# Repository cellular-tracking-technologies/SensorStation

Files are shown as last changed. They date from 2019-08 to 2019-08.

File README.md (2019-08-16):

# SensorStation

This repo contains the SensorStation schematics and CAD files. You can use this to assist with development, troubleshoot problems, or even create your own SensorStation.

If you are looking to purchased a fully assembled and tested SensorStation, complete with Raspberry Pi Compute module installed, visit: http://store.celltracktech.com/

# SensorStation Overview

The SensorStation is a powerful platform for transmitting and receiving information wirelessly, with multiple radio channels.

While its primary function is to collect data from wildlife telemetry devices, it can be used for any multi-channel wireless
application, including IoT, amateur radio, and building wireless networks.

The SensorStation offers the following features:

* Support for the Raspberry Pi Compute Module CM3+ (pre-programmed with SensorGnome if purchased from CTT)
* USB OTG switch allows for programming of Compute Module while directly connected to board
* GPS receiver with built in chip antenna, with RF switch for external antennas
* 5 radio channels with SMA connectors featuring the HopeRF footprint, making it compatible with VHF and UHF systems, such as LoRa or FSK, from 142-1000MHz and 2.4GHz
* Each radio is controlled by a dedicated Atmel AVR 32U4, featuring the Arduino bootloader, hardwired to the USB network
* Raspberry Pi compatible header for connecting accessories, such as the InkyPhat eInk screen and more
* 4 directional buttons
* 2 status indication LEDs controlled by GPIO
* 3 I2C accessory ports, with dedicated GPIO per port
* Multi-channel ADC, for measuring system voltages, temperature, light levels, battery voltage, solar voltage, and additional channels broken out
* DS3231 real time clock with extreme accuracy along with coin cell slot
* Composite video output
* Wide range DC power input from 8-24VDC
* 6 USB 2.0 ports, each with dedicated transaction translator, typically used for Software Defined Radio (SDR)
* SIM800C quad band GSM modem
* eSIM (SIM on chip), soldered on if purchased from CTT (requires data plan)

# SensorStation Acessories

Also available for a variety of SensorStation accessories. You can even build your own. Check our our SensorStation Acessory Template to learn more.

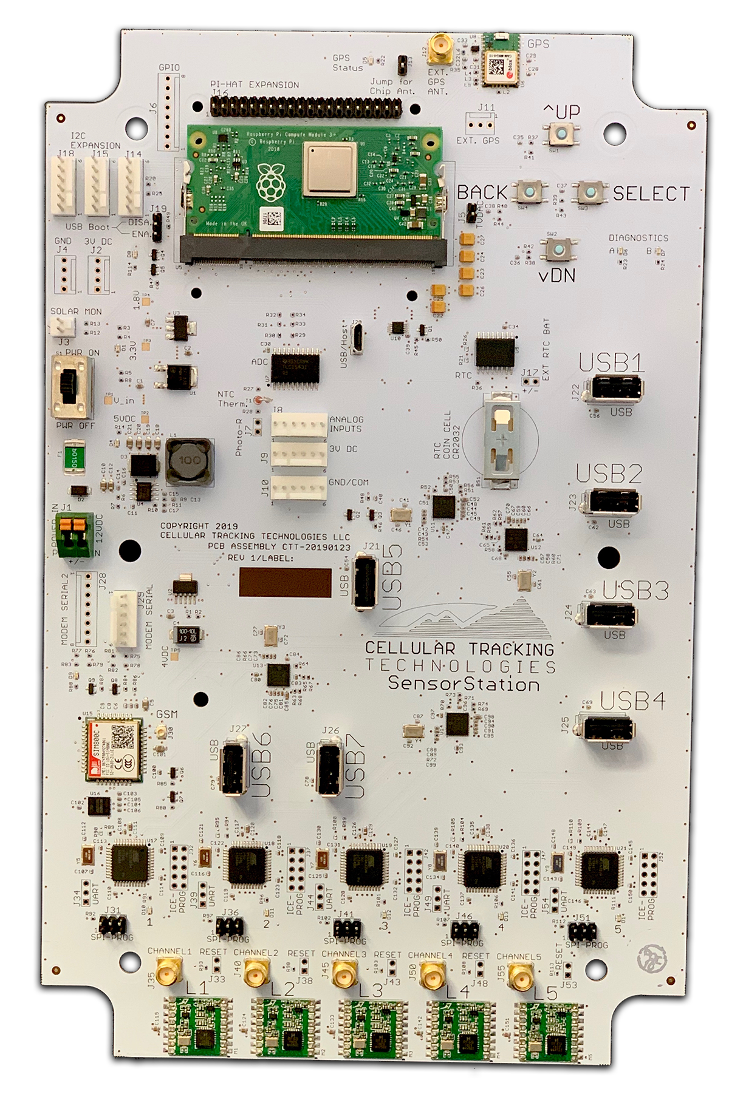
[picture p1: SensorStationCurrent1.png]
SensorStation


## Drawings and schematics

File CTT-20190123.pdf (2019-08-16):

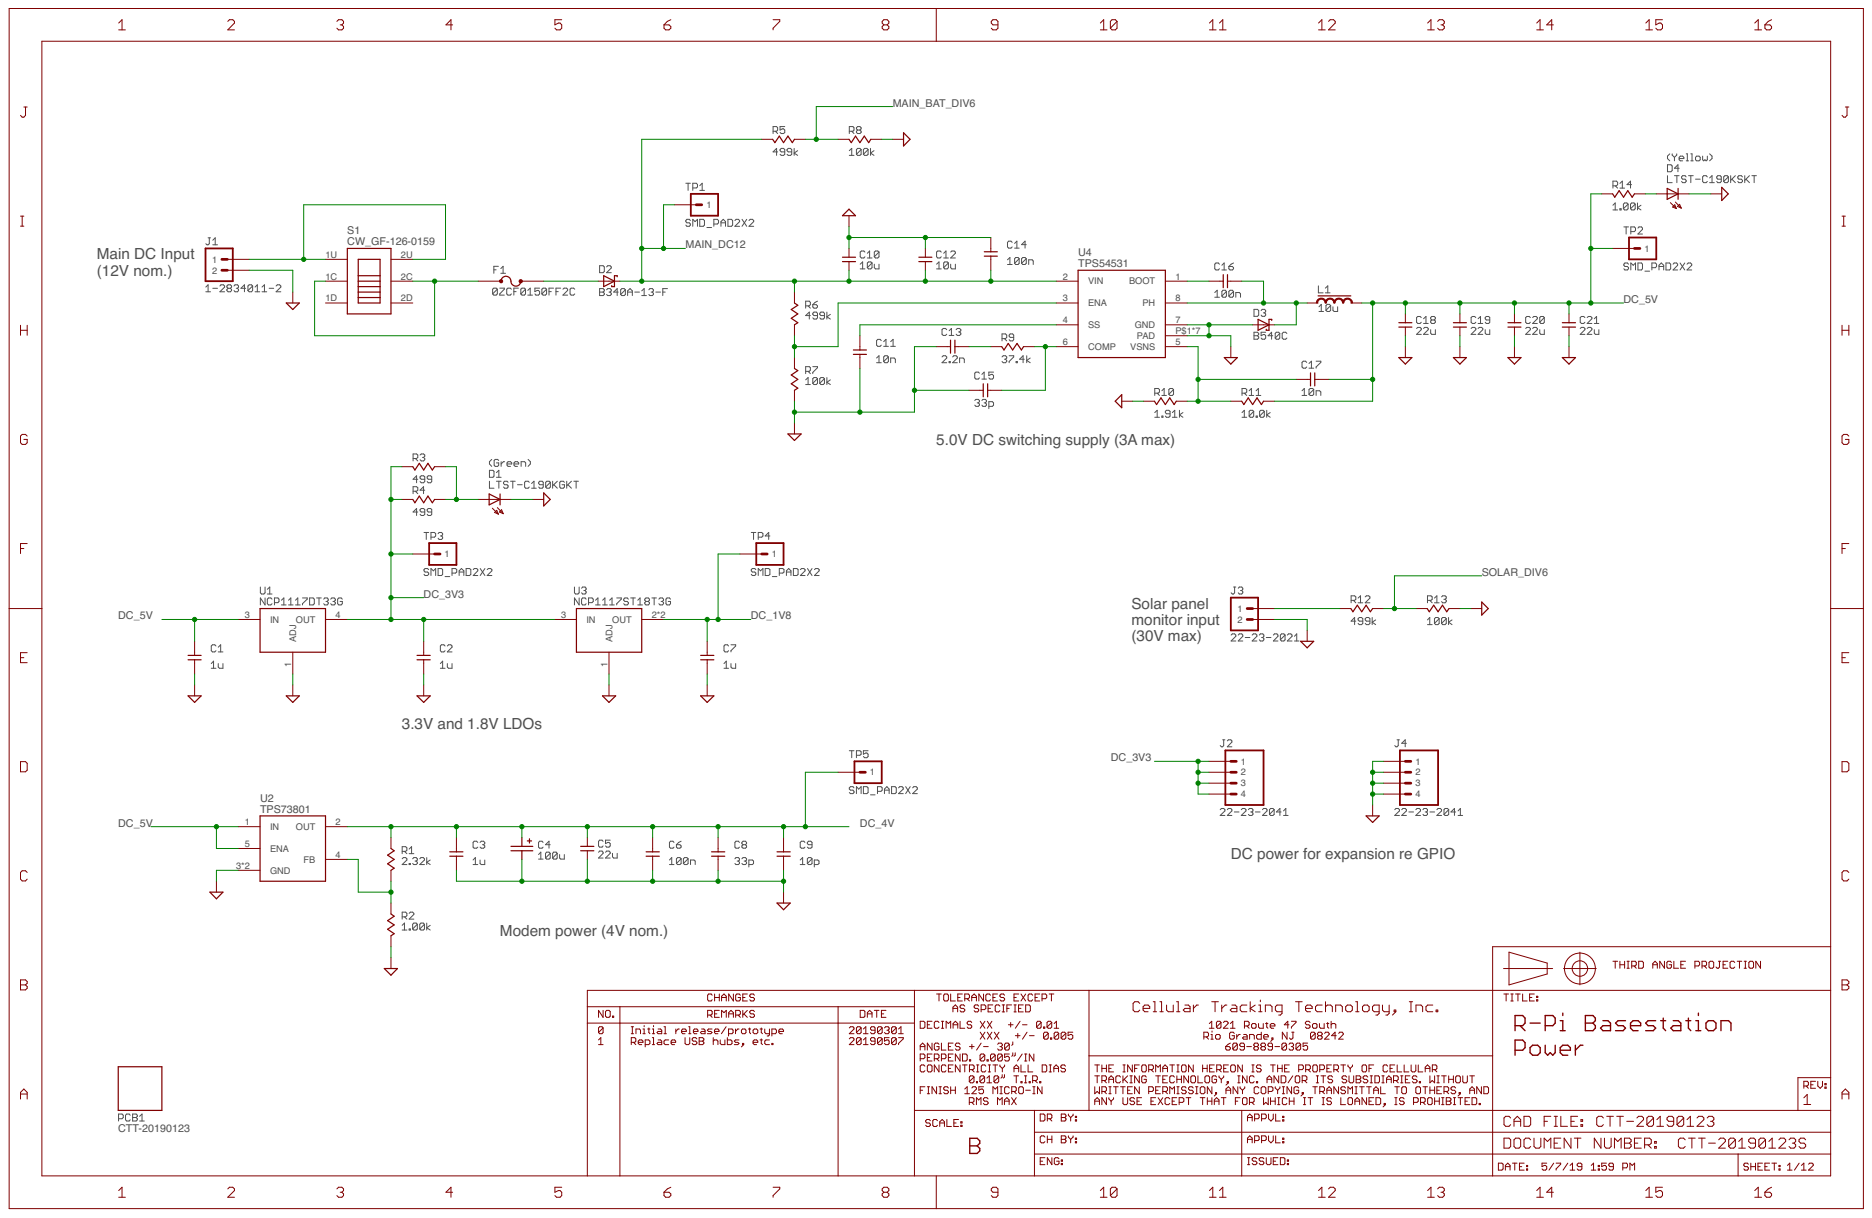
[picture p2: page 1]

Main DC Input (12V nom.)

5.0V DC switching supply (3A max)

Solar panel monitor input (30V max)

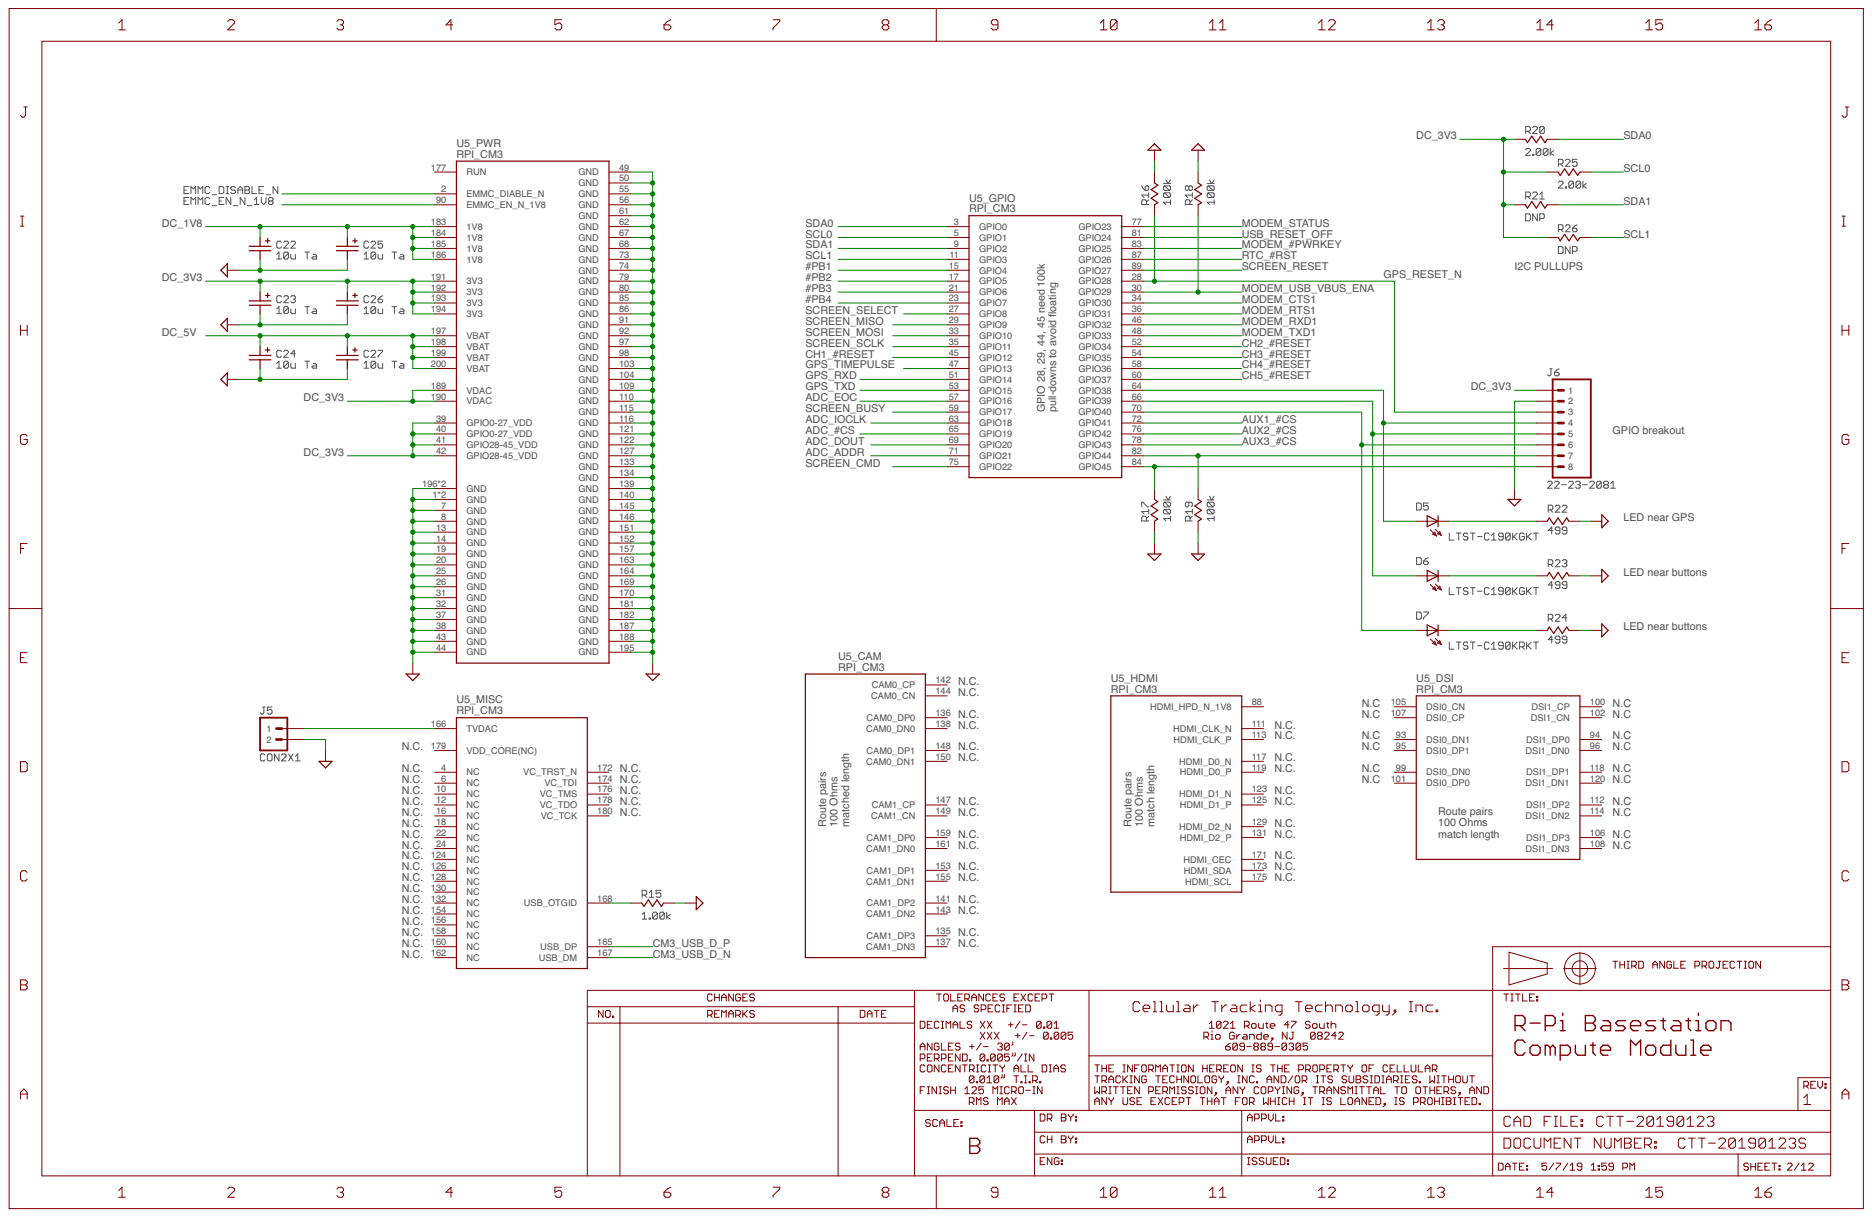
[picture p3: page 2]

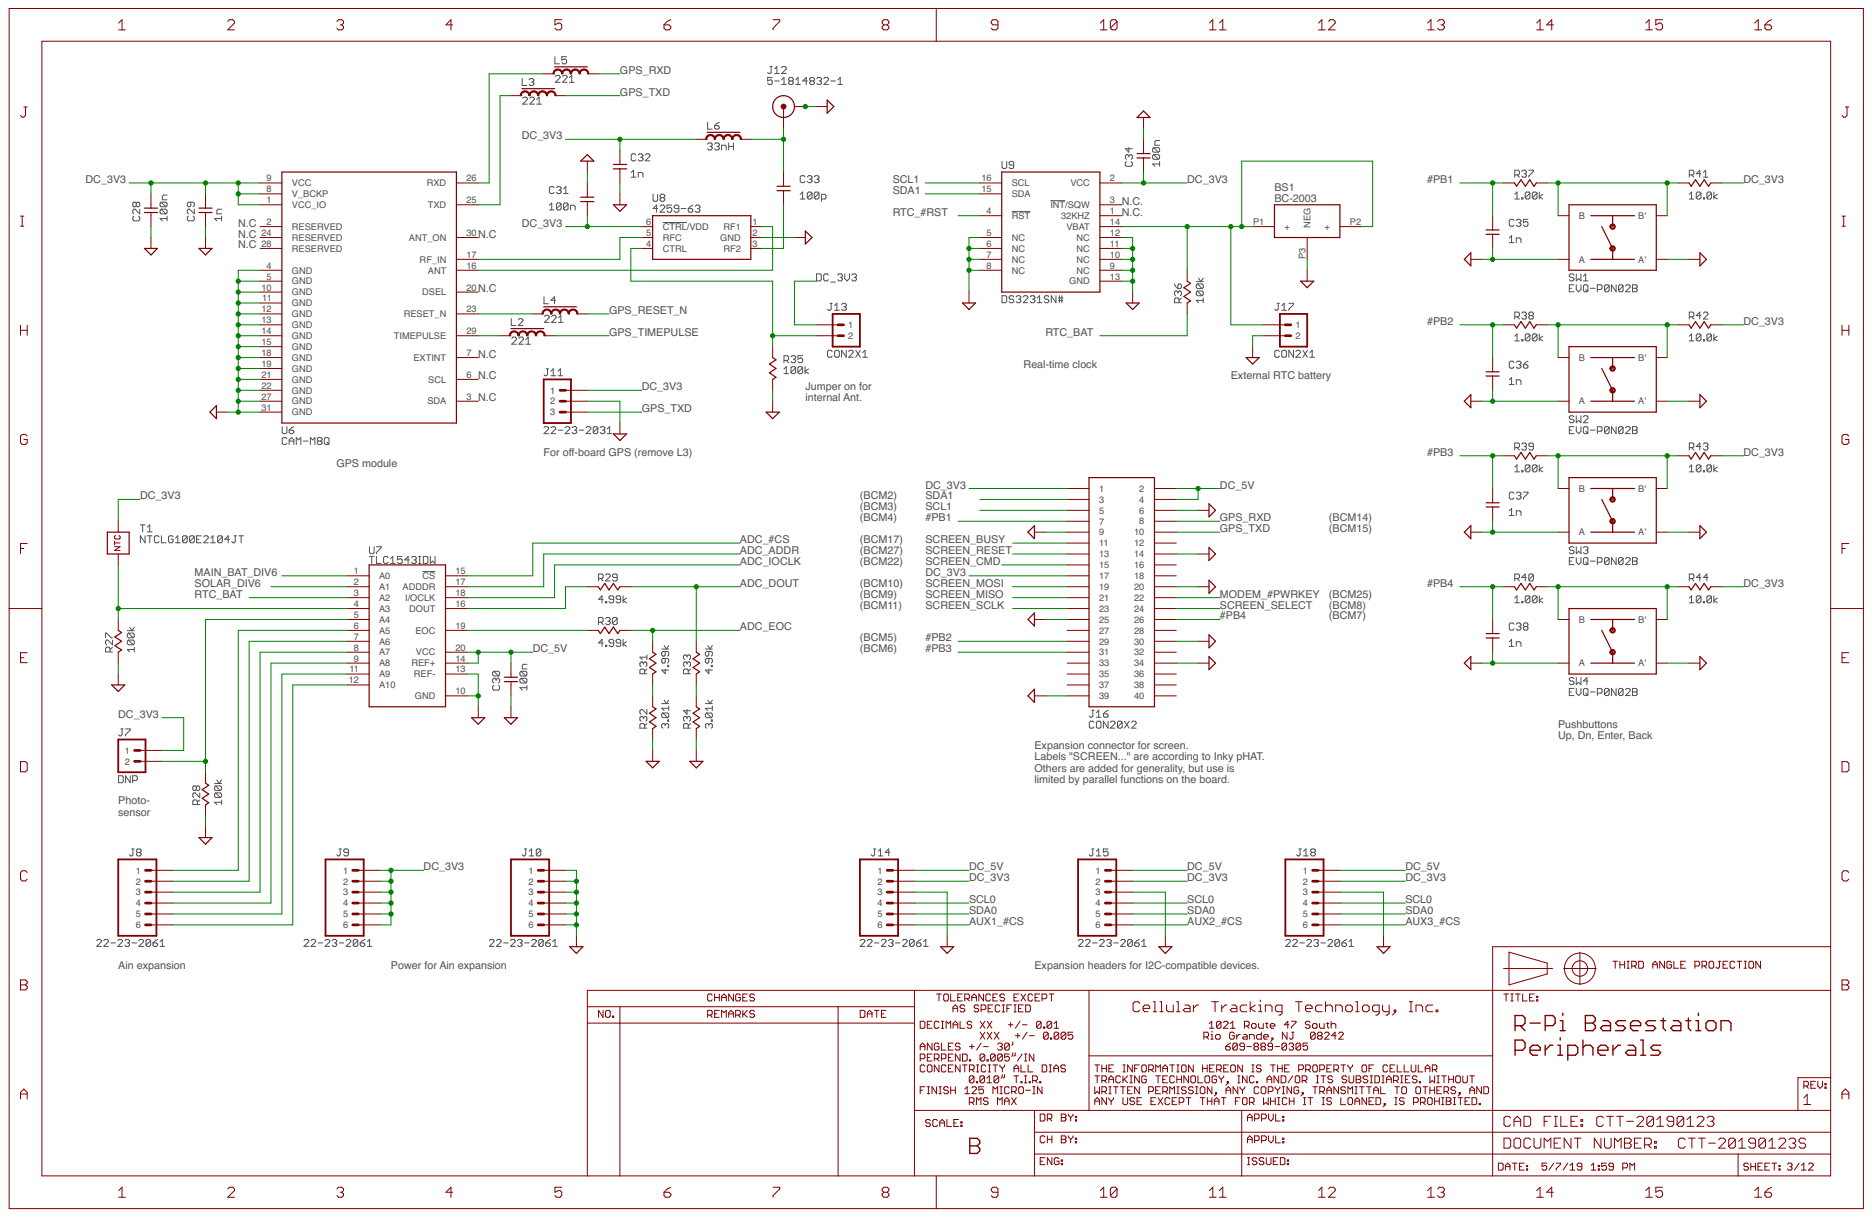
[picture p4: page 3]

For off-board GPS (remove L3) GPS module

Pushbuttons Up, Dn, Enter, Back

Expansion connector for screen. Labels "SCREEN..." are according to Inky pHAT. Others are added for generality, but use is

limited by parallel functions on the board.

Expansion headers for I2C-compatible devices.

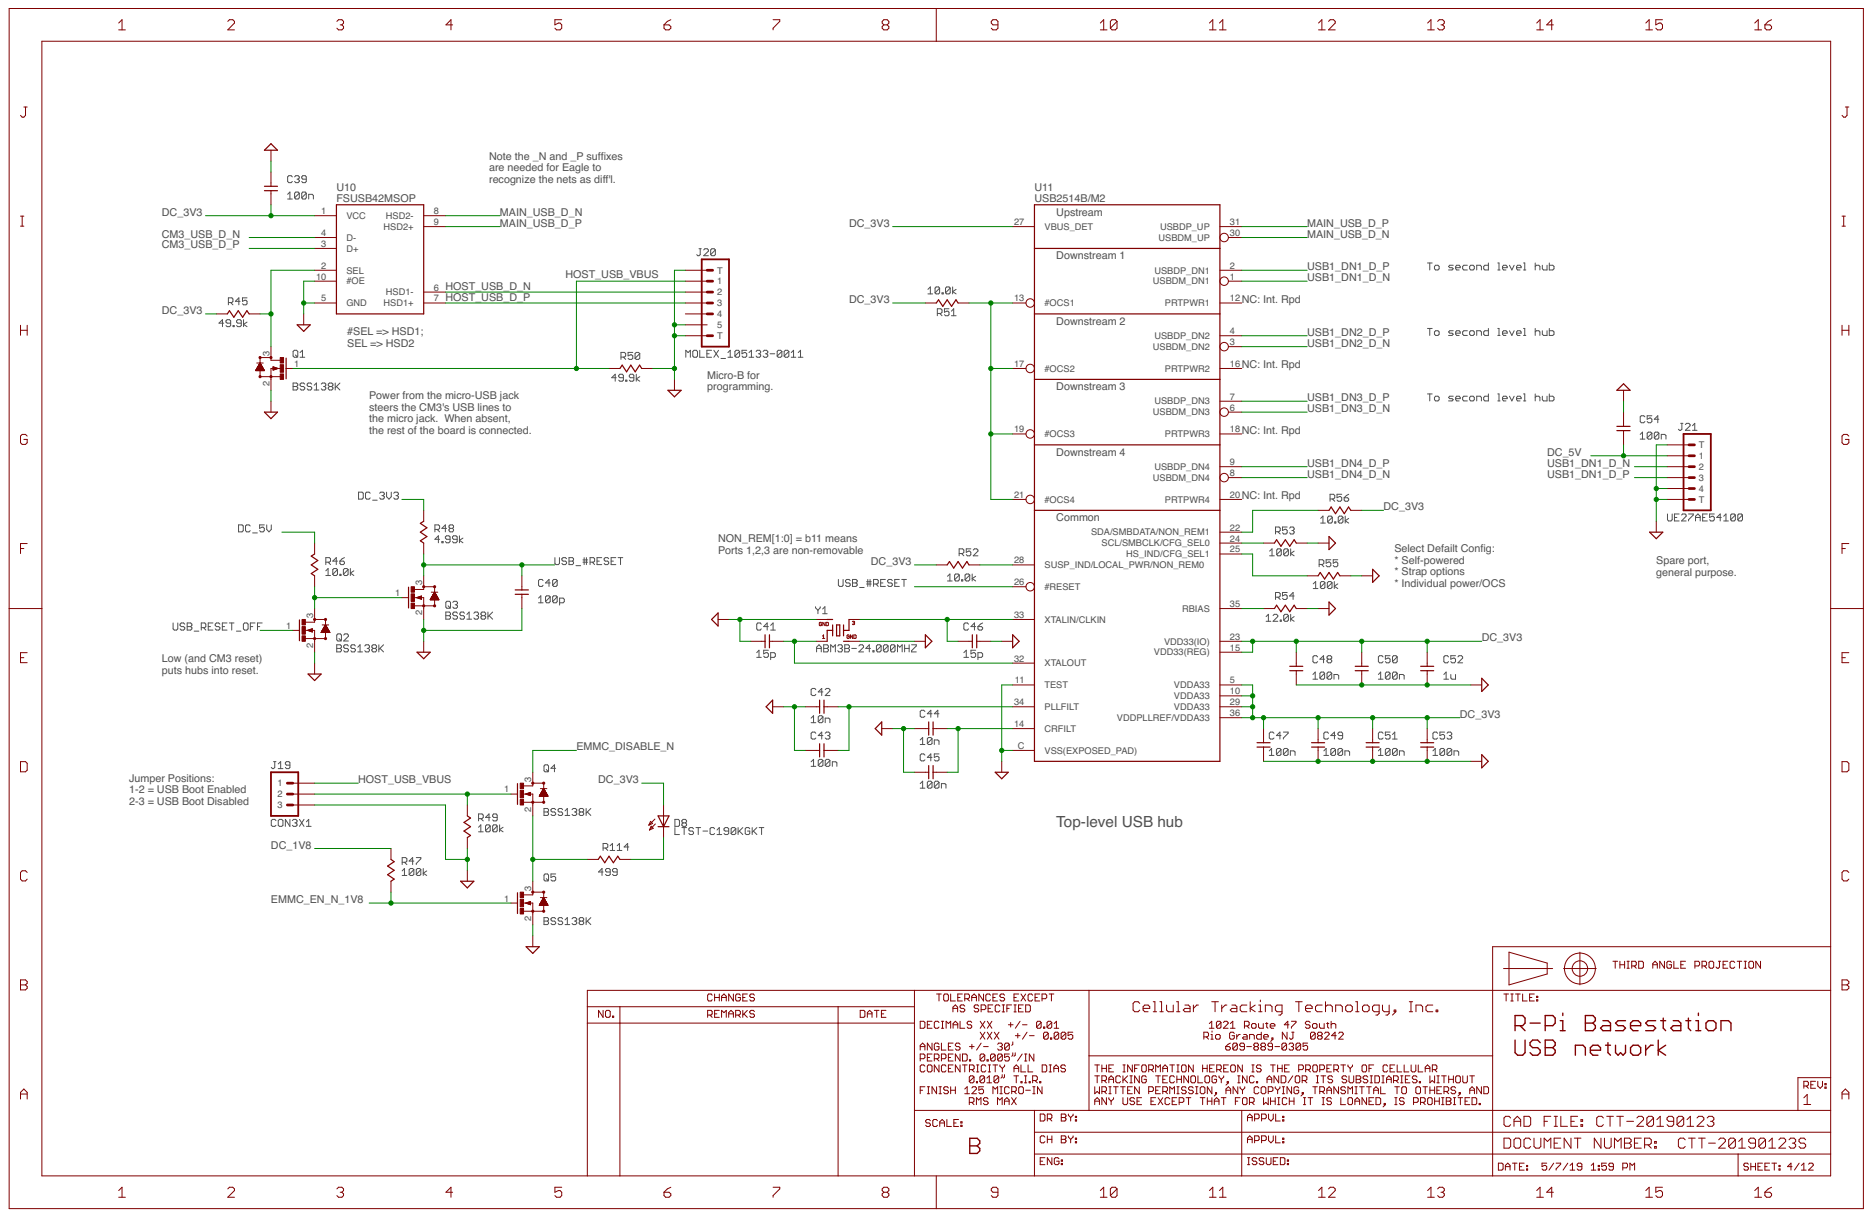
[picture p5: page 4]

Note the _N and _P suffixes are needed for Eagle to

Power from the micro-USB jack
steers the CM3's USB lines to
the micro jack. When absent,
the rest of the board is connected.

* Individual power/OCS NON_REM[1:0] = b11 means Ports 1,2,3 are non-removable

Spare port, general purpose.

Low (and CM3 reset) puts hubs into reset.

Jumper Positions: 1-2 = USB Boot Enabled

Top-level USB hub

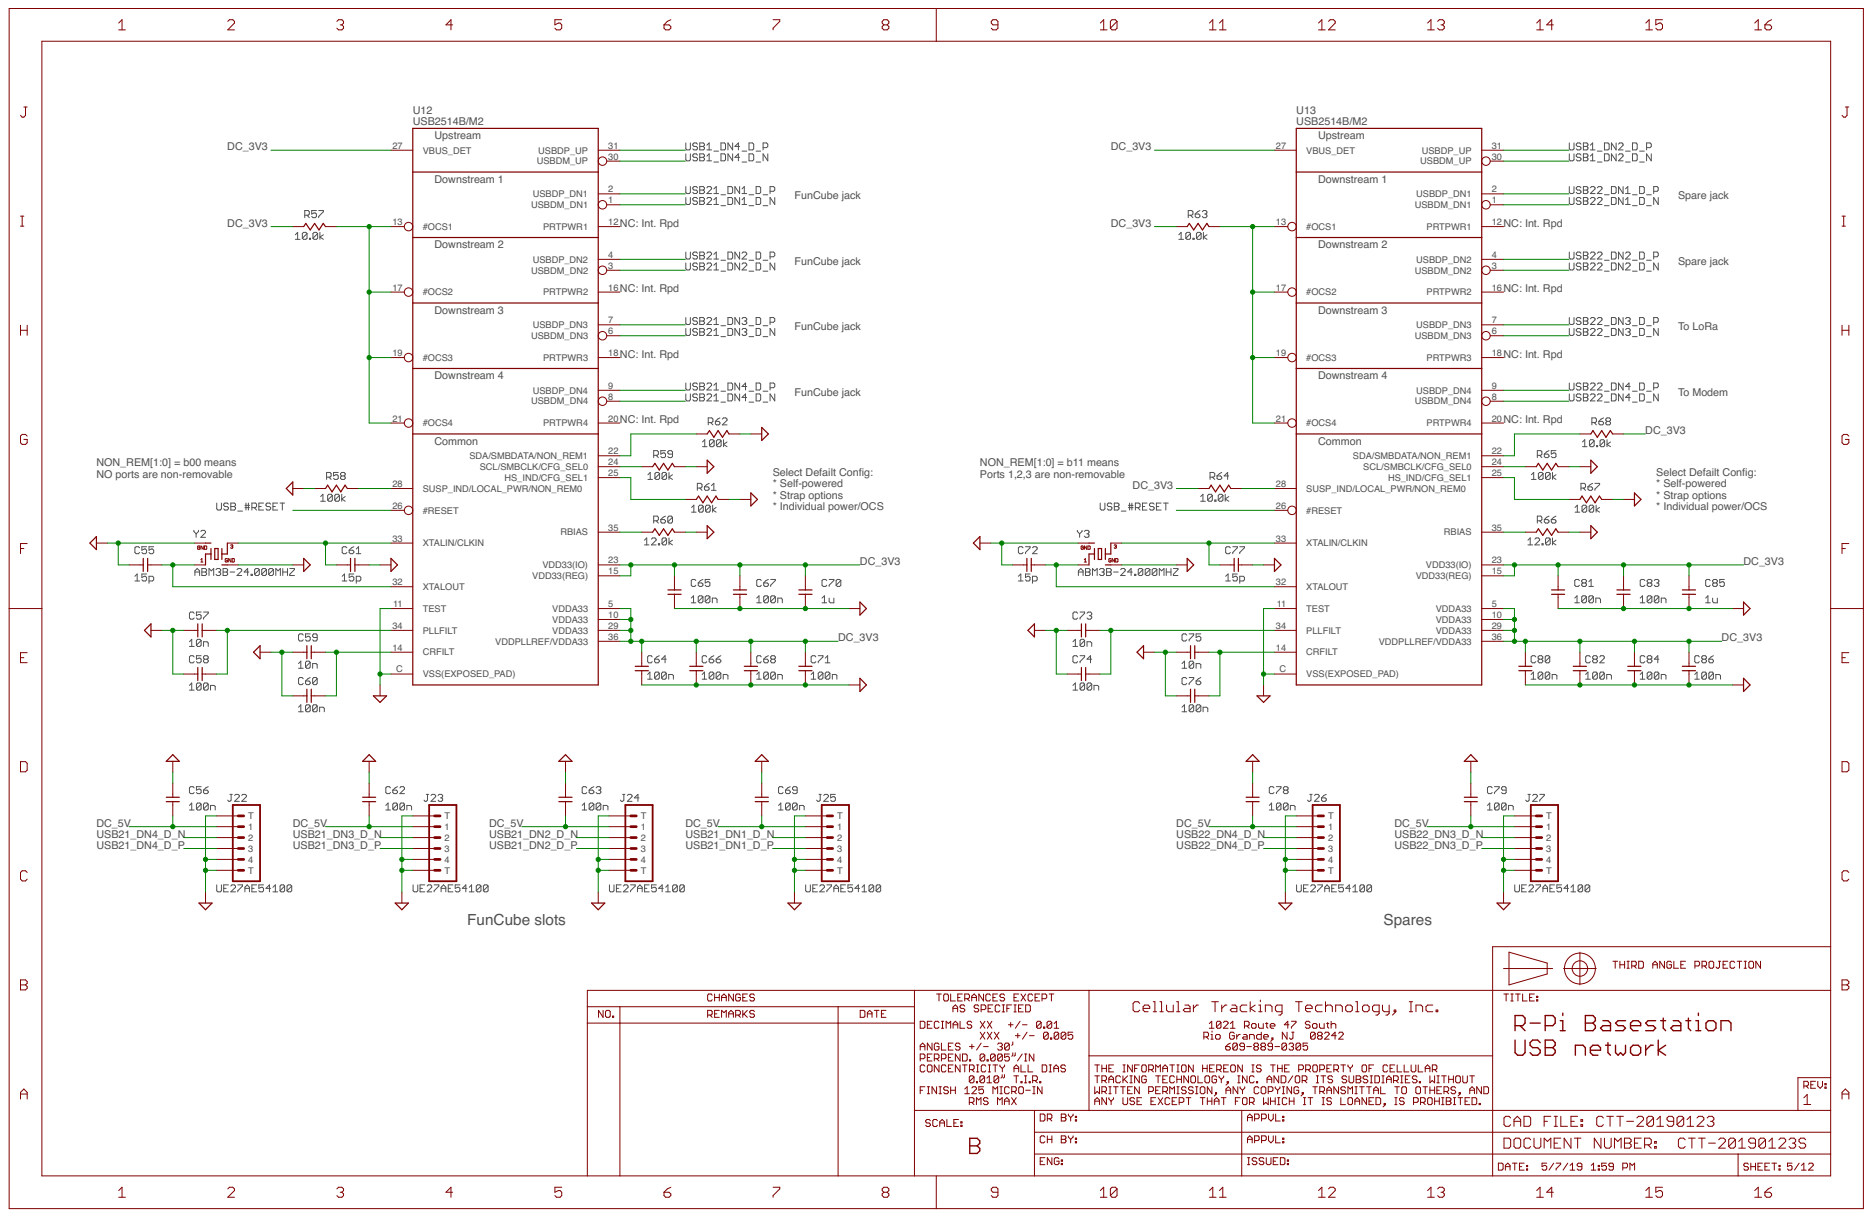
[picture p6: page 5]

Downstream 1 Downstream 2 Downstream 3 Downstream 4

* Individual power/OCS NON_REM[1:0] = b00 means NO ports are non-removable

* Individual power/OCS NON_REM[1:0] = b11 means Ports 1,2,3 are non-removable

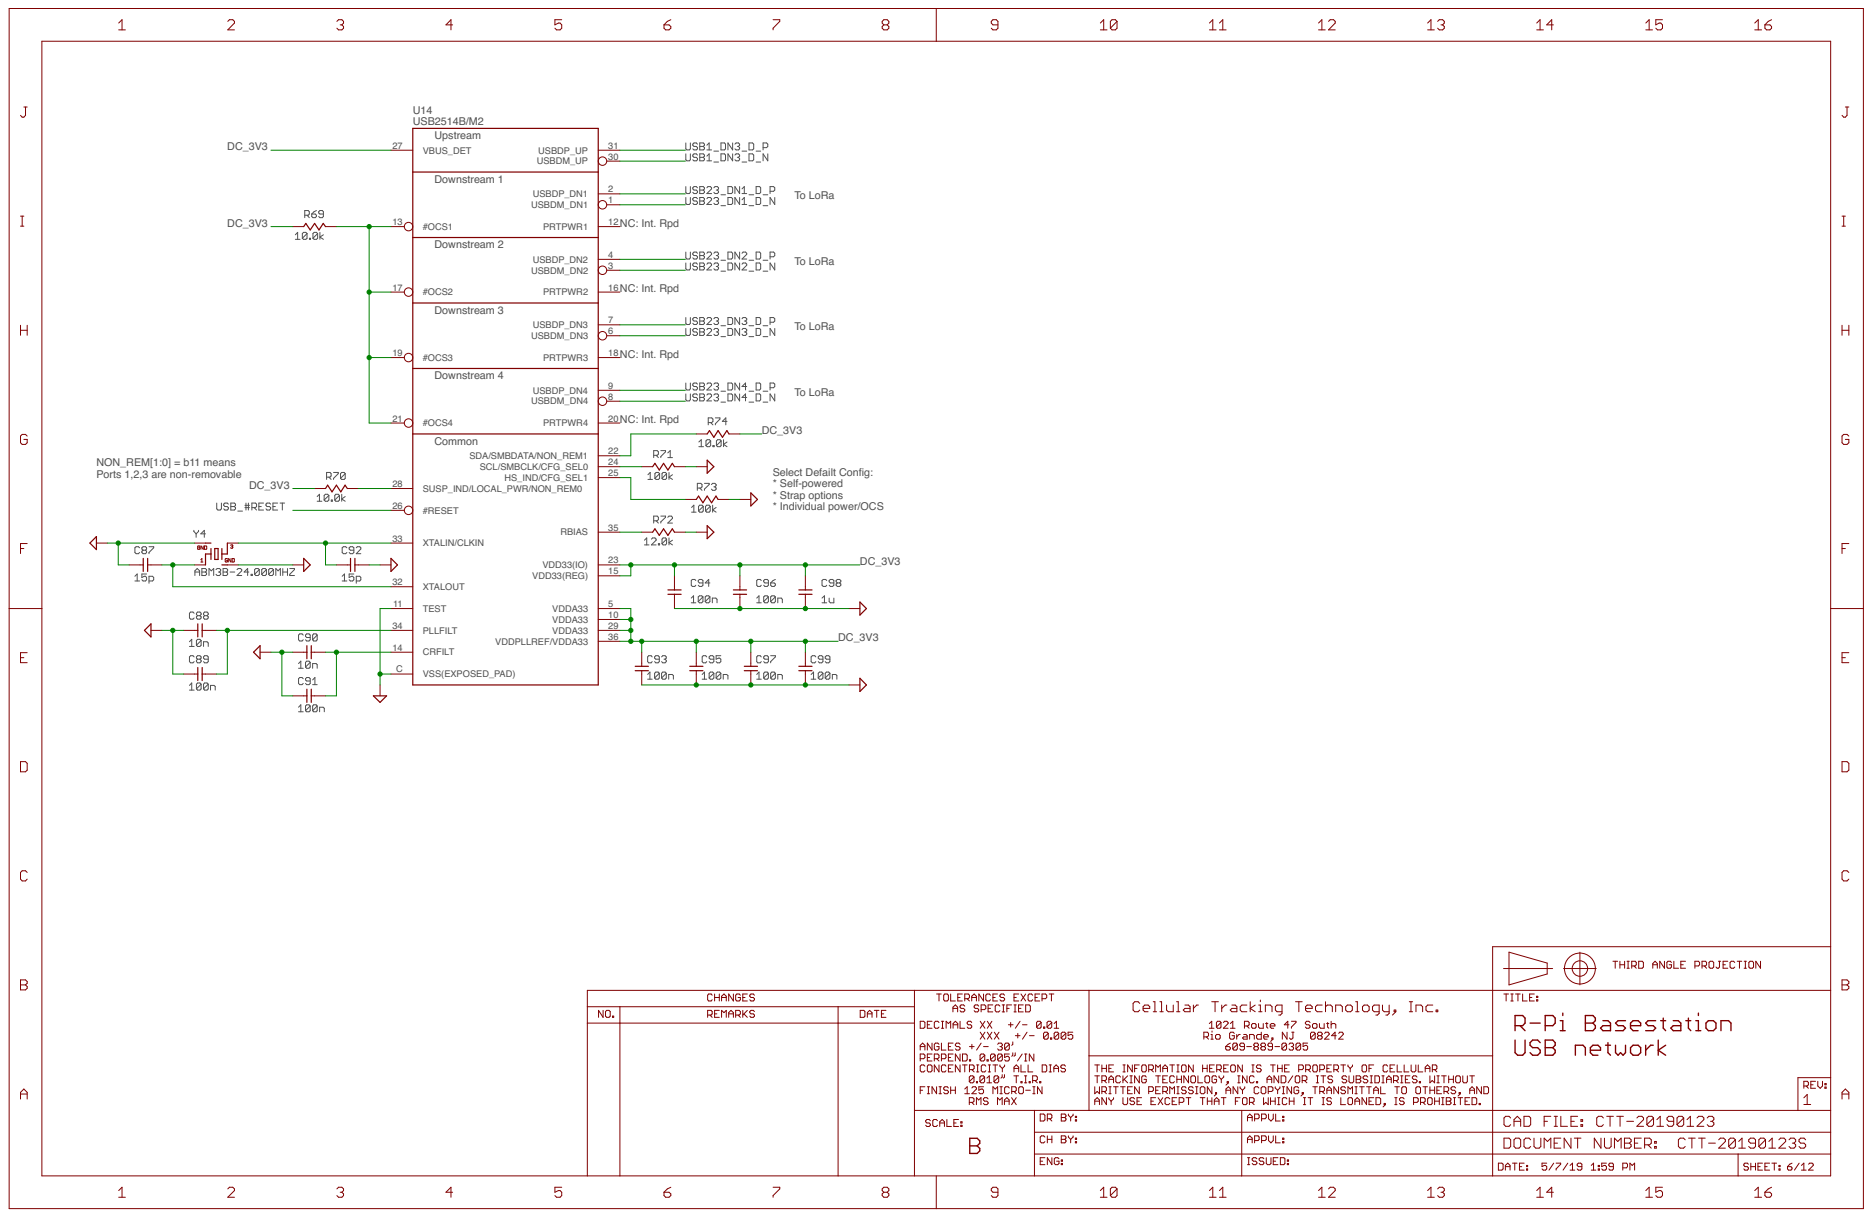
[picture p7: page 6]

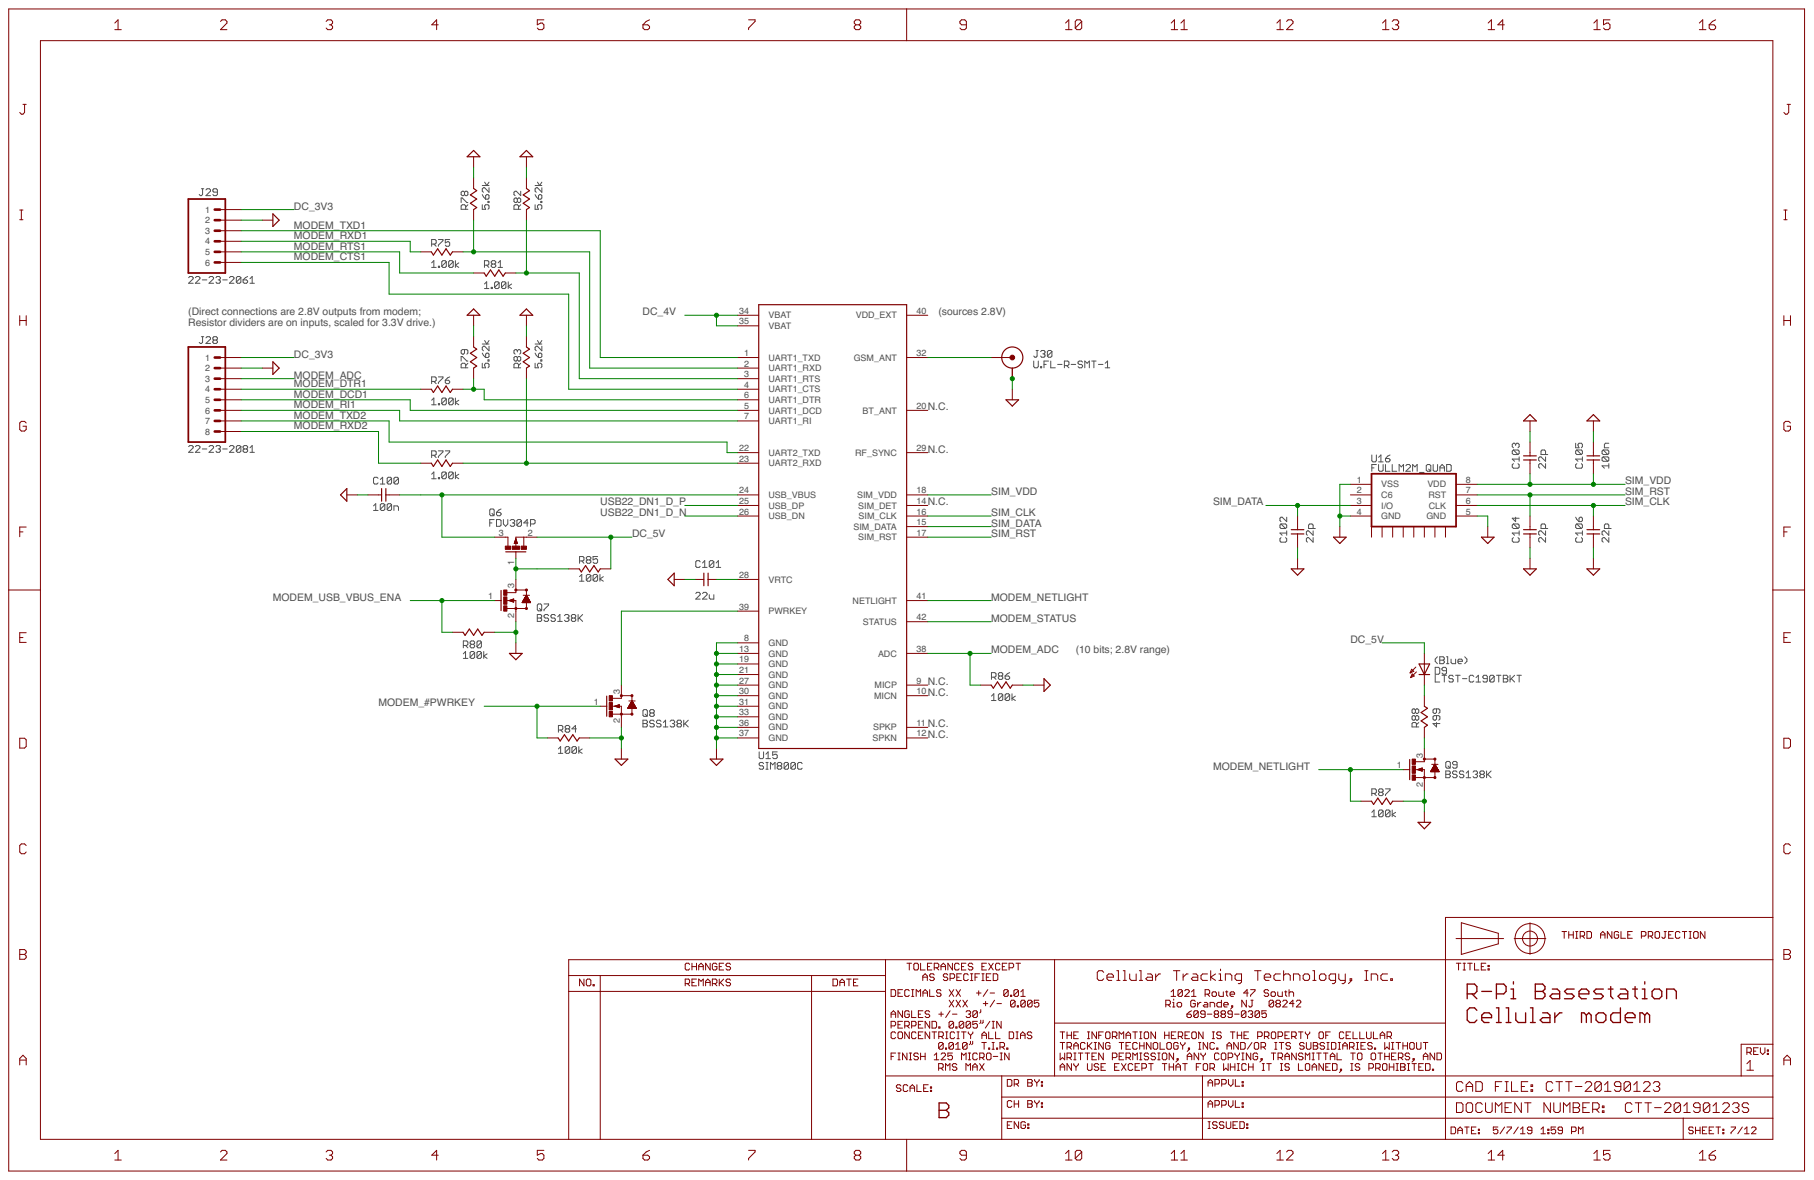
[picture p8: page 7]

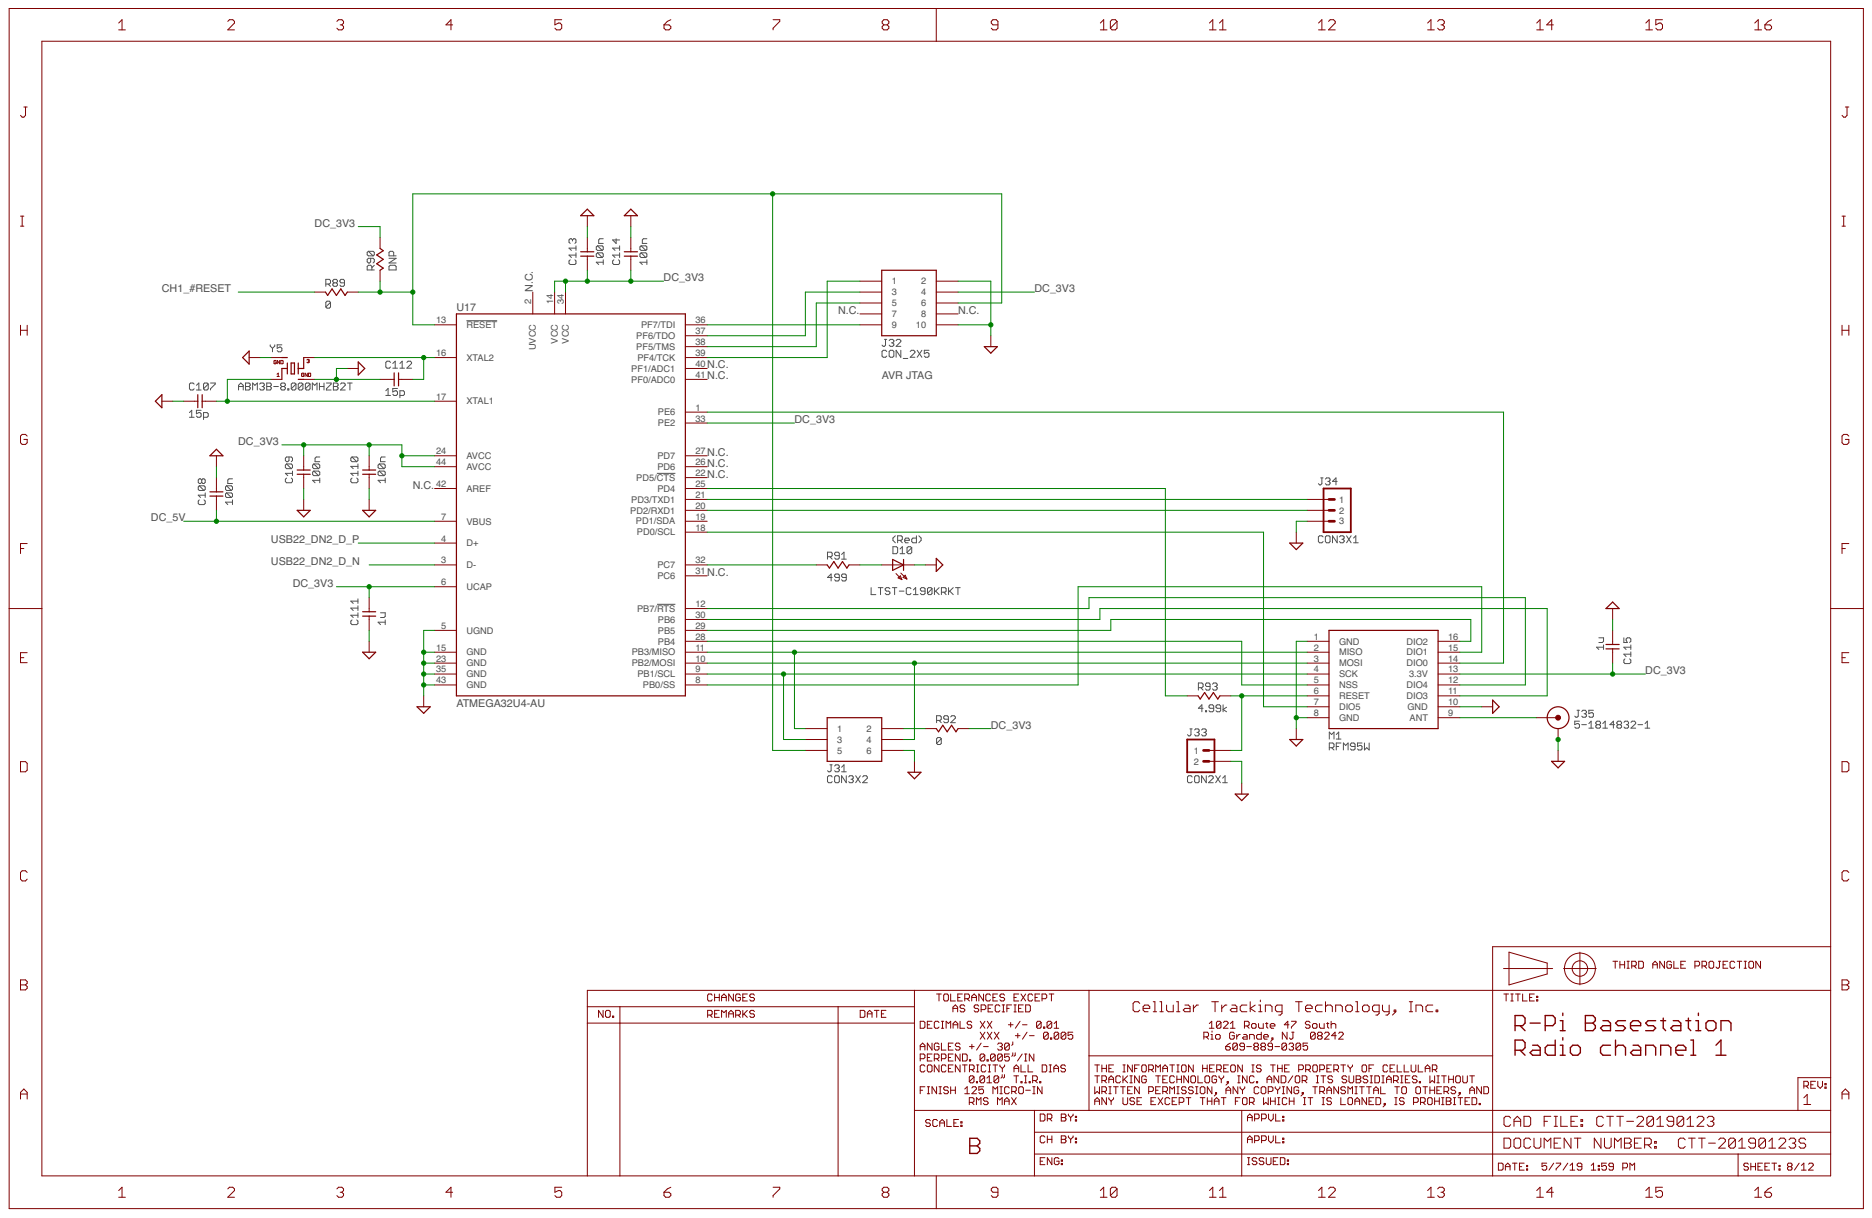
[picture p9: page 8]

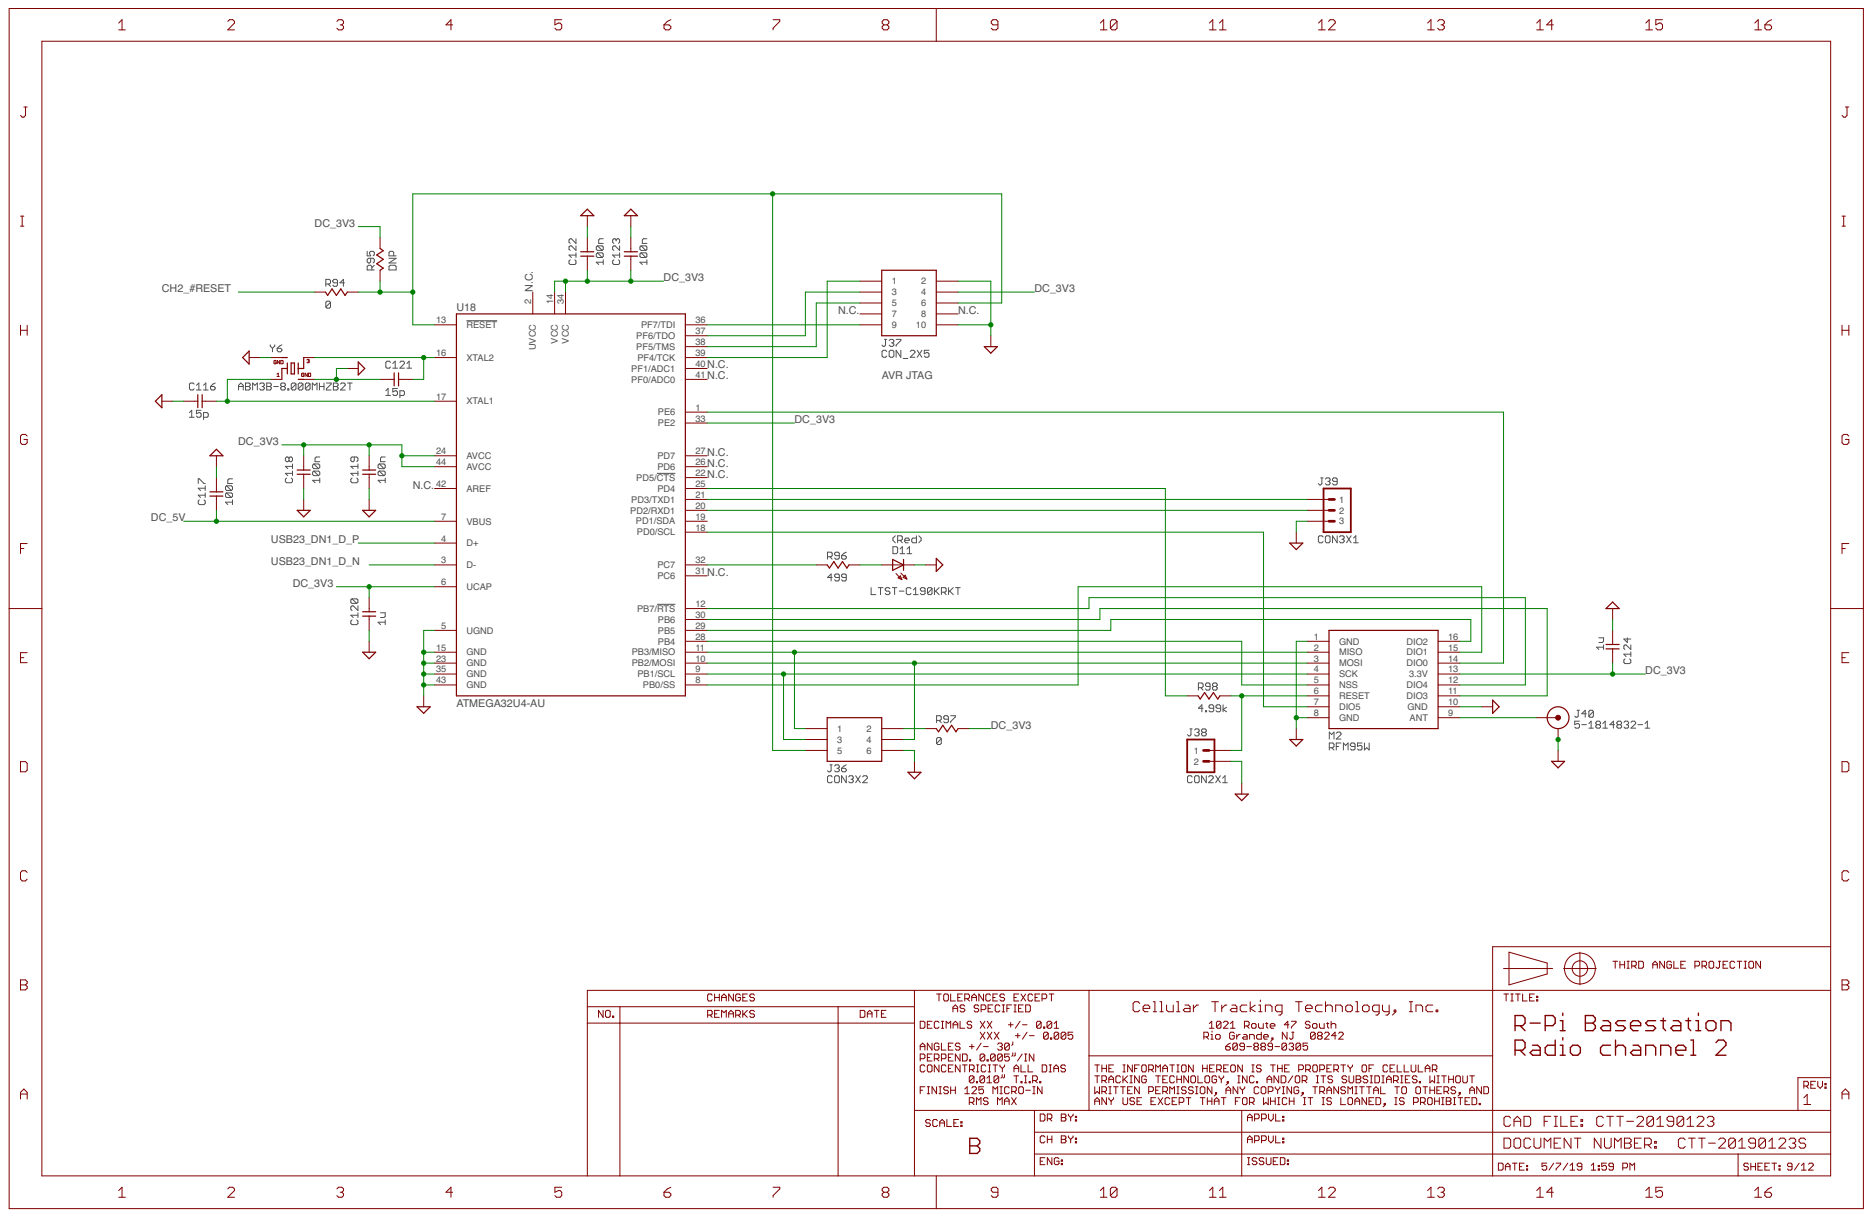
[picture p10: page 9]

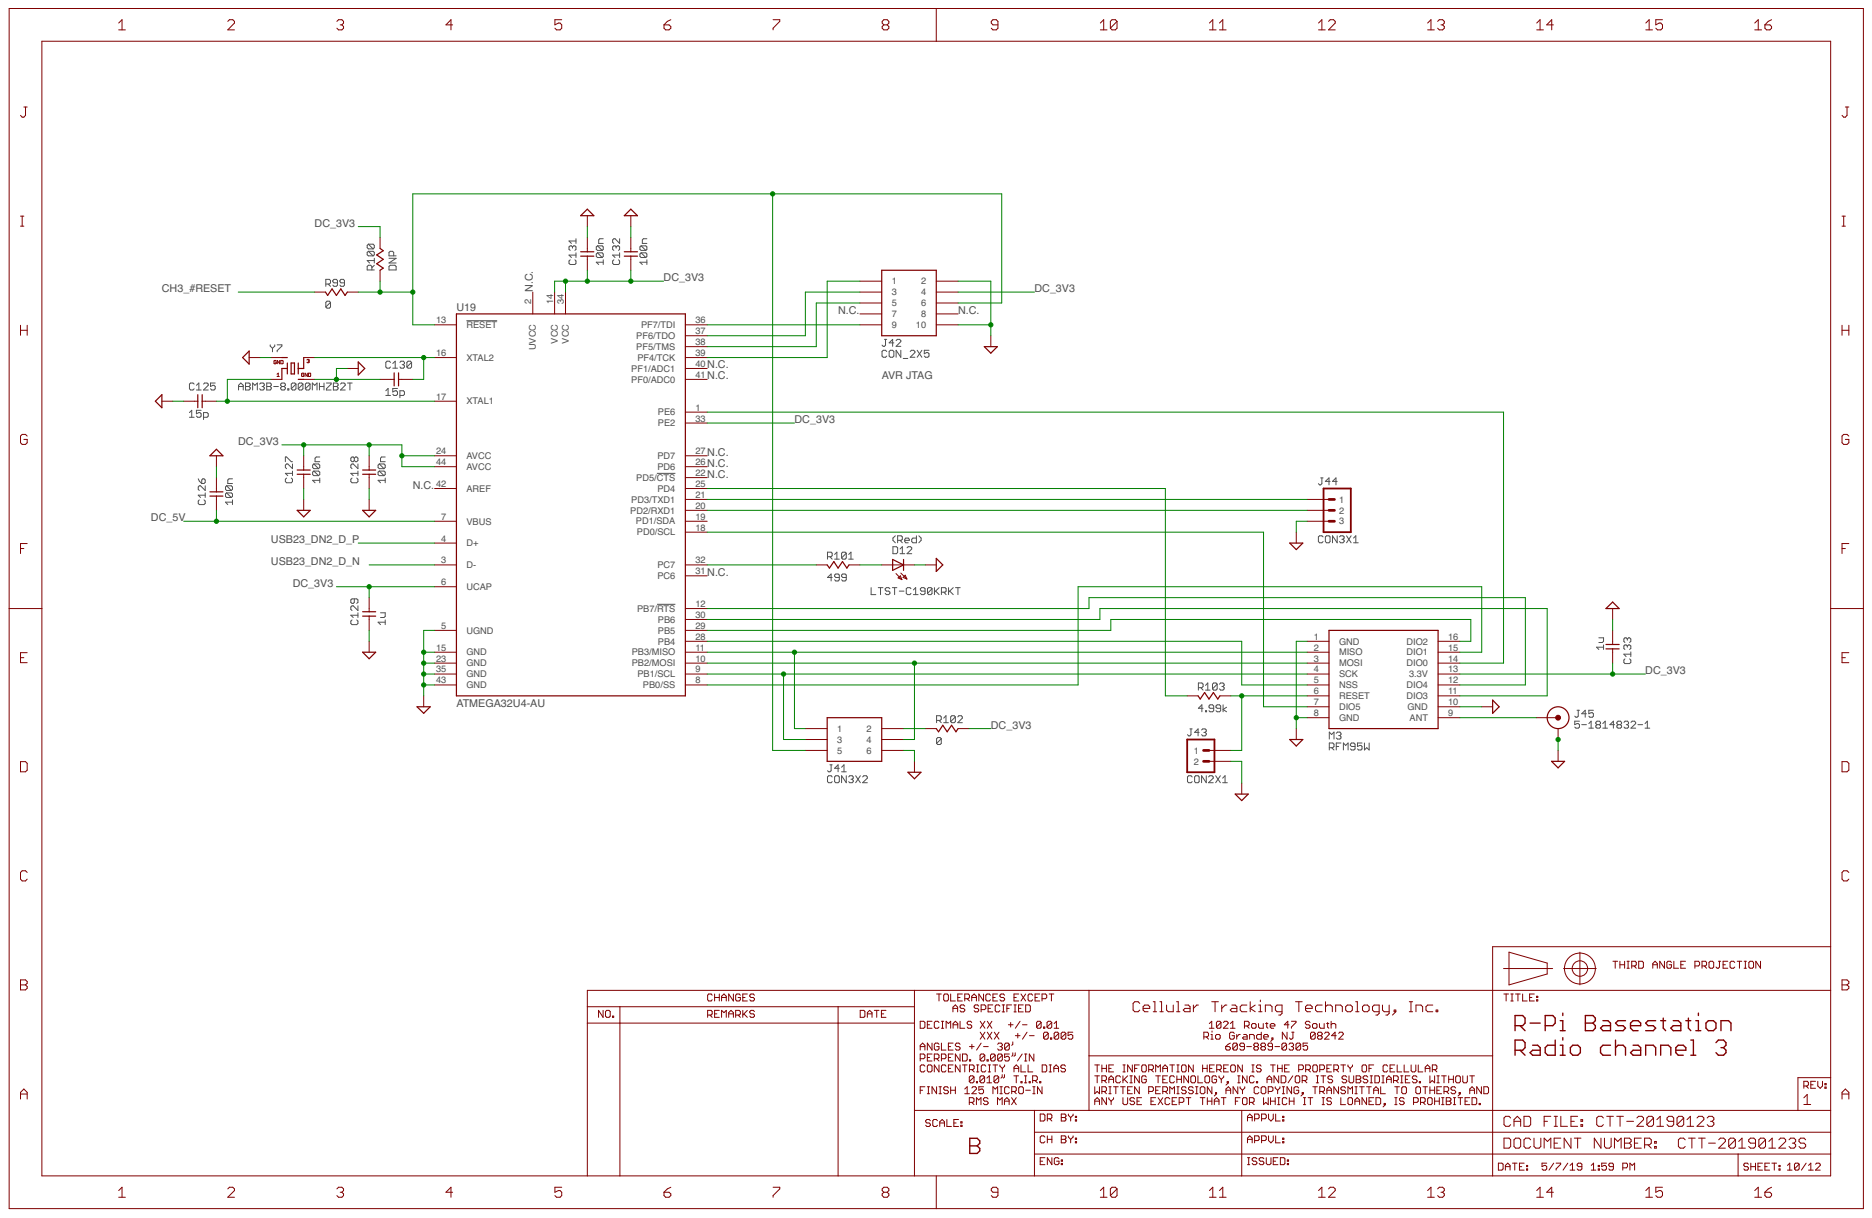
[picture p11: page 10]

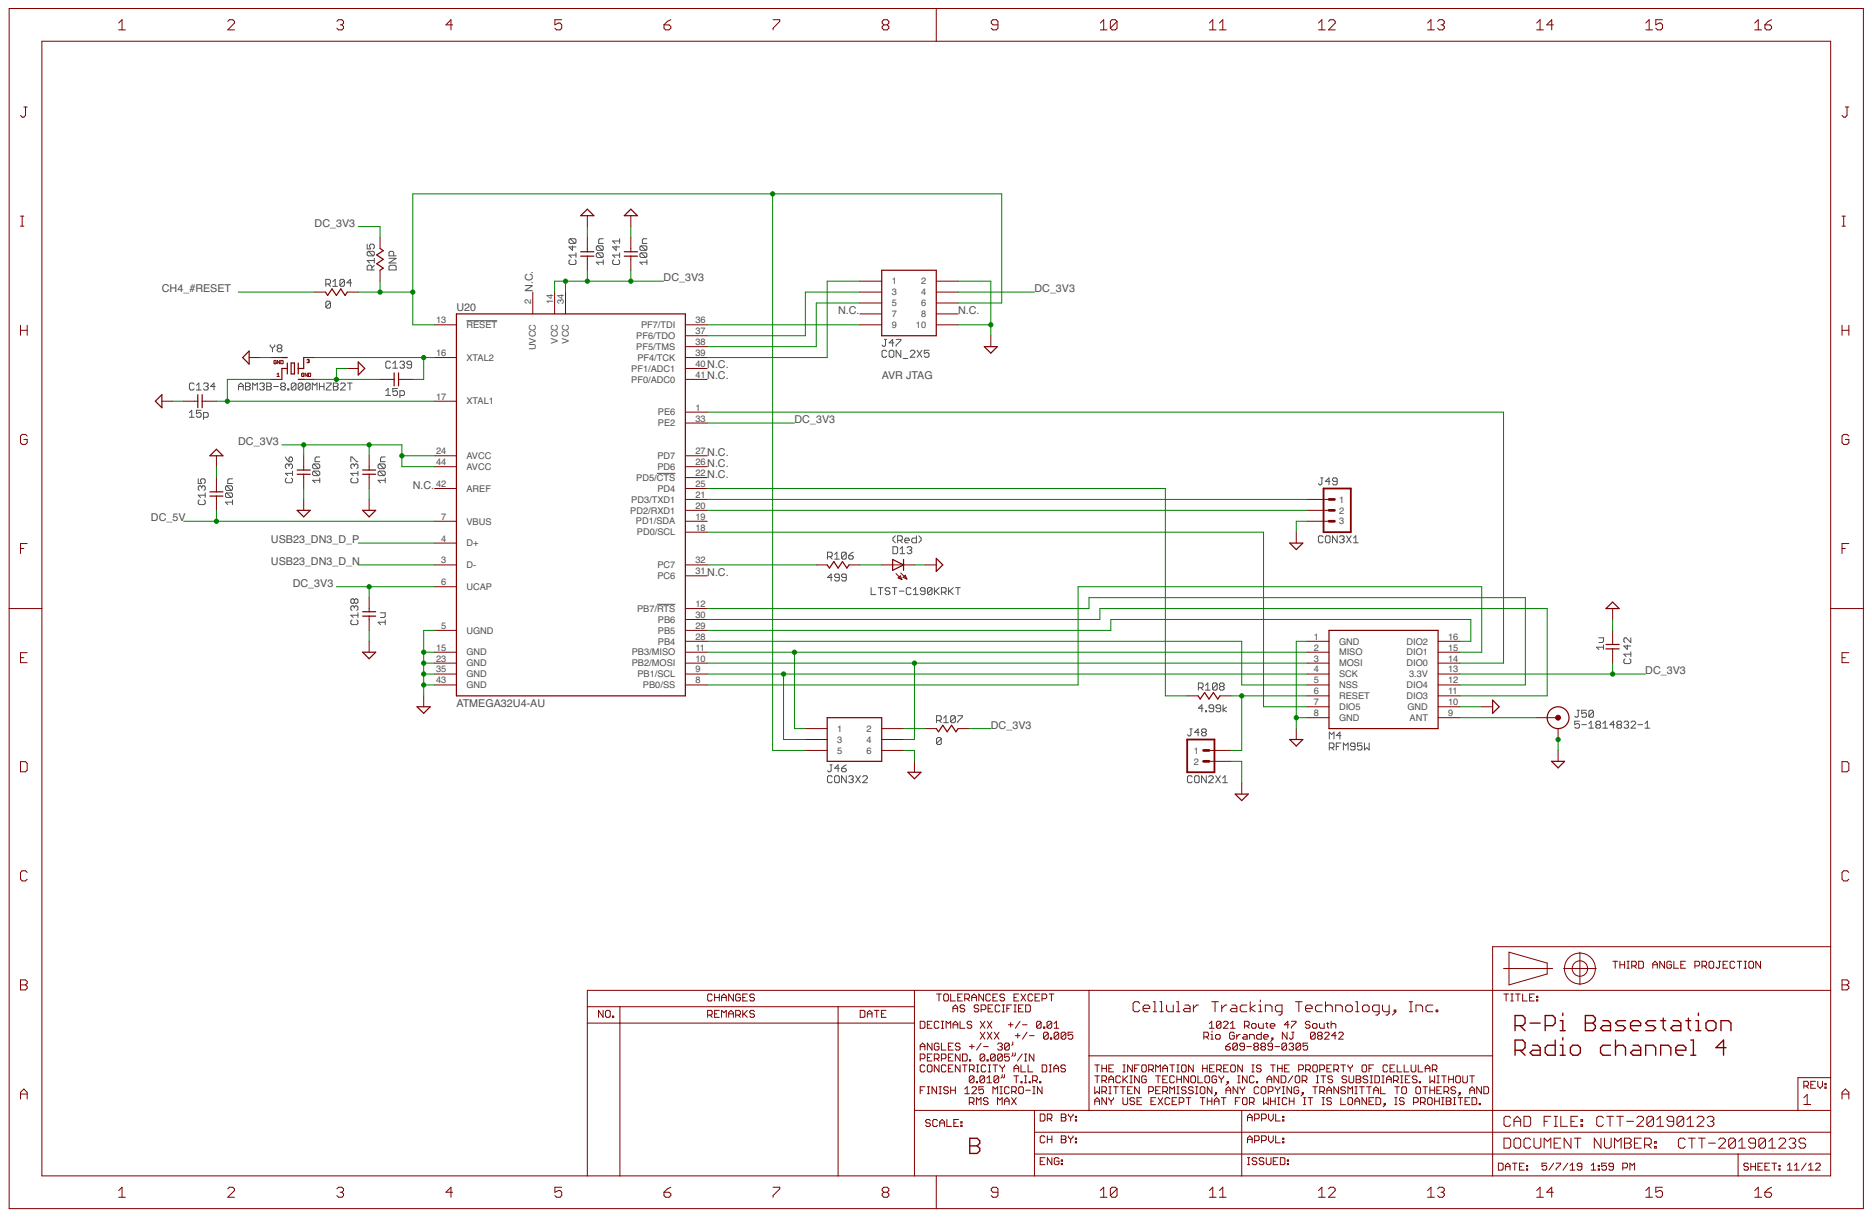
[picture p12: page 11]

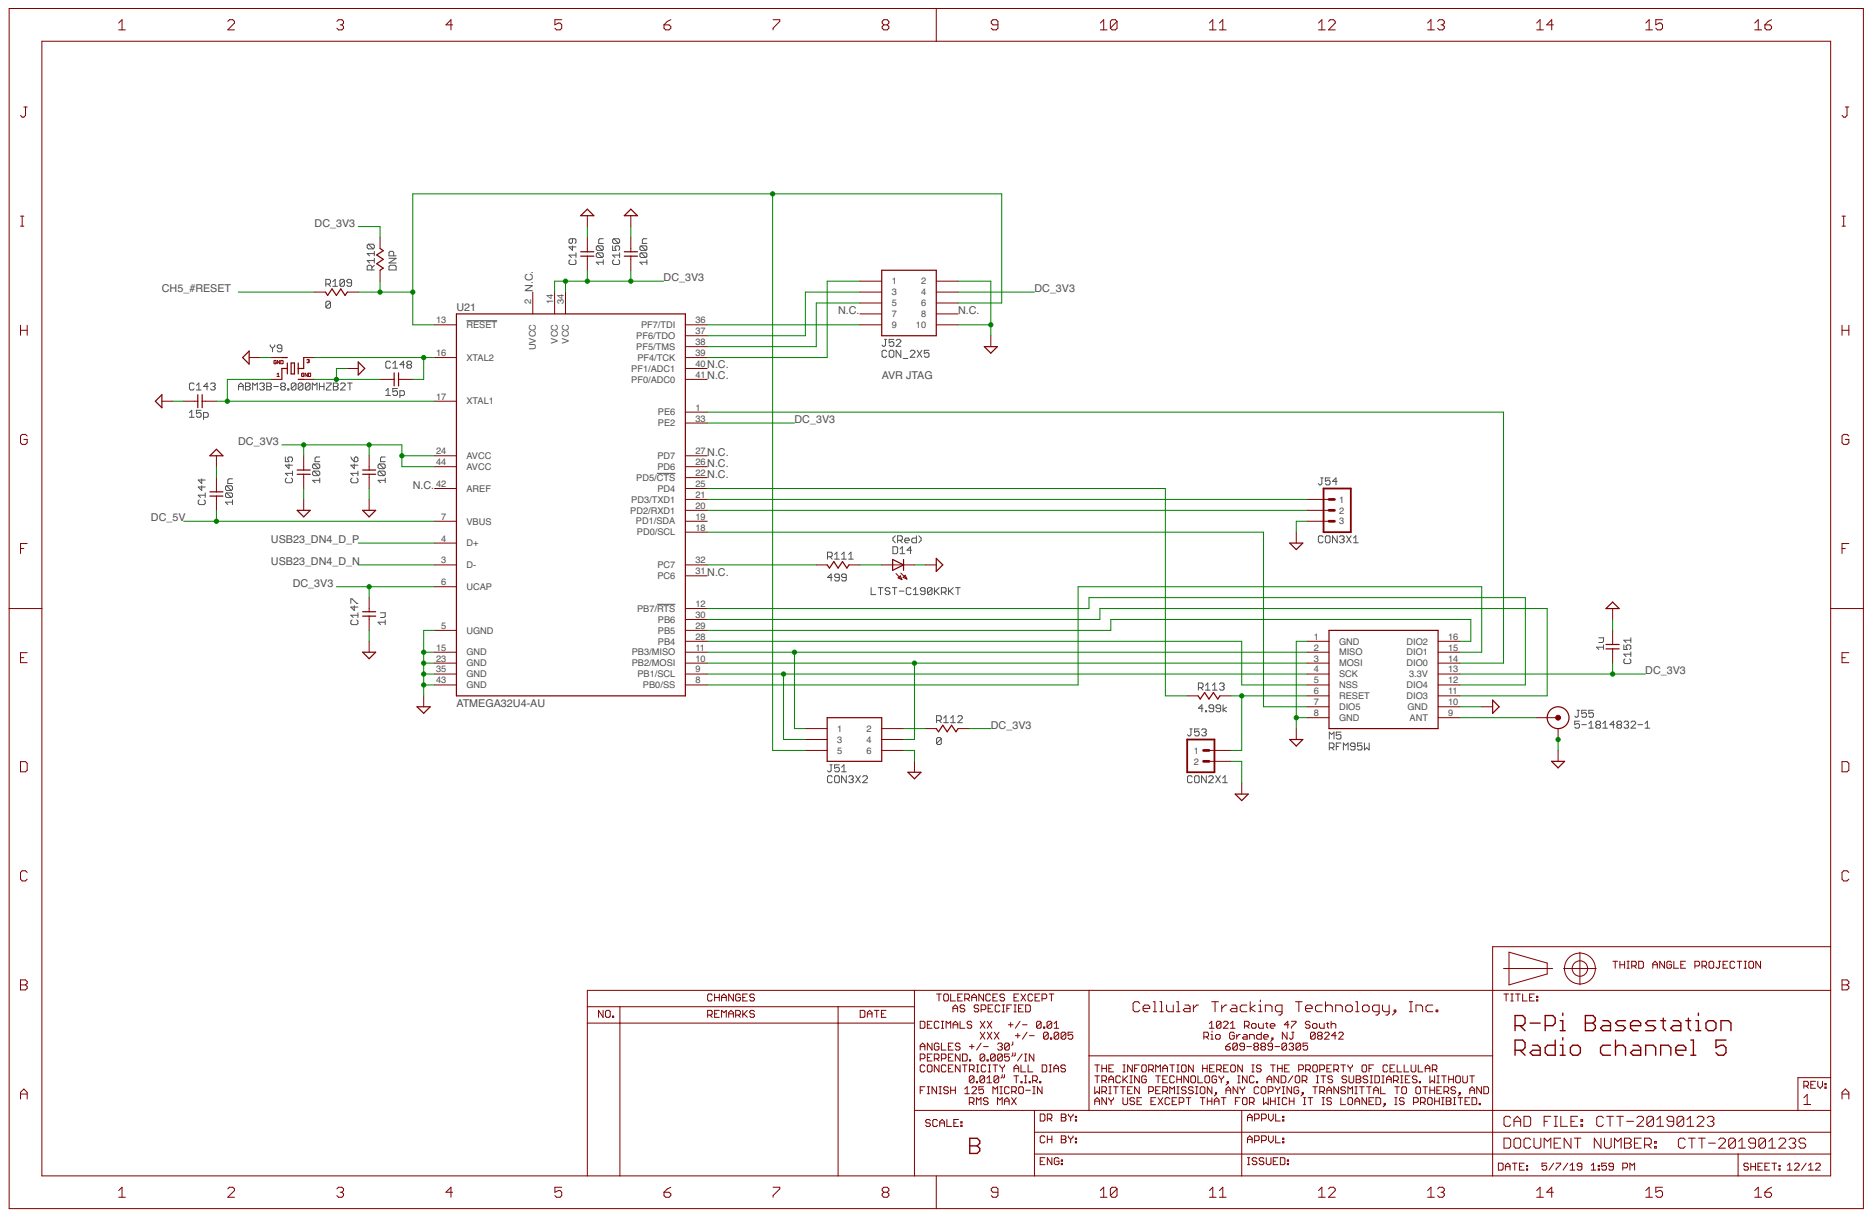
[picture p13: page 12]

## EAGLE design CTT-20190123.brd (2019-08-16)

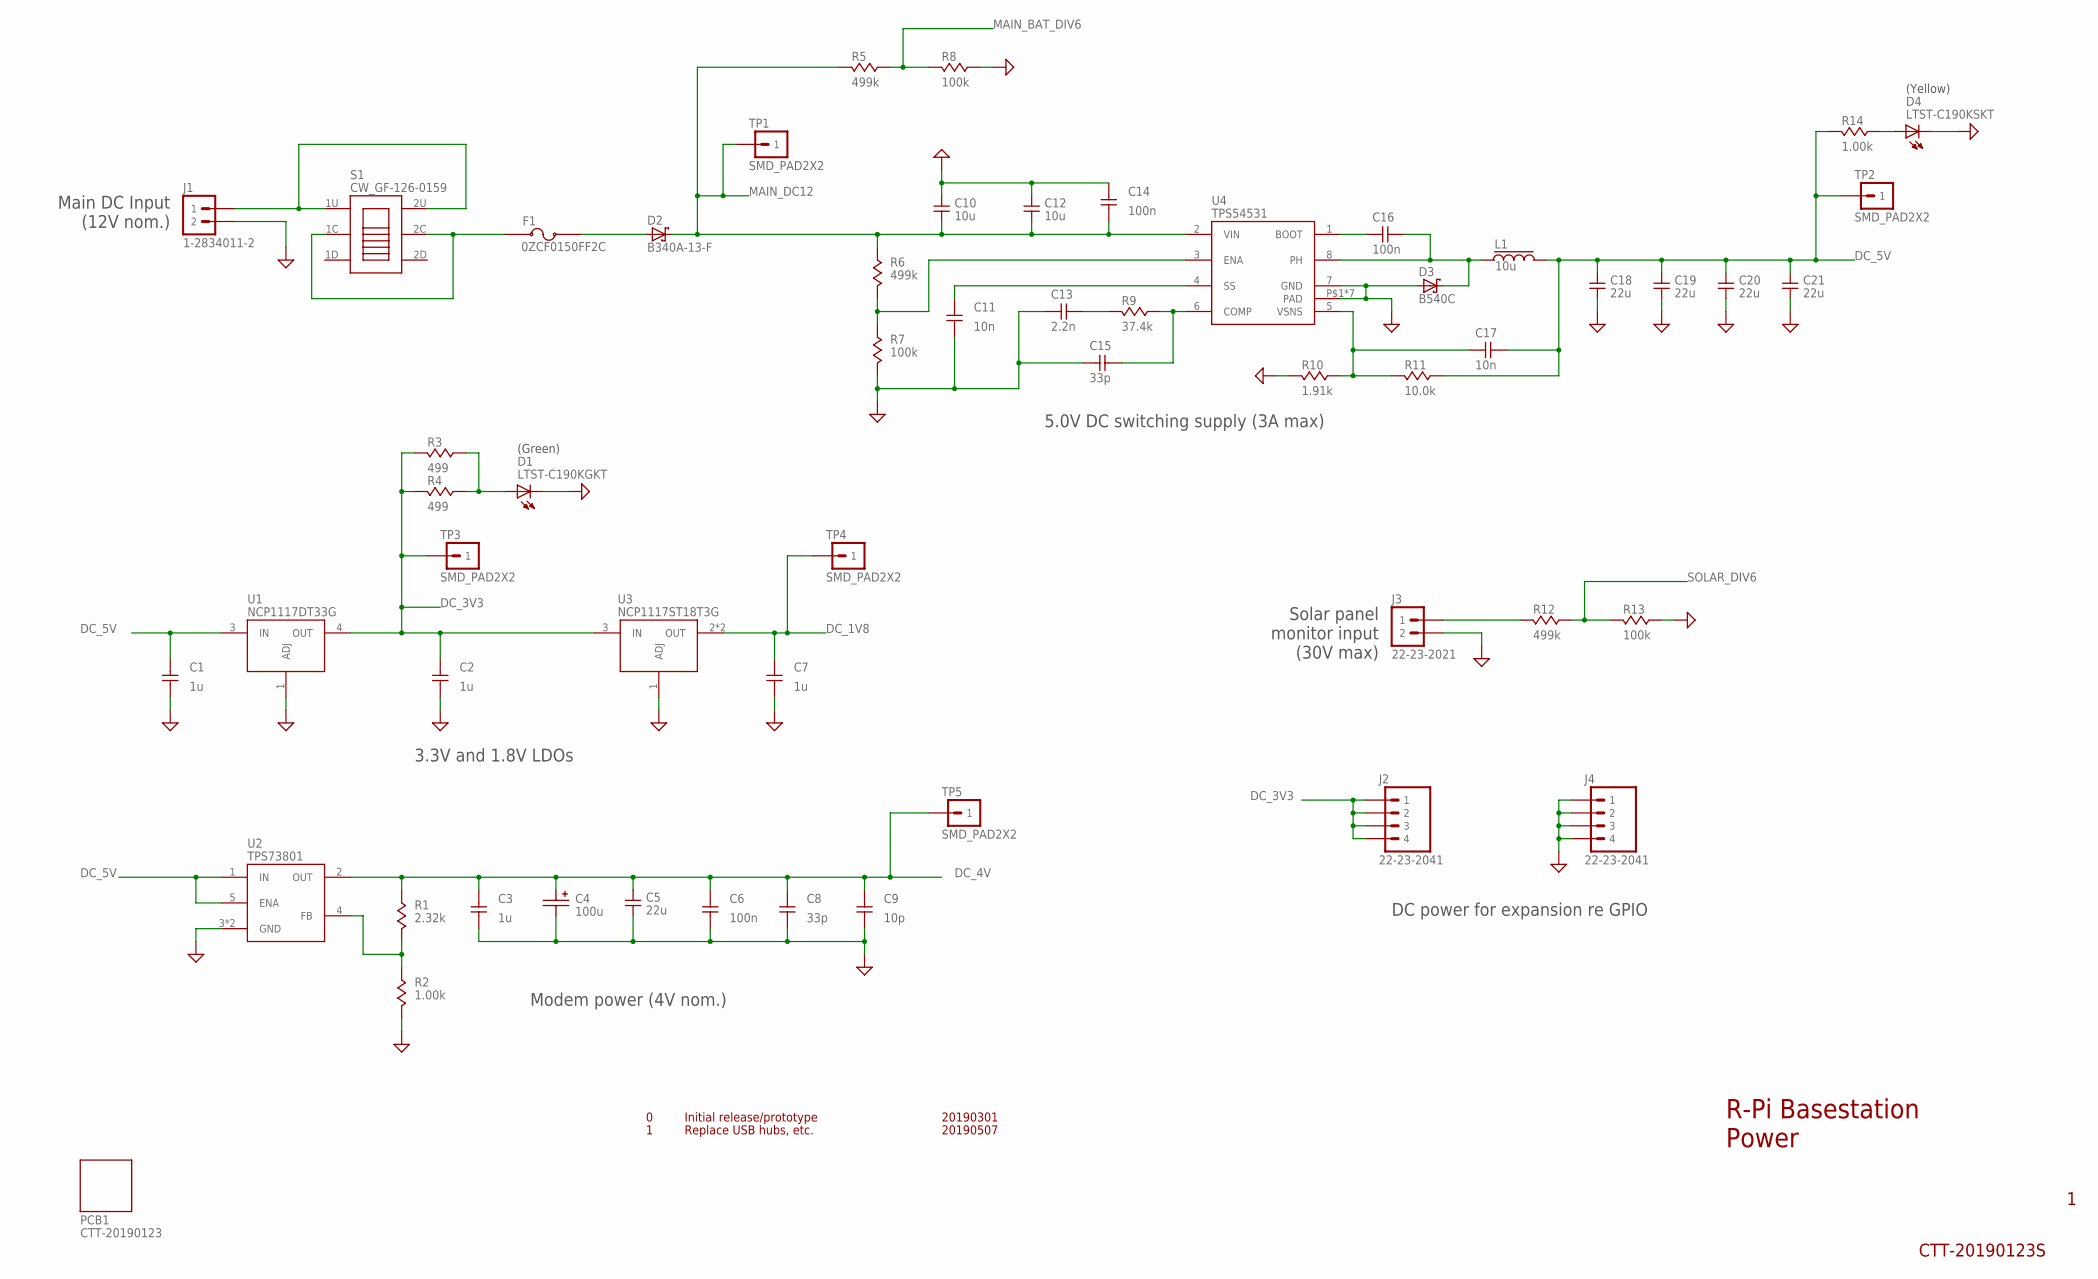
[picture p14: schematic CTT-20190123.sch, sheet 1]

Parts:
C1, C2, C3, C7: 1u; C0603_IPC7351_MED
C4: 100u; C7343
C5, C18, C19, C20, C21: 22u; C0805
C6, C14, C16: 100n; C0402_IPC7351_MED
C8, C15: 33p; C0402_IPC7351_MED
C9: 10p; C0402_IPC7351_MED
C10, C12: 10u; C0805
C11, C17: 10n; C0402_IPC7351_MED
C13: 2.2n; C0402_IPC7351_MED
D1: LTST-C190KGKT; LED0603
D2: B340A-13-F; SMA
D3: B540C; SMC
D4: LTST-C190KSKT; LED0603
F1: 0ZCF0150FF2C; SMD2920_0ZCF-SERIES
J1: 1-2834011-2
J2, J4: 22-23-2041; MTA100-4
J3: 22-23-2021; MTA100-2
L1: 10u; SRR1260
PCB1: CTT-20190123; BLANK_BRD
R1: 2.32k; R0402_IPC7351_MED
R2, R14: 1.00k; R0402_IPC7351_MED
R3, R4: 499; R0402_IPC7351_MED
R5, R6, R12: 499k; R0402_IPC7351_MED
R7, R8, R13: 100k; R0402_IPC7351_MED
R9: 37.4k; R0402_IPC7351_MED
R10: 1.91k; R0402_IPC7351_MED
R11: 10.0k; R0402_IPC7351_MED
S1: CW_GF-126-0159
TP1, TP2, TP3, TP4, TP5: SMD_PAD2X2; SMD_PAD
U1: NCP1117DT33G; DPAK
U2: TPS73801; TI_R-PDSO-G6
U3: NCP1117ST18T3G; SOT-223
U4: TPS54531; TI_R-PDSO-G8

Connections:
DC_1V8: C7.P$2 (2), TP4.1, U3.2 (OUT), U3.4 (OUT); also elsewhere on the board
DC_3V3: C2.P$2 (2), J2.1, J2.2, J2.3, J2.4, R3.P$2 (2), R4.P$2 (2), TP3.1, U1.4 (OUT), U3.3 (IN); also elsewhere on the board
DC_4V: C3.P$2 (2), C4.+ (POS), C5.2, C6.P$2 (2), C8.P$2 (2), C9.P$2 (2), R1.P$1 (1), TP5.1, U2.2 (OUT); also elsewhere on the board
DC_5V: C1.P$2 (2), C17.P$2 (2), C18.2, C19.2, C20.2, C21.2, L1.2, R11.P$1 (1), R14.P$2 (2), TP2.1, U1.3 (IN), U2.1 (IN), U2.5 (ENA); also elsewhere on the board
GND: C1.P$1 (1), C2.P$1 (1), C3.P$1 (1), C4.- (NEG), C5.1, C6.P$1 (1), C7.P$1 (1), C8.P$1 (1), C9.P$1 (1), C10.1, C11.P$1 (1), C12.1, C13.P$1 (1), C14.P$1 (1), C15.P$1 (1), C18.1, C19.1, C20.1, C21.1, D1.K, D3.A, D4.K, J1.2, J3.2, J4.1, J4.2, J4.3, J4.4, R2.P$2 (2), R7.P$2 (2), R8.P$1 (1), R10.P$2 (2), R13.P$1 (1), U1.1 (ADJ), U2.3 (GND), U2.TAB (GND), U3.1 (ADJ), U4.7 (GND), U4.P$1 (PAD), U4.P$2 (PAD), U4.P$3 (PAD), U4.P$4 (PAD), U4.P$5 (PAD), U4.P$6 (PAD), U4.PAD; also elsewhere on the board
MAIN_BAT_DIV6: R5.P$1 (1), R8.P$2 (2); also elsewhere on the board
MAIN_DC12: C10.2, C12.2, C14.P$2 (2), D2.C, R5.P$2 (2), R6.P$1 (1), TP1.1, U4.2 (VIN)
unnamed: C16.P$2 (2), D3.K (C), L1.P$1 (1), U4.8 (PH)
unnamed: R6.P$2 (2), R7.P$1 (1), U4.3 (ENA)
unnamed: C11.P$2 (2), U4.4 (SS)
unnamed: C16.P$1 (1), U4.1 (BOOT)
unnamed: C15.P$2 (2), R9.P$1 (1), U4.6 (COMP)
unnamed: C17.P$1 (1), R10.P$1 (1), R11.P$2 (2), U4.5 (VSNS)
unnamed: C13.P$2 (2), R9.P$2 (2)
unnamed: J1.1, S1.1U, S1.2U
unnamed: D2.A, F1.P$2
unnamed: D4.A, R14.P$1 (1)
unnamed: D1.A, R3.P$1 (1), R4.P$1 (1)
unnamed: R1.P$2 (2), R2.P$1 (1), U2.4 (FB)
unnamed: J3.1, R12.P$2 (2)
unnamed: F1.P$1, S1.1C, S1.2C
SOLAR_DIV6: R12.P$1 (1), R13.P$2 (2); also elsewhere on the board

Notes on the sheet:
Main DC Input (12V nom.)
Modem power (4V nom.)
Solar panel monitor input (30V max)
5.0V DC switching supply (3A max)
3.3V and 1.8V LDOs
DC power for expansion re GPIO
R-Pi Basestation Power
CTT-20190123S
(Yellow)
(Green)
20190507
Initial release/prototype
Replace USB hubs, etc.
20190301

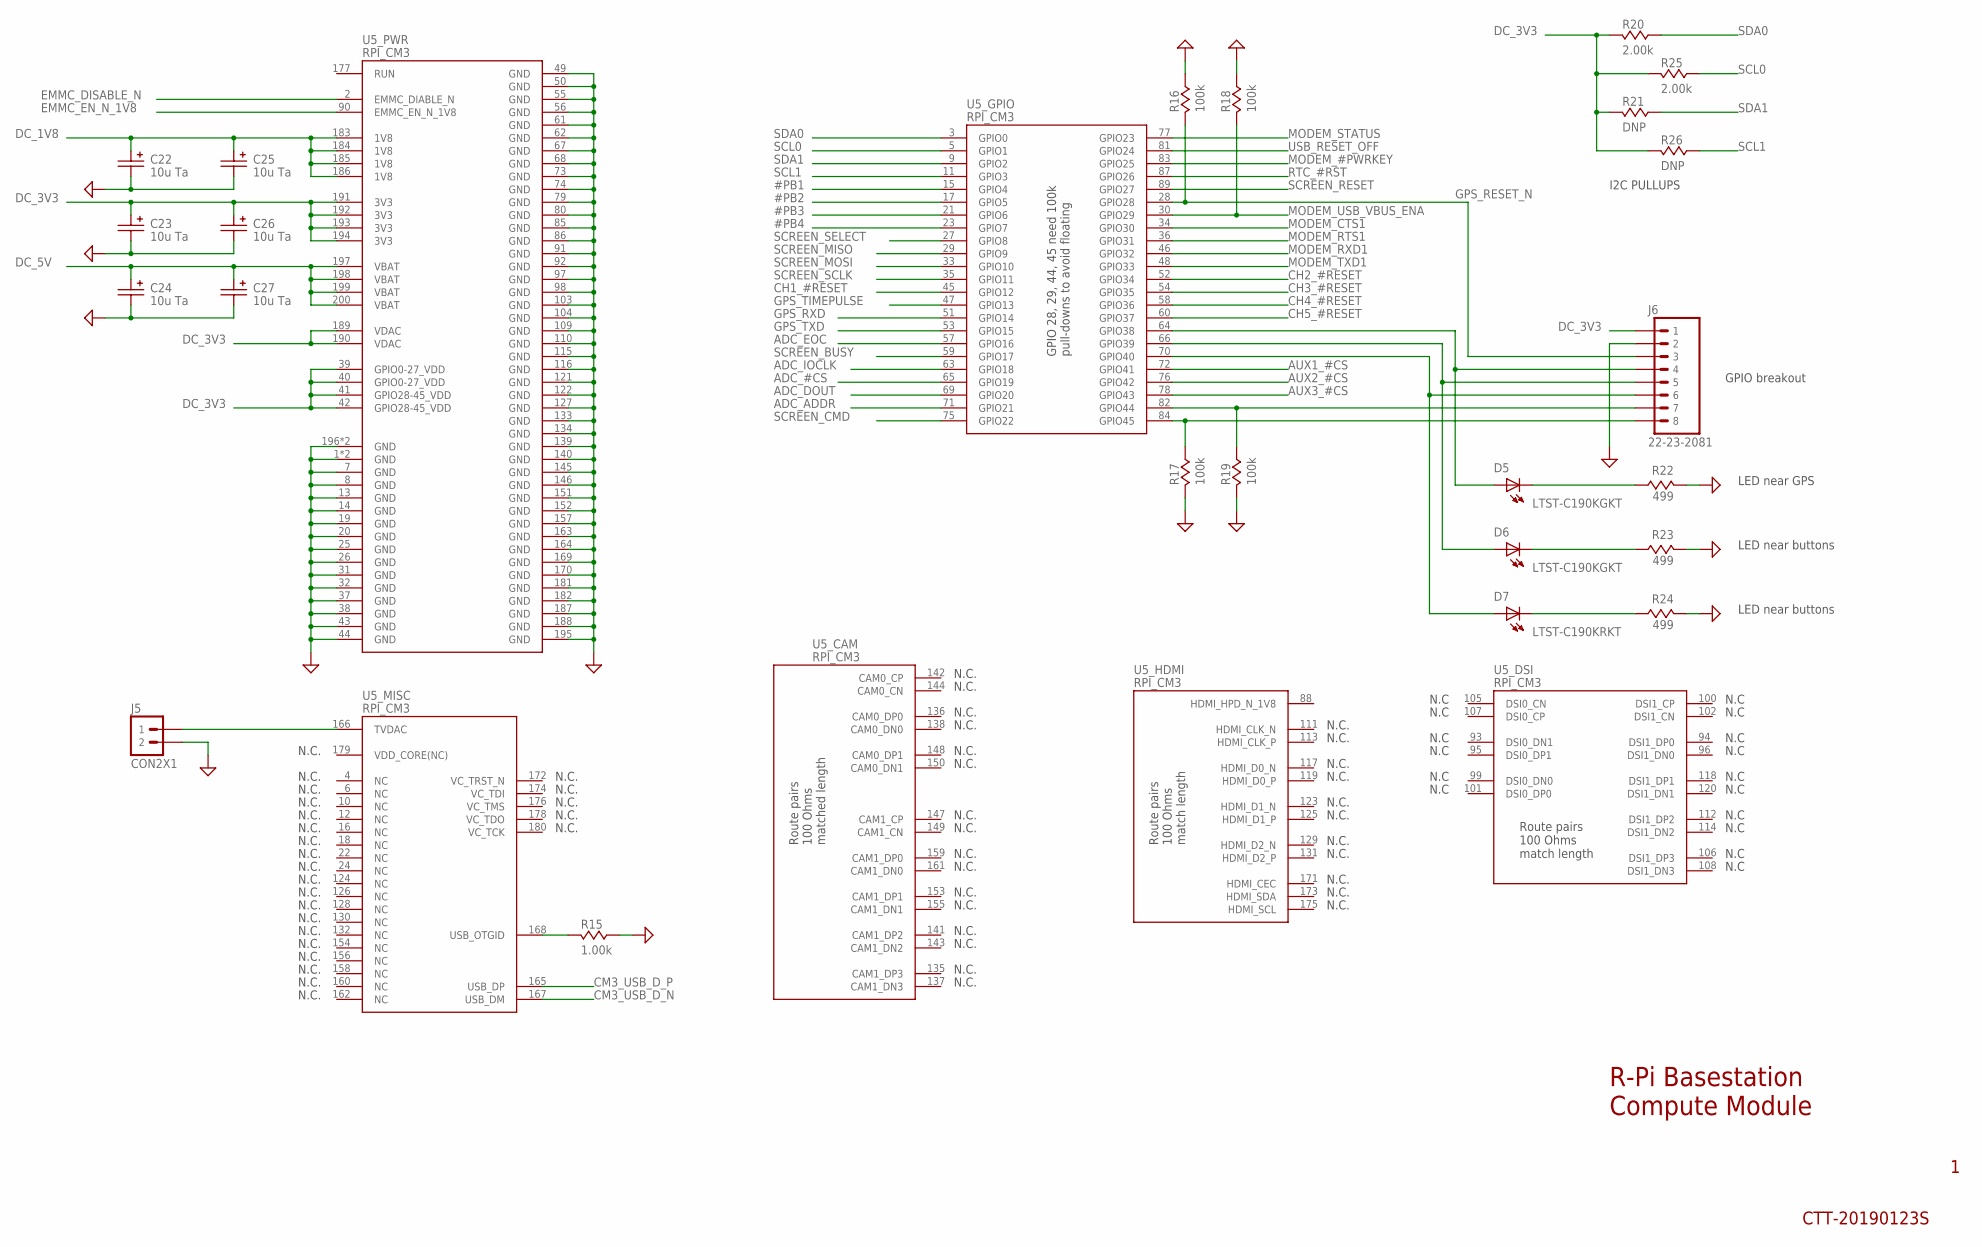
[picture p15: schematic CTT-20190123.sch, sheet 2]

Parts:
C22, C23, C24, C25, C26, C27: 10u Ta; CAP1411-AVX_F97SERIES
D5, D6: LTST-C190KGKT; LED0603
D7: LTST-C190KRKT; LED0603
J5: CON2X1
J6: 22-23-2081; MTA100-8
R15: 1.00k; R0402_IPC7351_MED
R16, R17, R18, R19: 100k; R0402_IPC7351_MED
R20, R25: 2.00k; R0402_IPC7351_MED
R21, R26: DNP; R0402_IPC7351_MED
R22, R23, R24: 499; R0402_IPC7351_MED
U5: RPI_CM3; 1473149-4

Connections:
#PB1: U5.15 (GPIO4); also elsewhere on the board
#PB2: U5.17 (GPIO5); also elsewhere on the board
#PB3: U5.21 (GPIO6); also elsewhere on the board
#PB4: U5.23 (GPIO7); also elsewhere on the board
ADC_#CS: U5.65 (GPIO19); also elsewhere on the board
ADC_ADDR: U5.71 (GPIO21); also elsewhere on the board
ADC_DOUT: U5.69 (GPIO20); also elsewhere on the board
ADC_EOC: U5.57 (GPIO16); also elsewhere on the board
ADC_IOCLK: U5.63 (GPIO18); also elsewhere on the board
AUX1_#CS: U5.72 (GPIO41); also elsewhere on the board
AUX2_#CS: U5.76 (GPIO42); also elsewhere on the board
AUX3_#CS: U5.78 (GPIO43); also elsewhere on the board
CH1_#RESET: U5.45 (GPIO12); also elsewhere on the board
CH2_#RESET: U5.52 (GPIO34); also elsewhere on the board
CH3_#RESET: U5.54 (GPIO35); also elsewhere on the board
CH4_#RESET: U5.58 (GPIO36); also elsewhere on the board
CH5_#RESET: U5.60 (GPIO37); also elsewhere on the board
CM3_USB_D_N: U5.167 (USB_DM); also elsewhere on the board
CM3_USB_D_P: U5.165 (USB_DP); also elsewhere on the board
DC_1V8: C22.+ (POS), C25.+ (POS), U5.183 (1V8), U5.184 (1V8), U5.185 (1V8), U5.186 (1V8); also elsewhere on the board
DC_3V3: C23.+ (POS), C26.+ (POS), J6.1, R20.P$2 (2), R21.P$2 (2), R25.P$2 (2), R26.P$2 (2), U5.39 (GPIO0-27_VDD), U5.40 (GPIO0-27_VDD), U5.41 (GPIO28-45_VDD), U5.42 (GPIO28-45_VDD), U5.189 (VDAC), U5.190 (VDAC), U5.191 (3V3), U5.192 (3V3), U5.193 (3V3), U5.194 (3V3); also elsewhere on the board
DC_5V: C24.+ (POS), C27.+ (POS), U5.197 (VBAT), U5.198 (VBAT), U5.199 (VBAT), U5.200 (VBAT); also elsewhere on the board
EMMC_DISABLE_N: U5.2 (EMMC_DIABLE_N); also elsewhere on the board
EMMC_EN_N_1V8: U5.90 (EMMC_EN_N_1V8); also elsewhere on the board
GND: C22.- (NEG), C23.- (NEG), C24.- (NEG), C25.- (NEG), C26.- (NEG), C27.- (NEG), J5.2, J6.2, R15.P$1 (1), R16.P$1 (1), R17.P$2 (2), R18.P$1 (1), R19.P$2 (2), R22.P$2 (2), R23.P$2 (2), R24.P$2 (2), U5.1 (GND), U5.7 (GND), U5.8 (GND), U5.13 (GND), U5.14 (GND), U5.19 (GND), U5.20 (GND), U5.25 (GND), U5.26 (GND), U5.31 (GND), U5.32 (GND), U5.37 (GND), U5.38 (GND), U5.43 (GND), U5.44 (GND), U5.49 (GND), U5.50 (GND), U5.55 (GND), U5.56 (GND), U5.61 (GND), U5.62 (GND), U5.67 (GND), U5.68 (GND), U5.73 (GND), U5.74 (GND), U5.79 (GND), U5.80 (GND), U5.85 (GND), U5.86 (GND), U5.91 (GND), U5.92 (GND), U5.97 (GND), U5.98 (GND), U5.103 (GND), U5.104 (GND), U5.109 (GND), U5.110 (GND), U5.115 (GND), U5.116 (GND), U5.121 (GND), U5.122 (GND), U5.127 (GND), U5.133 (GND), U5.134 (GND), U5.139 (GND), U5.140 (GND), U5.145 (GND), U5.146 (GND), U5.151 (GND), U5.152 (GND), U5.157 (GND), U5.163 (GND), U5.164 (GND), U5.169 (GND), U5.170 (GND), U5.181 (GND), U5.182 (GND), U5.187 (GND), U5.188 (GND), U5.195 (GND), U5.196 (GND), U5.P$1 (GND), U5.P$2 (GND); also elsewhere on the board
GPS_RESET_N: J6.3, R16.P$2 (2), U5.28 (GPIO28); also elsewhere on the board
GPS_RXD: U5.51 (GPIO14); also elsewhere on the board
GPS_TIMEPULSE: U5.47 (GPIO13); also elsewhere on the board
GPS_TXD: U5.53 (GPIO15); also elsewhere on the board
MODEM_#PWRKEY: U5.83 (GPIO25); also elsewhere on the board
MODEM_CTS1: U5.34 (GPIO30); also elsewhere on the board
MODEM_RTS1: U5.36 (GPIO31); also elsewhere on the board
MODEM_RXD1: U5.46 (GPIO32); also elsewhere on the board
MODEM_STATUS: U5.77 (GPIO23); also elsewhere on the board
MODEM_TXD1: U5.48 (GPIO33); also elsewhere on the board
MODEM_USB_VBUS_ENA: R18.P$2 (2), U5.30 (GPIO29); also elsewhere on the board
unnamed: J5.1, U5.166 (TVDAC)
unnamed: R15.P$2 (2), U5.168 (USB_OTGID)
unnamed: J6.8, R17.P$1 (1), U5.84 (GPIO45)
unnamed: J6.7, R19.P$1 (1), U5.82 (GPIO44)
unnamed: D5.A, J6.4, U5.64 (GPIO38)
unnamed: D6.A, J6.5, U5.66 (GPIO39)
unnamed: D7.A, J6.6, U5.70 (GPIO40)
unnamed: D6.K, R23.P$1 (1)
unnamed: D7.K, R24.P$1 (1)
unnamed: D5.K, R22.P$1 (1)
RTC_#RST: U5.87 (GPIO26); also elsewhere on the board
SCL0: R25.P$1 (1), U5.5 (GPIO1); also elsewhere on the board
SCL1: R26.P$1 (1), U5.11 (GPIO3); also elsewhere on the board
SCREEN_BUSY: U5.59 (GPIO17); also elsewhere on the board
SCREEN_CMD: U5.75 (GPIO22); also elsewhere on the board
SCREEN_MISO: U5.29 (GPIO9); also elsewhere on the board
SCREEN_MOSI: U5.33 (GPIO10); also elsewhere on the board
SCREEN_RESET: U5.89 (GPIO27); also elsewhere on the board
SCREEN_SCLK: U5.35 (GPIO11); also elsewhere on the board
SCREEN_SELECT: U5.27 (GPIO8); also elsewhere on the board
SDA0: R20.P$1 (1), U5.3 (GPIO0); also elsewhere on the board
SDA1: R21.P$1 (1), U5.9 (GPIO2); also elsewhere on the board
USB_RESET_OFF: U5.81 (GPIO24); also elsewhere on the board

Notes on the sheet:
N.C.
N.C
I2C PULLUPS
R-Pi Basestation Compute Module
CTT-20190123S
GPIO breakout
LED near GPS
LED near buttons

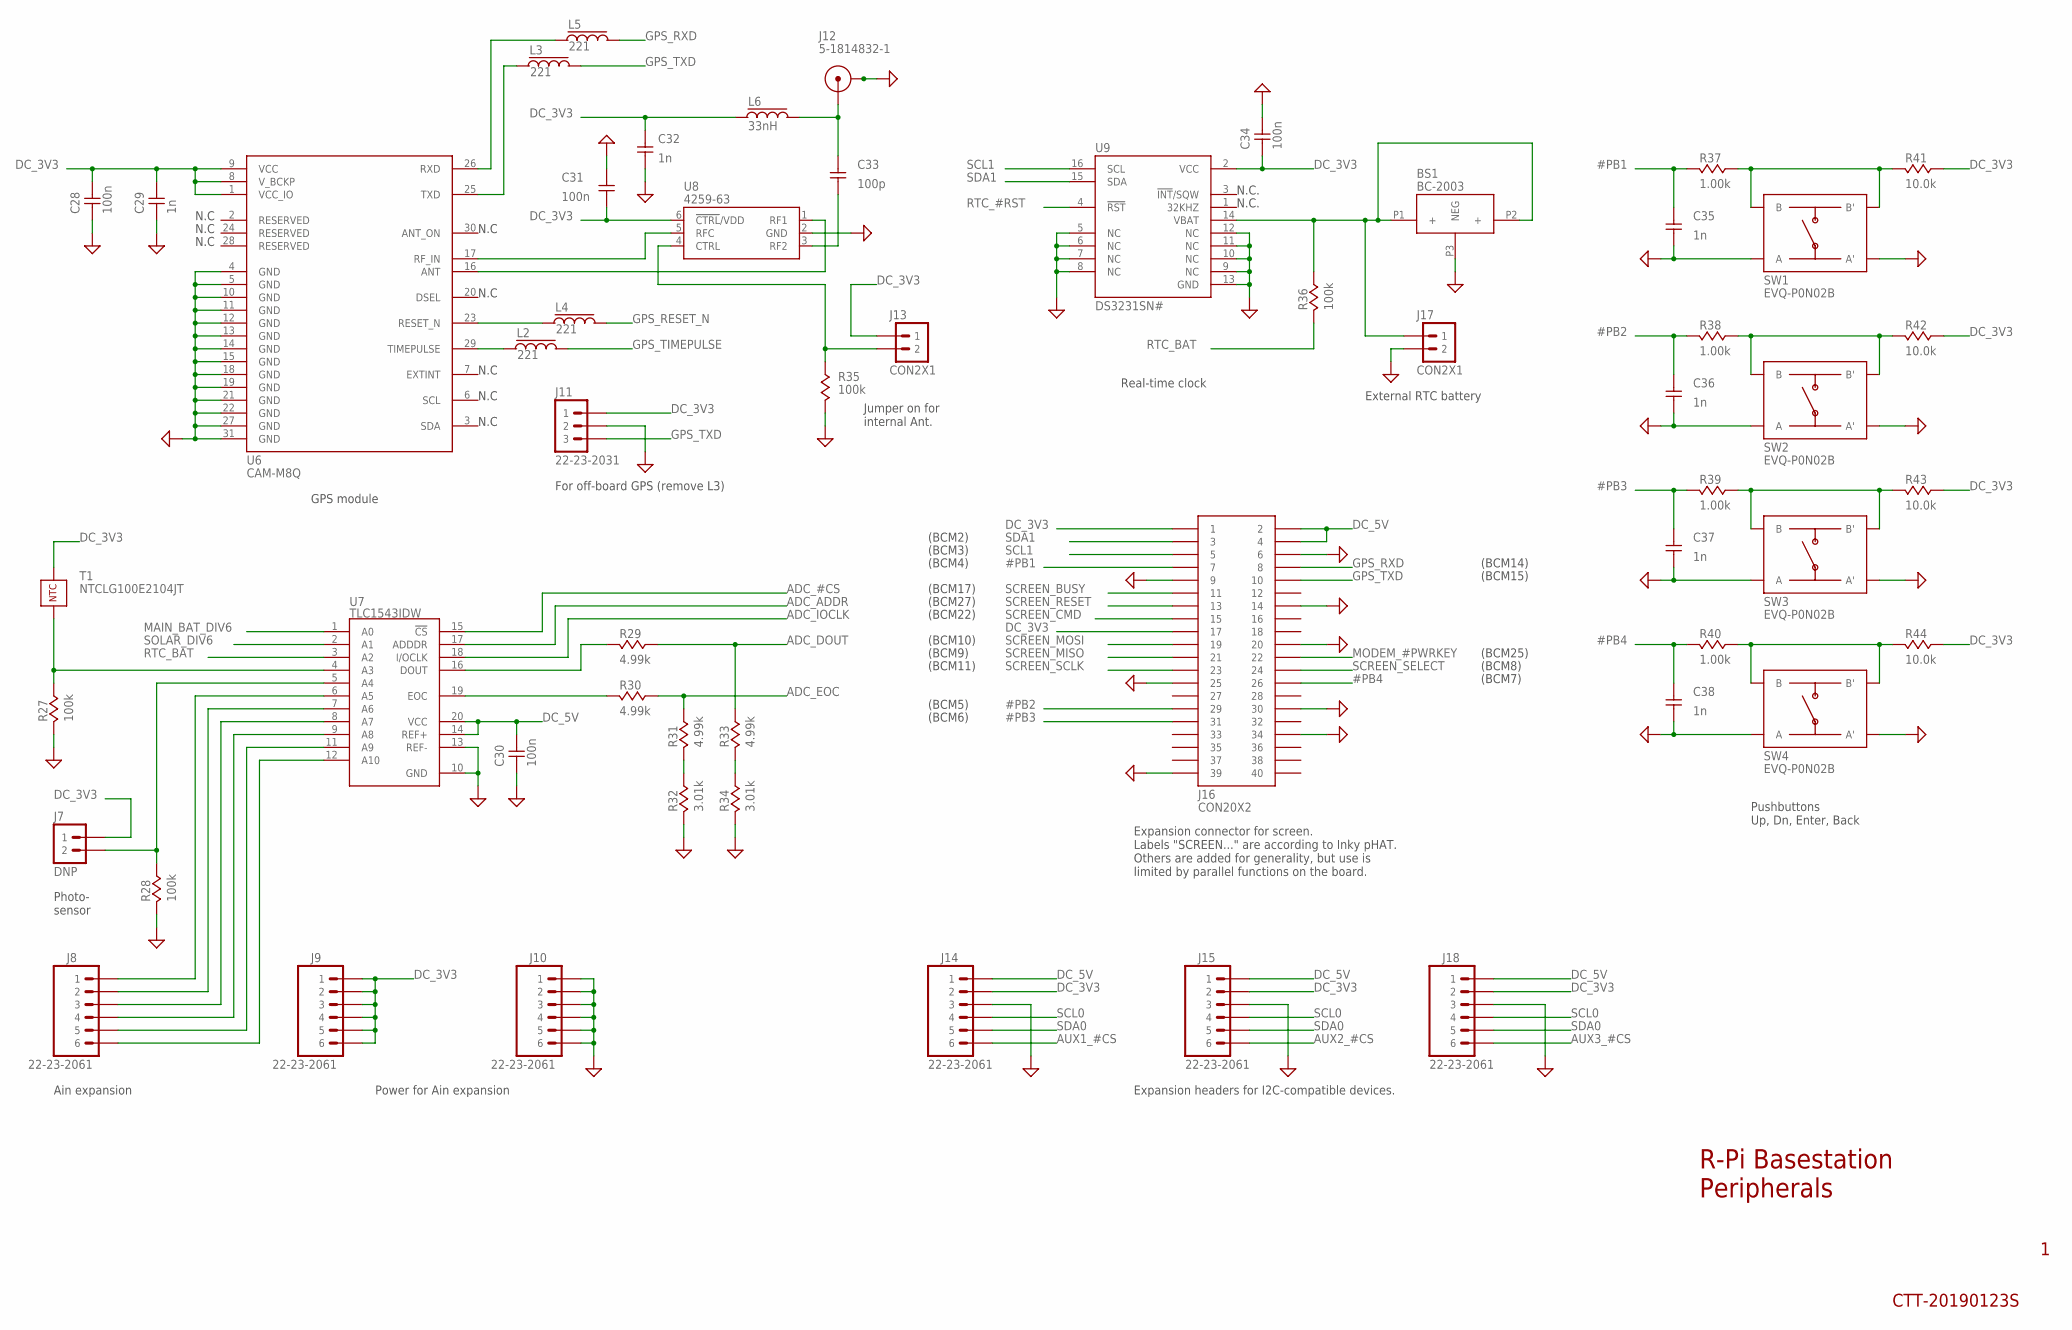
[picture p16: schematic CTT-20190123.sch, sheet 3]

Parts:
BS1: BC-2003; BC-2003-TR
C28, C30, C31, C34: 100n; C0402_IPC7351_MED
C29, C32, C35, C36, C37, C38: 1n; C0402_IPC7351_MED
C33: 100p; C0402_IPC7351_MED
J7: DNP; CON2X1
J8, J9, J10, J14, J15, J18: 22-23-2061; MTA100-6
J11: 22-23-2031; MTA100-3
J12: 5-1814832-1; CON_SMA_TH_VERT
J13, J17: CON2X1
J16: CON20X2
L2, L3, L4, L5: 221; L0402_IPC7351_MED
L6: 33nH; L0402_IPC7351_MED
R27, R28, R35, R36: 100k; R0402_IPC7351_MED
R29, R30, R31, R33: 4.99k; R0402_IPC7351_MED
R32, R34: 3.01k; R0402_IPC7351_MED
R37, R38, R39, R40: 1.00k; R0402_IPC7351_MED
R41, R42, R43, R44: 10.0k; R0402_IPC7351_MED
SW1, SW2, SW3, SW4: EVQ-P0N02B; EVQP0
T1: NTCLG100E2104JT; DO35-VERT
U6: CAM-M8Q; LCC31
U7: TLC1543IDW; SOIC20_DW0020A
U8: 4259-63; SC-70_PEREGRINE
U9: DS3231SN#; SO16-WIDE_MAXIM

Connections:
#PB1: C35.P$2 (2), J16.7, R37.P$2 (2); also elsewhere on the board
#PB2: C36.P$2 (2), J16.29, R38.P$2 (2); also elsewhere on the board
#PB3: C37.P$2 (2), J16.31, R39.P$2 (2); also elsewhere on the board
#PB4: C38.P$2 (2), J16.26, R40.P$2 (2); also elsewhere on the board
ADC_#CS: U7.15 (!CS); also elsewhere on the board
ADC_ADDR: U7.17 (ADDDR); also elsewhere on the board
ADC_DOUT: R29.P$1 (1), R33.P$1 (1); also elsewhere on the board
ADC_EOC: R30.P$1 (1), R31.P$1 (1); also elsewhere on the board
ADC_IOCLK: U7.18 (I/OCLK); also elsewhere on the board
AUX1_#CS: J14.6; also elsewhere on the board
AUX2_#CS: J15.6; also elsewhere on the board
AUX3_#CS: J18.6; also elsewhere on the board
DC_3V3: C28.P$2 (2), C29.P$2 (2), C31.P$1 (1), C32.P$2 (2), C34.P$1 (1), J7.1, J9.1, J9.2, J9.3, J9.4, J9.5, J9.6, J11.1, J13.1, J14.2, J15.2, J16.1, J16.17, J18.2, L6.P$1 (1), R41.P$1 (1), R42.P$1 (1), R43.P$1 (1), R44.P$1 (1), T1.P$1 (1), U6.1 (VCC_IO), U6.8 (V_BCKP), U6.9 (VCC), U8.6 (!CTRL!/VDD), U9.2 (VCC); also elsewhere on the board
DC_5V: C30.P$2 (2), J14.1, J15.1, J16.2, J16.4, J18.1, U7.14 (REF+), U7.20 (VCC); also elsewhere on the board
GND: BS1.P3 (NEG), C28.P$1 (1), C29.P$1 (1), C30.P$1 (1), C31.P$2 (2), C32.P$1 (1), C34.P$2 (2), C35.P$1 (1), C36.P$1 (1), C37.P$1 (1), C38.P$1 (1), J10.1, J10.2, J10.3, J10.4, J10.5, J10.6, J11.2, J12.P$1 (GND), J12.P$2 (GND), J12.P$3 (GND), J12.P$4 (GND), J14.3, J15.3, J16.6, J16.9, J16.14, J16.20, J16.25, J16.30, J16.34, J16.39, J17.2, J18.3, R27.P$2 (2), R28.P$2 (2), R32.P$2 (2), R34.P$2 (2), R35.P$2 (2), SW1.A, SW1.A@1 (A'), SW2.A, SW2.A@1 (A'), SW3.A, SW3.A@1 (A'), SW4.A, SW4.A@1 (A'), U6.4 (GND), U6.5 (GND), U6.10 (GND), U6.11 (GND), U6.12 (GND), U6.13 (GND), U6.14 (GND), U6.15 (GND), U6.18 (GND), U6.19 (GND), U6.21 (GND), U6.22 (GND), U6.27 (GND), U6.31 (GND), U7.10 (GND), U7.13 (REF-), U8.2 (GND), U9.5 (NC), U9.6 (NC), U9.7 (NC), U9.8 (NC), U9.9 (NC), U9.10 (NC), U9.11 (NC), U9.12 (NC), U9.13 (GND); also elsewhere on the board
GPS_RESET_N: L4.P$2 (2); also elsewhere on the board
GPS_RXD: J16.8, L5.P$2 (2); also elsewhere on the board
GPS_TIMEPULSE: L2.P$2 (2); also elsewhere on the board
GPS_TXD: J11.3, J16.10, L3.P$2 (2); also elsewhere on the board
MAIN_BAT_DIV6: U7.1 (A0); also elsewhere on the board
MODEM_#PWRKEY: J16.22; also elsewhere on the board
unnamed: C33.P$2 (2), J12.C (SIG), L6.P$2 (2)
unnamed: U6.17 (RF_IN), U8.5 (RFC)
unnamed: C33.P$1 (1), U8.3 (RF2)
unnamed: U6.16 (ANT), U8.1 (RF1)
unnamed: L4.P$1 (1), U6.23 (RESET_N)
unnamed: L5.P$1 (1), U6.26 (RXD)
unnamed: L3.P$1 (1), U6.25 (TXD)
unnamed: L2.P$1 (1), U6.29 (TIMEPULSE)
unnamed: BS1.P1 (+), BS1.P2 (+), J17.1, R36.P$1 (1), U9.14 (VBAT)
unnamed: R30.P$2 (2), U7.19 (EOC)
unnamed: R29.P$2 (2), U7.16 (DOUT)
unnamed: J7.2, R28.P$1 (1), U7.5 (A4)
unnamed: R31.P$2 (2), R32.P$1 (1)
unnamed: R33.P$2 (2), R34.P$1 (1)
unnamed: R27.P$1 (1), T1.P$2 (2), U7.4 (A3)
unnamed: J8.1, U7.6 (A5)
unnamed: J8.2, U7.7 (A6)
unnamed: J8.3, U7.8 (A7)
unnamed: J8.4, U7.9 (A8)
unnamed: J8.5, U7.11 (A9)
unnamed: J8.6, U7.12 (A10)
unnamed: R40.P$1 (1), R44.P$2 (2), SW4.B, SW4.B@1 (B')
unnamed: R39.P$1 (1), R43.P$2 (2), SW3.B, SW3.B@1 (B')
unnamed: R38.P$1 (1), R42.P$2 (2), SW2.B, SW2.B@1 (B')
unnamed: R37.P$1 (1), R41.P$2 (2), SW1.B, SW1.B@1 (B')
unnamed: J13.2, R35.P$1 (1), U8.4 (CTRL)
RTC_#RST: U9.4 (!RST); also elsewhere on the board
RTC_BAT: R36.P$2 (2), U7.3 (A2)
SCL0: J14.4, J15.4, J18.4; also elsewhere on the board
SCL1: J16.5, U9.16 (SCL); also elsewhere on the board
SCREEN_BUSY: J16.11; also elsewhere on the board
SCREEN_CMD: J16.15; also elsewhere on the board
SCREEN_MISO: J16.21; also elsewhere on the board
SCREEN_MOSI: J16.19; also elsewhere on the board
SCREEN_RESET: J16.13; also elsewhere on the board
SCREEN_SCLK: J16.23; also elsewhere on the board
SCREEN_SELECT: J16.24; also elsewhere on the board
SDA0: J14.5, J15.5, J18.5; also elsewhere on the board
SDA1: J16.3, U9.15 (SDA); also elsewhere on the board
SOLAR_DIV6: U7.2 (A1); also elsewhere on the board

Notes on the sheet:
N.C
N.C.
(BCM17)
(BCM27)
(BCM22)
(BCM10)
(BCM11)
(BCM8)
Expansion connector for screen. Labels "SCREEN..." are according to Inky pHAT. Others are added for generality, but use is limited by parallel functions on the board.
Expansion headers for I2C-compatible devices.
Photo- sensor
Ain expansion
Power for Ain expansion
For off-board GPS (remove L3)
GPS module
Real-time clock
External RTC battery
Pushbuttons Up, Dn, Enter, Back
R-Pi Basestation Peripherals
CTT-20190123S
(BCM4)
(BCM9)
(BCM5)
(BCM6)
(BCM7)
(BCM25)
(BCM15)
(BCM14)
Jumper on for internal Ant.
(BCM2)
(BCM3)

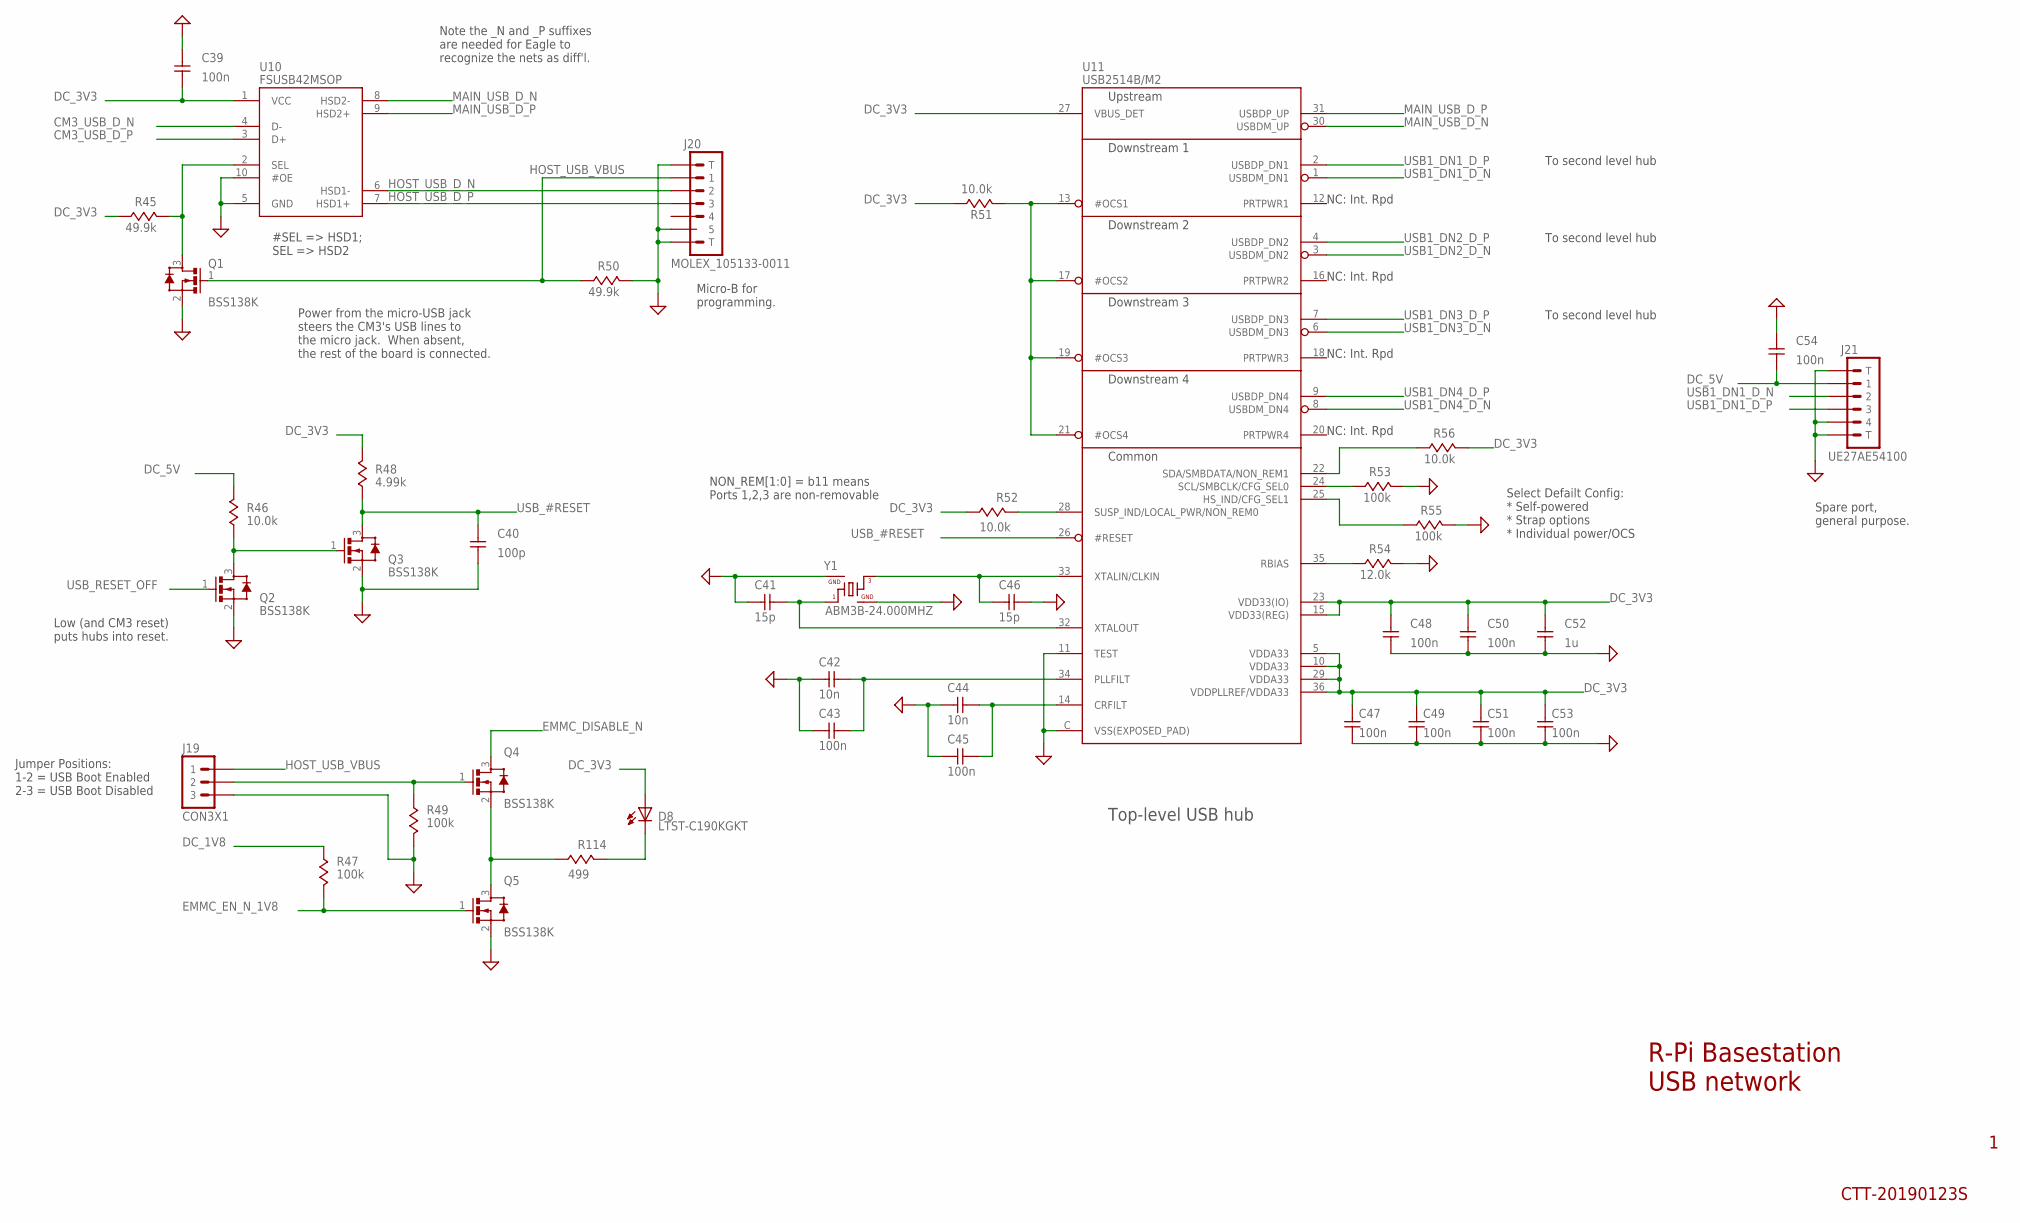
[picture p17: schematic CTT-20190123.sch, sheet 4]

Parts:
C39, C43, C45, C47, C48, C49, C50, C51, C53, C54: 100n; C0402_IPC7351_MED
C40: 100p; C0402_IPC7351_MED
C41, C46: 15p; C0402_IPC7351_MED
C42, C44: 10n; C0402_IPC7351_MED
C52: 1u; C0603_IPC7351_MED
D8: LTST-C190KGKT; LED0603
J19: CON3X1
J20: MOLEX_105133-0011
J21: UE27AE54100
Q1, Q2, Q3, Q4, Q5: BSS138K; SOT-23
R45, R50: 49.9k; R0402_IPC7351_MED
R46, R51, R52, R56: 10.0k; R0402_IPC7351_MED
R47, R49, R53, R55: 100k; R0402_IPC7351_MED
R48: 4.99k; R0402_IPC7351_MED
R54: 12.0k; R0402_IPC7351_MED
R114: 499; R0402_IPC7351_MED
U10: FSUSB42MSOP; MSOP-10
U11: USB2514B/M2; SQFN-36
Y1: ABM3B-24.000MHZ; ABM3B

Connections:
CM3_USB_D_N: U10.4 (D-); also elsewhere on the board
CM3_USB_D_P: U10.3 (D+); also elsewhere on the board
DC_1V8: R47.P$1 (1); also elsewhere on the board
DC_3V3: C39.P$1 (1), C47.P$2 (2), C48.P$2 (2), C49.P$2 (2), C50.P$2 (2), C51.P$2 (2), C52.P$2 (2), C53.P$2 (2), D8.A, R45.P$1 (1), R48.P$2 (2), R51.P$1 (1), R52.P$1 (1), R56.P$2 (2), U10.1 (VCC), U11.5 (VDDA33), U11.10 (VDDA33), U11.15 (VDD33(REG)), U11.23 (VDD33(IO)), U11.27 (VBUS_DET), U11.29 (VDDA33), U11.36 (VDDPLLREF/VDDA33); also elsewhere on the board
DC_5V: C54.P$1 (1), J21.1, R46.P$2 (2); also elsewhere on the board
EMMC_DISABLE_N: Q4.3 (D); also elsewhere on the board
EMMC_EN_N_1V8: Q5.1 (G), R47.P$2 (2); also elsewhere on the board
GND: C39.P$2 (2), C40.P$1 (1), C41.P$1 (1), C42.P$1 (1), C43.P$1 (1), C44.P$1 (1), C45.P$1 (1), C46.P$2 (2), C47.P$1 (1), C48.P$1 (1), C49.P$1 (1), C50.P$1 (1), C51.P$1 (1), C52.P$1 (1), C53.P$1 (1), C54.P$2 (2), J19.3, J20.5, J20.P$1 (T), J20.P$2 (T), J20.P$3 (T), J21.4, J21.P$1 (T), J21.P$2 (T), Q1.2 (S), Q2.2 (S), Q3.2 (S), Q5.2 (S), R49.P$2 (2), R50.P$2 (2), R53.P$2 (2), R54.P$2 (2), R55.P$2 (2), U10.5 (GND), U10.10 (#OE), U11.11 (TEST), U11.C (VSS(EXPOSED_PAD)), Y1.2, Y1.4; also elsewhere on the board
HOST_USB_D_N: J20.2, U10.6 (HSD1-)
HOST_USB_D_P: J20.3, U10.7 (HSD1+)
HOST_USB_VBUS: J19.1, J20.1, Q1.1 (G), R50.P$1 (1)
MAIN_USB_D_N: U10.8 (HSD2-), U11.30 (USBDM_UP)
MAIN_USB_D_P: U10.9 (HSD2+), U11.31 (USBDP_UP)
unnamed: Q4.2 (S), Q5.3 (D), R114.P$1 (1)
unnamed: J19.2, Q4.1 (G), R49.P$1 (1)
unnamed: D8.K, R114.P$2 (2)
unnamed: Q1.3 (D), R45.P$2 (2), U10.2 (SEL)
unnamed: C46.P$1 (1), U11.33 (XTALIN/CLKIN), Y1.3
unnamed: C41.P$2 (2), U11.32 (XTALOUT), Y1.1
unnamed: R53.P$1 (1), U11.24 (SCL/SMBCLK/CFG_SEL0)
unnamed: C42.P$2 (2), C43.P$2 (2), U11.34 (PLLFILT)
unnamed: C44.P$2 (2), C45.P$2 (2), U11.14 (CRFILT)
unnamed: R55.P$1 (1), U11.25 (HS_IND/CFG_SEL1)
unnamed: R54.P$1 (1), U11.35 (RBIAS)
unnamed: R51.P$2 (2), U11.13 (#OCS1), U11.17 (#OCS2), U11.19 (#OCS3), U11.21 (#OCS4)
unnamed: R56.P$1 (1), U11.22 (SDA/SMBDATA/NON_REM1)
unnamed: R52.P$2 (2), U11.28 (SUSP_IND/LOCAL_PWR/NON_REM0)
unnamed: Q2.3 (D), Q3.1 (G), R46.P$1 (1)
USB1_DN1_D_N: J21.2, U11.1 (USBDM_DN1)
USB1_DN1_D_P: J21.3, U11.2 (USBDP_DN1)
USB1_DN2_D_N: U11.3 (USBDM_DN2); also elsewhere on the board
USB1_DN2_D_P: U11.4 (USBDP_DN2); also elsewhere on the board
USB1_DN3_D_N: U11.6 (USBDM_DN3); also elsewhere on the board
USB1_DN3_D_P: U11.7 (USBDP_DN3); also elsewhere on the board
USB1_DN4_D_N: U11.8 (USBDM_DN4); also elsewhere on the board
USB1_DN4_D_P: U11.9 (USBDP_DN4); also elsewhere on the board
USB_#RESET: C40.P$2 (2), Q3.3 (D), R48.P$1 (1), U11.26 (#RESET); also elsewhere on the board
USB_RESET_OFF: Q2.1 (G); also elsewhere on the board

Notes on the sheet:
#SEL => HSD1; SEL => HSD2
NC: Int. Rpd
Select Defailt Config: * Self-powered * Strap options * Individual power/OCS
NON_REM[1:0] = b11 means Ports 1,2,3 are non-removable
Top-level USB hub
Power from the micro-USB jack steers the CM3's USB lines to the micro jack. When absent, the rest of the board is connected.
R-Pi Basestation USB network
CTT-20190123S
To second level hub
Low (and CM3 reset) puts hubs into reset.
Jumper Positions: 1-2 = USB Boot Enabled 2-3 = USB Boot Disabled
Micro-B for programming.
Spare port, general purpose.
Note the _N and _P suffixes are needed for Eagle to recognize the nets as diff'l.

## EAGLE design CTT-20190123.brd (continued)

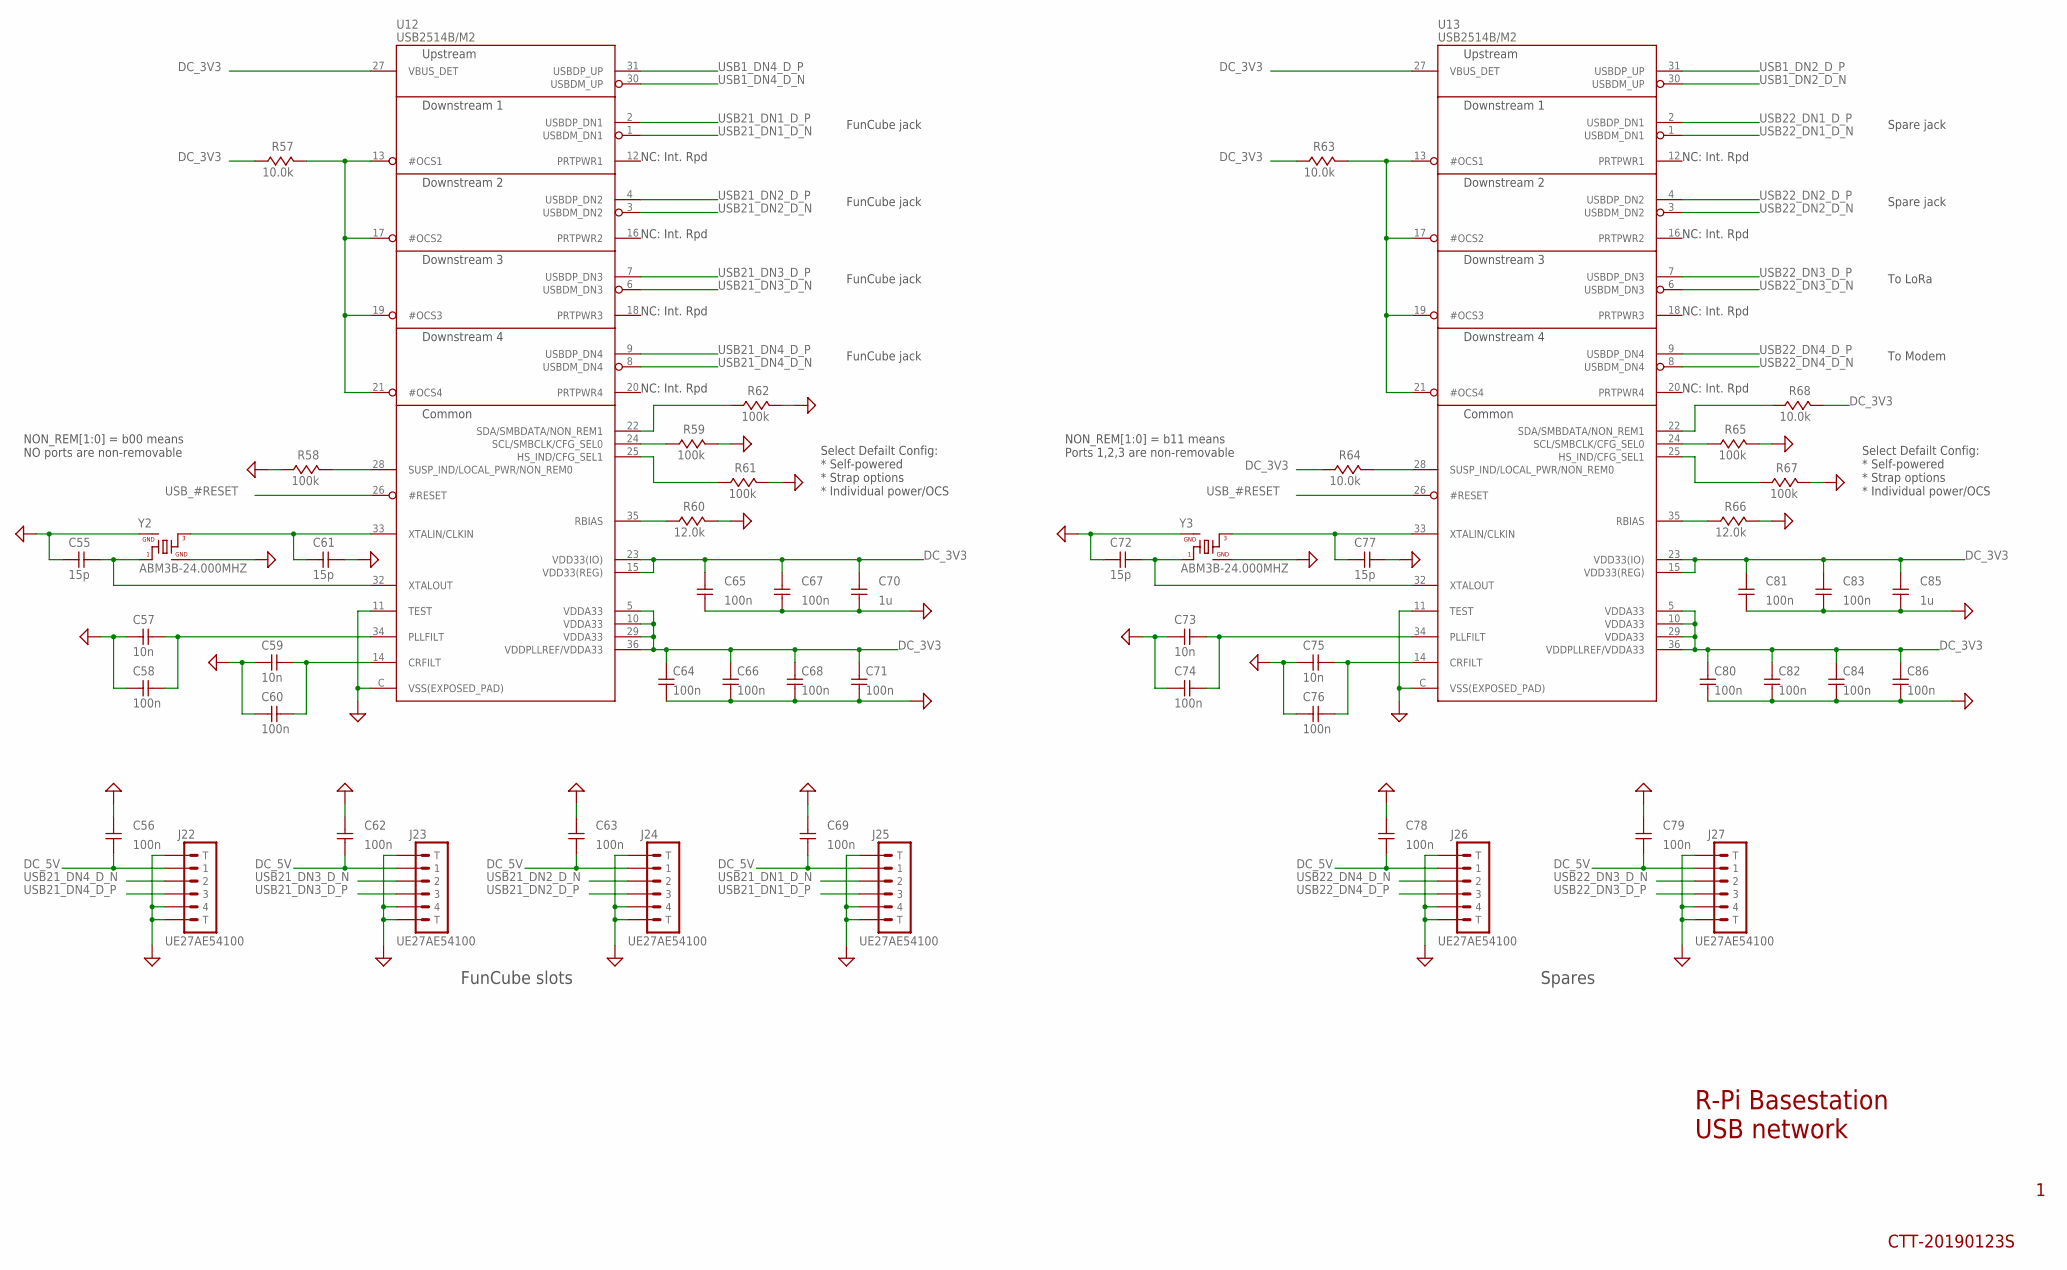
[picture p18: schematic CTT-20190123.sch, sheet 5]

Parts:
C55, C61, C72, C77: 15p; C0402_IPC7351_MED
C56, C58, C60, C62, C63, C64, C65, C66, C67, C68, C69, C71, C74, C76, C78, C79, C80, C81, C82, C83, C84, C86: 100n; C0402_IPC7351_MED
C57, C59, C73, C75: 10n; C0402_IPC7351_MED
C70, C85: 1u; C0603_IPC7351_MED
J22, J23, J24, J25, J26, J27: UE27AE54100
R57, R63, R64, R68: 10.0k; R0402_IPC7351_MED
R58, R59, R61, R62, R65, R67: 100k; R0402_IPC7351_MED
R60, R66: 12.0k; R0402_IPC7351_MED
U12, U13: USB2514B/M2; SQFN-36
Y2, Y3: ABM3B-24.000MHZ; ABM3B

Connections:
DC_3V3: C64.P$2 (2), C65.P$2 (2), C66.P$2 (2), C67.P$2 (2), C68.P$2 (2), C70.P$2 (2), C71.P$2 (2), C80.P$2 (2), C81.P$2 (2), C82.P$2 (2), C83.P$2 (2), C84.P$2 (2), C85.P$2 (2), C86.P$2 (2), R57.P$1 (1), R63.P$1 (1), R64.P$1 (1), R68.P$2 (2), U12.5 (VDDA33), U12.10 (VDDA33), U12.15 (VDD33(REG)), U12.23 (VDD33(IO)), U12.27 (VBUS_DET), U12.29 (VDDA33), U12.36 (VDDPLLREF/VDDA33), U13.5 (VDDA33), U13.10 (VDDA33), U13.15 (VDD33(REG)), U13.23 (VDD33(IO)), U13.27 (VBUS_DET), U13.29 (VDDA33), U13.36 (VDDPLLREF/VDDA33); also elsewhere on the board
DC_5V: C56.P$1 (1), C62.P$1 (1), C63.P$1 (1), C69.P$1 (1), C78.P$1 (1), C79.P$1 (1), J22.1, J23.1, J24.1, J25.1, J26.1, J27.1; also elsewhere on the board
GND: C55.P$1 (1), C56.P$2 (2), C57.P$1 (1), C58.P$1 (1), C59.P$1 (1), C60.P$1 (1), C61.P$2 (2), C62.P$2 (2), C63.P$2 (2), C64.P$1 (1), C65.P$1 (1), C66.P$1 (1), C67.P$1 (1), C68.P$1 (1), C69.P$2 (2), C70.P$1 (1), C71.P$1 (1), C72.P$1 (1), C73.P$1 (1), C74.P$1 (1), C75.P$1 (1), C76.P$1 (1), C77.P$2 (2), C78.P$2 (2), C79.P$2 (2), C80.P$1 (1), C81.P$1 (1), C82.P$1 (1), C83.P$1 (1), C84.P$1 (1), C85.P$1 (1), C86.P$1 (1), J22.4, J22.P$1 (T), J22.P$2 (T), J23.4, J23.P$1 (T), J23.P$2 (T), J24.4, J24.P$1 (T), J24.P$2 (T), J25.4, J25.P$1 (T), J25.P$2 (T), J26.4, J26.P$1 (T), J26.P$2 (T), J27.4, J27.P$1 (T), J27.P$2 (T), R58.P$1 (1), R59.P$2 (2), R60.P$2 (2), R61.P$2 (2), R62.P$2 (2), R65.P$2 (2), R66.P$2 (2), R67.P$2 (2), U12.11 (TEST), U12.C (VSS(EXPOSED_PAD)), U13.11 (TEST), U13.C (VSS(EXPOSED_PAD)), Y2.2, Y2.4, Y3.2, Y3.4; also elsewhere on the board
unnamed: C77.P$1 (1), U13.33 (XTALIN/CLKIN), Y3.3
unnamed: C72.P$2 (2), U13.32 (XTALOUT), Y3.1
unnamed: C61.P$1 (1), U12.33 (XTALIN/CLKIN), Y2.3
unnamed: C55.P$2 (2), U12.32 (XTALOUT), Y2.1
unnamed: C57.P$2 (2), C58.P$2 (2), U12.34 (PLLFILT)
unnamed: C73.P$2 (2), C74.P$2 (2), U13.34 (PLLFILT)
unnamed: C59.P$2 (2), C60.P$2 (2), U12.14 (CRFILT)
unnamed: R59.P$1 (1), U12.24 (SCL/SMBCLK/CFG_SEL0)
unnamed: C75.P$2 (2), C76.P$2 (2), U13.14 (CRFILT)
unnamed: R65.P$1 (1), U13.24 (SCL/SMBCLK/CFG_SEL0)
unnamed: R61.P$1 (1), U12.25 (HS_IND/CFG_SEL1)
unnamed: R67.P$1 (1), U13.25 (HS_IND/CFG_SEL1)
unnamed: R60.P$1 (1), U12.35 (RBIAS)
unnamed: R57.P$2 (2), U12.13 (#OCS1), U12.17 (#OCS2), U12.19 (#OCS3), U12.21 (#OCS4)
unnamed: R62.P$1 (1), U12.22 (SDA/SMBDATA/NON_REM1)
unnamed: R58.P$2 (2), U12.28 (SUSP_IND/LOCAL_PWR/NON_REM0)
unnamed: R66.P$1 (1), U13.35 (RBIAS)
unnamed: R63.P$2 (2), U13.13 (#OCS1), U13.17 (#OCS2), U13.19 (#OCS3), U13.21 (#OCS4)
unnamed: R68.P$1 (1), U13.22 (SDA/SMBDATA/NON_REM1)
unnamed: R64.P$2 (2), U13.28 (SUSP_IND/LOCAL_PWR/NON_REM0)
USB1_DN2_D_N: U13.30 (USBDM_UP); also elsewhere on the board
USB1_DN2_D_P: U13.31 (USBDP_UP); also elsewhere on the board
USB1_DN4_D_N: U12.30 (USBDM_UP); also elsewhere on the board
USB1_DN4_D_P: U12.31 (USBDP_UP); also elsewhere on the board
USB21_DN1_D_N: J25.2, U12.1 (USBDM_DN1)
USB21_DN1_D_P: J25.3, U12.2 (USBDP_DN1)
USB21_DN2_D_N: J24.2, U12.3 (USBDM_DN2)
USB21_DN2_D_P: J24.3, U12.4 (USBDP_DN2)
USB21_DN3_D_N: J23.2, U12.6 (USBDM_DN3)
USB21_DN3_D_P: J23.3, U12.7 (USBDP_DN3)
USB21_DN4_D_N: J22.2, U12.8 (USBDM_DN4)
USB21_DN4_D_P: J22.3, U12.9 (USBDP_DN4)
USB22_DN1_D_N: U13.1 (USBDM_DN1); also elsewhere on the board
USB22_DN1_D_P: U13.2 (USBDP_DN1); also elsewhere on the board
USB22_DN2_D_N: U13.3 (USBDM_DN2); also elsewhere on the board
USB22_DN2_D_P: U13.4 (USBDP_DN2); also elsewhere on the board
USB22_DN3_D_N: J27.2, U13.6 (USBDM_DN3)
USB22_DN3_D_P: J27.3, U13.7 (USBDP_DN3)
USB22_DN4_D_N: J26.2, U13.8 (USBDM_DN4)
USB22_DN4_D_P: J26.3, U13.9 (USBDP_DN4)
USB_#RESET: U12.26 (#RESET), U13.26 (#RESET); also elsewhere on the board

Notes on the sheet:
R-Pi Basestation USB network
CTT-20190123S
NC: Int. Rpd
Select Defailt Config: * Self-powered * Strap options * Individual power/OCS
NON_REM[1:0] = b00 means NO ports are non-removable
FunCube slots
NON_REM[1:0] = b11 means Ports 1,2,3 are non-removable
Spares
To Modem
To LoRa
Spare jack
FunCube jack

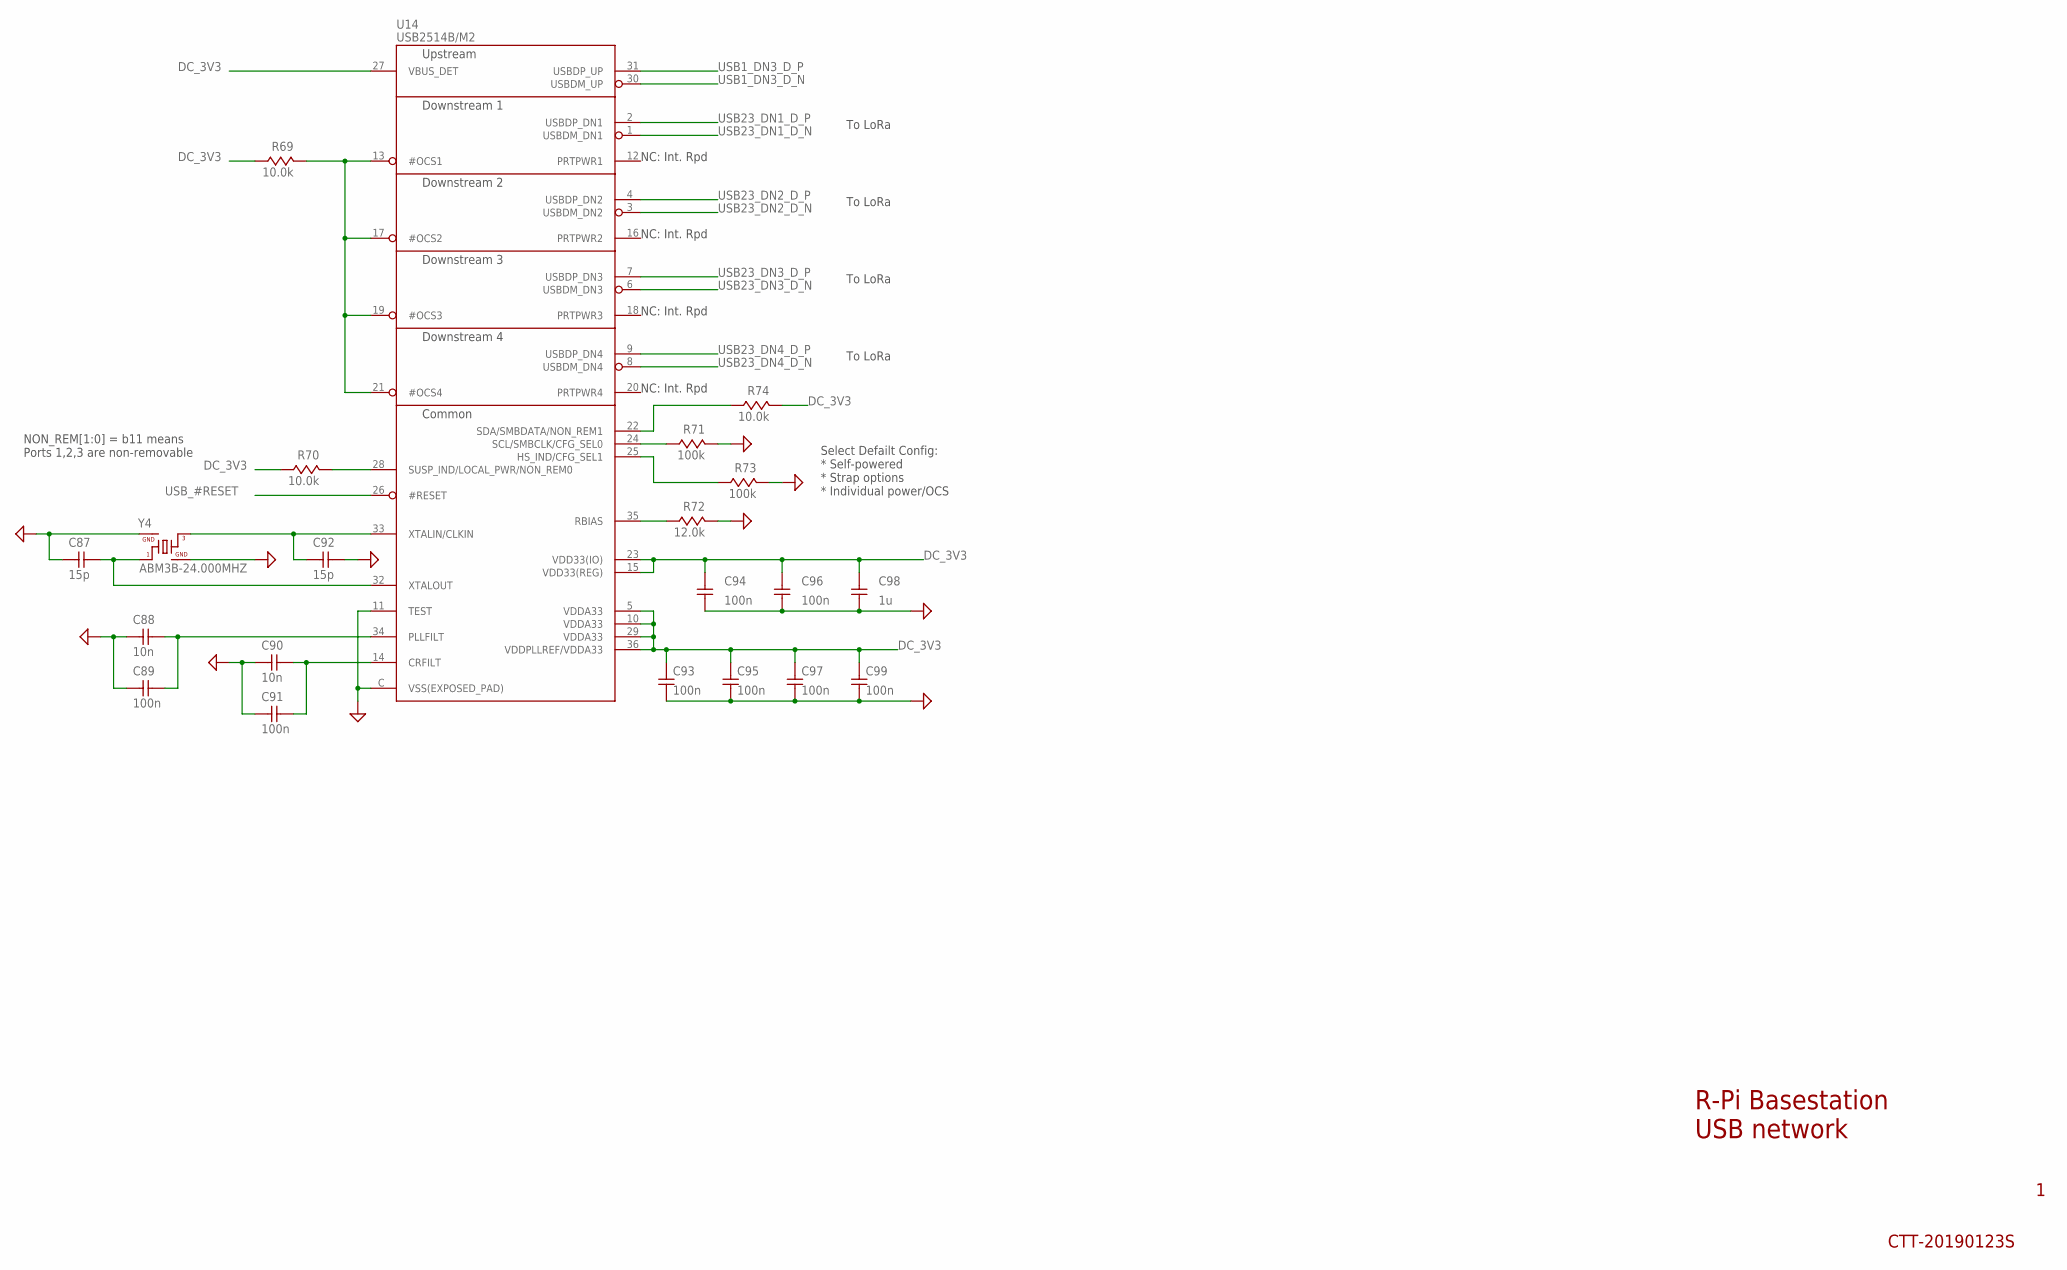
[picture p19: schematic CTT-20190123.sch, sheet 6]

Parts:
C87, C92: 15p; C0402_IPC7351_MED
C88, C90: 10n; C0402_IPC7351_MED
C89, C91, C93, C94, C95, C96, C97, C99: 100n; C0402_IPC7351_MED
C98: 1u; C0603_IPC7351_MED
R69, R70, R74: 10.0k; R0402_IPC7351_MED
R71, R73: 100k; R0402_IPC7351_MED
R72: 12.0k; R0402_IPC7351_MED
U14: USB2514B/M2; SQFN-36
Y4: ABM3B-24.000MHZ; ABM3B

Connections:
DC_3V3: C93.P$2 (2), C94.P$2 (2), C95.P$2 (2), C96.P$2 (2), C97.P$2 (2), C98.P$2 (2), C99.P$2 (2), R69.P$1 (1), R70.P$1 (1), R74.P$2 (2), U14.5 (VDDA33), U14.10 (VDDA33), U14.15 (VDD33(REG)), U14.23 (VDD33(IO)), U14.27 (VBUS_DET), U14.29 (VDDA33), U14.36 (VDDPLLREF/VDDA33); also elsewhere on the board
GND: C87.P$1 (1), C88.P$1 (1), C89.P$1 (1), C90.P$1 (1), C91.P$1 (1), C92.P$2 (2), C93.P$1 (1), C94.P$1 (1), C95.P$1 (1), C96.P$1 (1), C97.P$1 (1), C98.P$1 (1), C99.P$1 (1), R71.P$2 (2), R72.P$2 (2), R73.P$2 (2), U14.11 (TEST), U14.C (VSS(EXPOSED_PAD)), Y4.2, Y4.4; also elsewhere on the board
unnamed: C92.P$1 (1), U14.33 (XTALIN/CLKIN), Y4.3
unnamed: C87.P$2 (2), U14.32 (XTALOUT), Y4.1
unnamed: C88.P$2 (2), C89.P$2 (2), U14.34 (PLLFILT)
unnamed: C90.P$2 (2), C91.P$2 (2), U14.14 (CRFILT)
unnamed: R71.P$1 (1), U14.24 (SCL/SMBCLK/CFG_SEL0)
unnamed: R73.P$1 (1), U14.25 (HS_IND/CFG_SEL1)
unnamed: R72.P$1 (1), U14.35 (RBIAS)
unnamed: R69.P$2 (2), U14.13 (#OCS1), U14.17 (#OCS2), U14.19 (#OCS3), U14.21 (#OCS4)
unnamed: R74.P$1 (1), U14.22 (SDA/SMBDATA/NON_REM1)
unnamed: R70.P$2 (2), U14.28 (SUSP_IND/LOCAL_PWR/NON_REM0)
USB1_DN3_D_N: U14.30 (USBDM_UP); also elsewhere on the board
USB1_DN3_D_P: U14.31 (USBDP_UP); also elsewhere on the board
USB23_DN1_D_N: U14.1 (USBDM_DN1); also elsewhere on the board
USB23_DN1_D_P: U14.2 (USBDP_DN1); also elsewhere on the board
USB23_DN2_D_N: U14.3 (USBDM_DN2); also elsewhere on the board
USB23_DN2_D_P: U14.4 (USBDP_DN2); also elsewhere on the board
USB23_DN3_D_N: U14.6 (USBDM_DN3); also elsewhere on the board
USB23_DN3_D_P: U14.7 (USBDP_DN3); also elsewhere on the board
USB23_DN4_D_N: U14.8 (USBDM_DN4); also elsewhere on the board
USB23_DN4_D_P: U14.9 (USBDP_DN4); also elsewhere on the board
USB_#RESET: U14.26 (#RESET); also elsewhere on the board

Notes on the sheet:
R-Pi Basestation USB network
CTT-20190123S
NC: Int. Rpd
Select Defailt Config: * Self-powered * Strap options * Individual power/OCS
NON_REM[1:0] = b11 means Ports 1,2,3 are non-removable
To LoRa

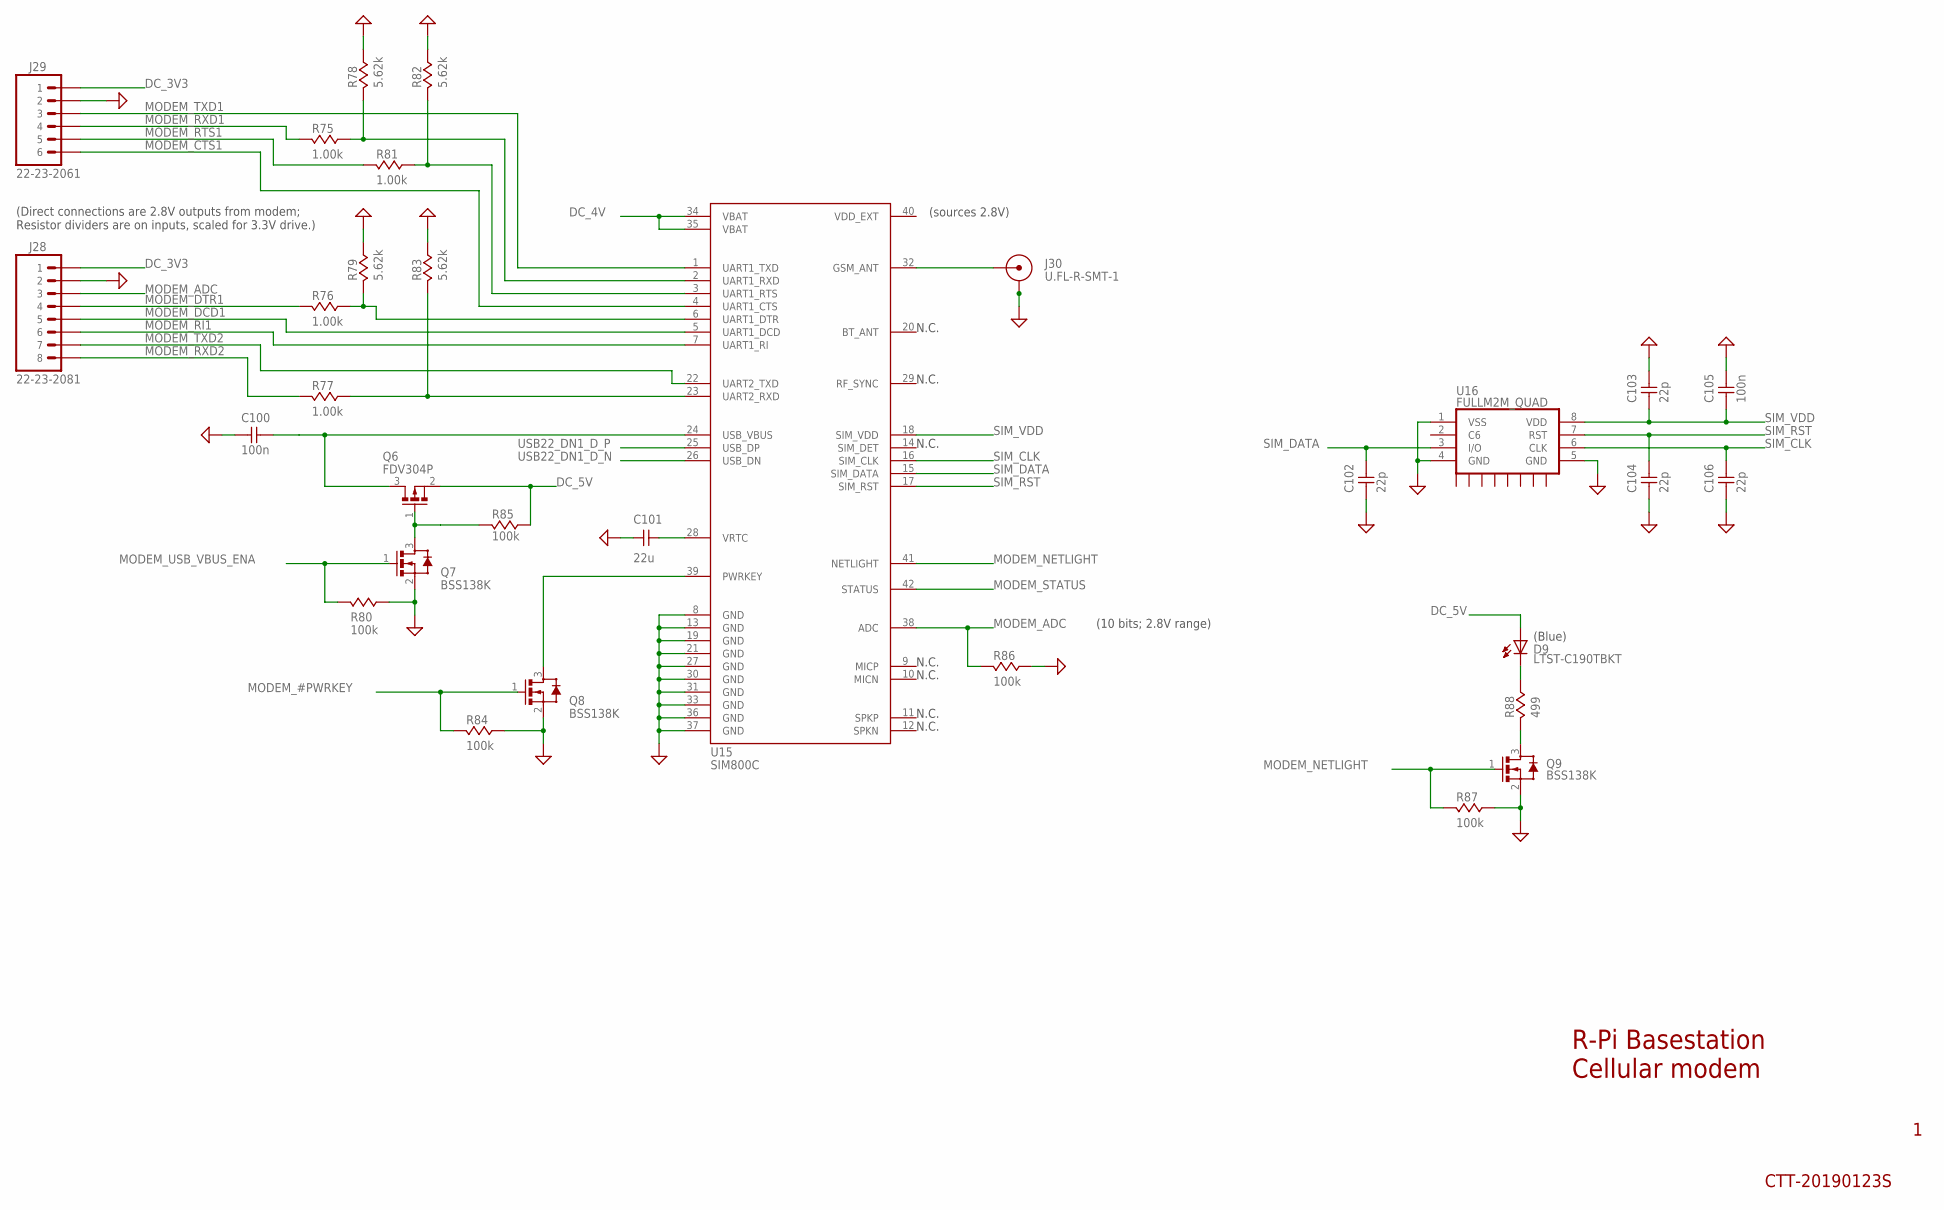
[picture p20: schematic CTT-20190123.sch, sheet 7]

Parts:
C100, C105: 100n; C0402_IPC7351_MED
C101: 22u; C0805
C102, C103, C104, C106: 22p; C0402_IPC7351_MED
D9: LTST-C190TBKT; LED0603
J28: 22-23-2081; MTA100-8
J29: 22-23-2061; MTA100-6
J30: U.FL-R-SMT-1
Q6: FDV304P; SOT-23
Q7, Q8, Q9: BSS138K; SOT-23
R75, R76, R77, R81: 1.00k; R0402_IPC7351_MED
R78, R79, R82, R83: 5.62k; R0402_IPC7351_MED
R80, R84, R85, R86, R87: 100k; R0402_IPC7351_MED
R88: 499; R0402_IPC7351_MED
U15: SIM800C
U16: FULLM2M_QUAD; MFF2

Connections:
DC_3V3: J28.1, J29.1; also elsewhere on the board
DC_4V: U15.34 (VBAT), U15.35 (VBAT); also elsewhere on the board
DC_5V: D9.A, Q6.2 (S), R85.P$1 (1); also elsewhere on the board
GND: C100.P$1 (1), C101.1, C102.P$1 (1), C103.P$2 (2), C104.P$1 (1), C105.P$2 (2), C106.P$1 (1), J28.2, J29.2, J30.GND, J30.GND@1 (GND), Q7.2 (S), Q8.2 (S), Q9.2 (S), R78.P$1 (1), R79.P$1 (1), R80.P$1 (1), R82.P$1 (1), R83.P$1 (1), R84.P$1 (1), R86.P$1 (1), R87.P$1 (1), U15.8 (GND), U15.13 (GND), U15.19 (GND), U15.21 (GND), U15.27 (GND), U15.30 (GND), U15.31 (GND), U15.33 (GND), U15.36 (GND), U15.37 (GND), U16.1 (VSS), U16.4 (GND), U16.5 (GND); also elsewhere on the board
MODEM_#PWRKEY: Q8.1 (G), R84.P$2 (2); also elsewhere on the board
MODEM_ADC: J28.3, R86.P$2 (2), U15.38 (ADC)
MODEM_CTS1: J29.6, U15.4 (UART1_CTS); also elsewhere on the board
MODEM_DCD1: J28.5, U15.5 (UART1_DCD)
MODEM_DTR1: J28.4, R76.P$2 (2)
MODEM_NETLIGHT: Q9.1 (G), R87.P$2 (2), U15.41 (NETLIGHT)
MODEM_RI1: J28.6, U15.7 (UART1_RI)
MODEM_RTS1: J29.5, R81.P$2 (2); also elsewhere on the board
MODEM_RXD1: J29.4, R75.P$2 (2); also elsewhere on the board
MODEM_RXD2: J28.8, R77.P$2 (2)
MODEM_STATUS: U15.42 (STATUS); also elsewhere on the board
MODEM_TXD1: J29.3, U15.1 (UART1_TXD); also elsewhere on the board
MODEM_TXD2: J28.7, U15.22 (UART2_TXD)
MODEM_USB_VBUS_ENA: Q7.1 (G), R80.P$2 (2); also elsewhere on the board
unnamed: Q8.3 (D), U15.39 (PWRKEY)
unnamed: C101.2, U15.28 (VRTC)
unnamed: C100.P$2 (2), Q6.3 (D), U15.24 (USB_VBUS)
unnamed: R77.P$1 (1), R83.P$2 (2), U15.23 (UART2_RXD)
unnamed: Q6.1 (G), Q7.3 (D), R85.P$2 (2)
unnamed: J30.SIG, U15.32 (GSM_ANT)
unnamed: R76.P$1 (1), R79.P$2 (2), U15.6 (UART1_DTR)
unnamed: D9.K, R88.P$1 (1)
unnamed: Q9.3 (D), R88.P$2 (2)
unnamed: R81.P$1 (1), R82.P$2 (2), U15.3 (UART1_RTS)
unnamed: R75.P$1 (1), R78.P$2 (2), U15.2 (UART1_RXD)
SIM_CLK: C106.P$2 (2), U15.16 (SIM_CLK), U16.6 (CLK)
SIM_DATA: C102.P$2 (2), U15.15 (SIM_DATA), U16.3 (I/O)
SIM_RST: C104.P$2 (2), U15.17 (SIM_RST), U16.7 (RST)
SIM_VDD: C103.P$1 (1), C105.P$1 (1), U15.18 (SIM_VDD), U16.8 (VDD)
USB22_DN1_D_N: U15.26 (USB_DN); also elsewhere on the board
USB22_DN1_D_P: U15.25 (USB_DP); also elsewhere on the board

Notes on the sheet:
N.C.
(sources 2.8V)
(Direct connections are 2.8V outputs from modem; Resistor dividers are on inputs, scaled for 3.3V drive.)
(10 bits; 2.8V range)
R-Pi Basestation Cellular modem
CTT-20190123S
(Blue)

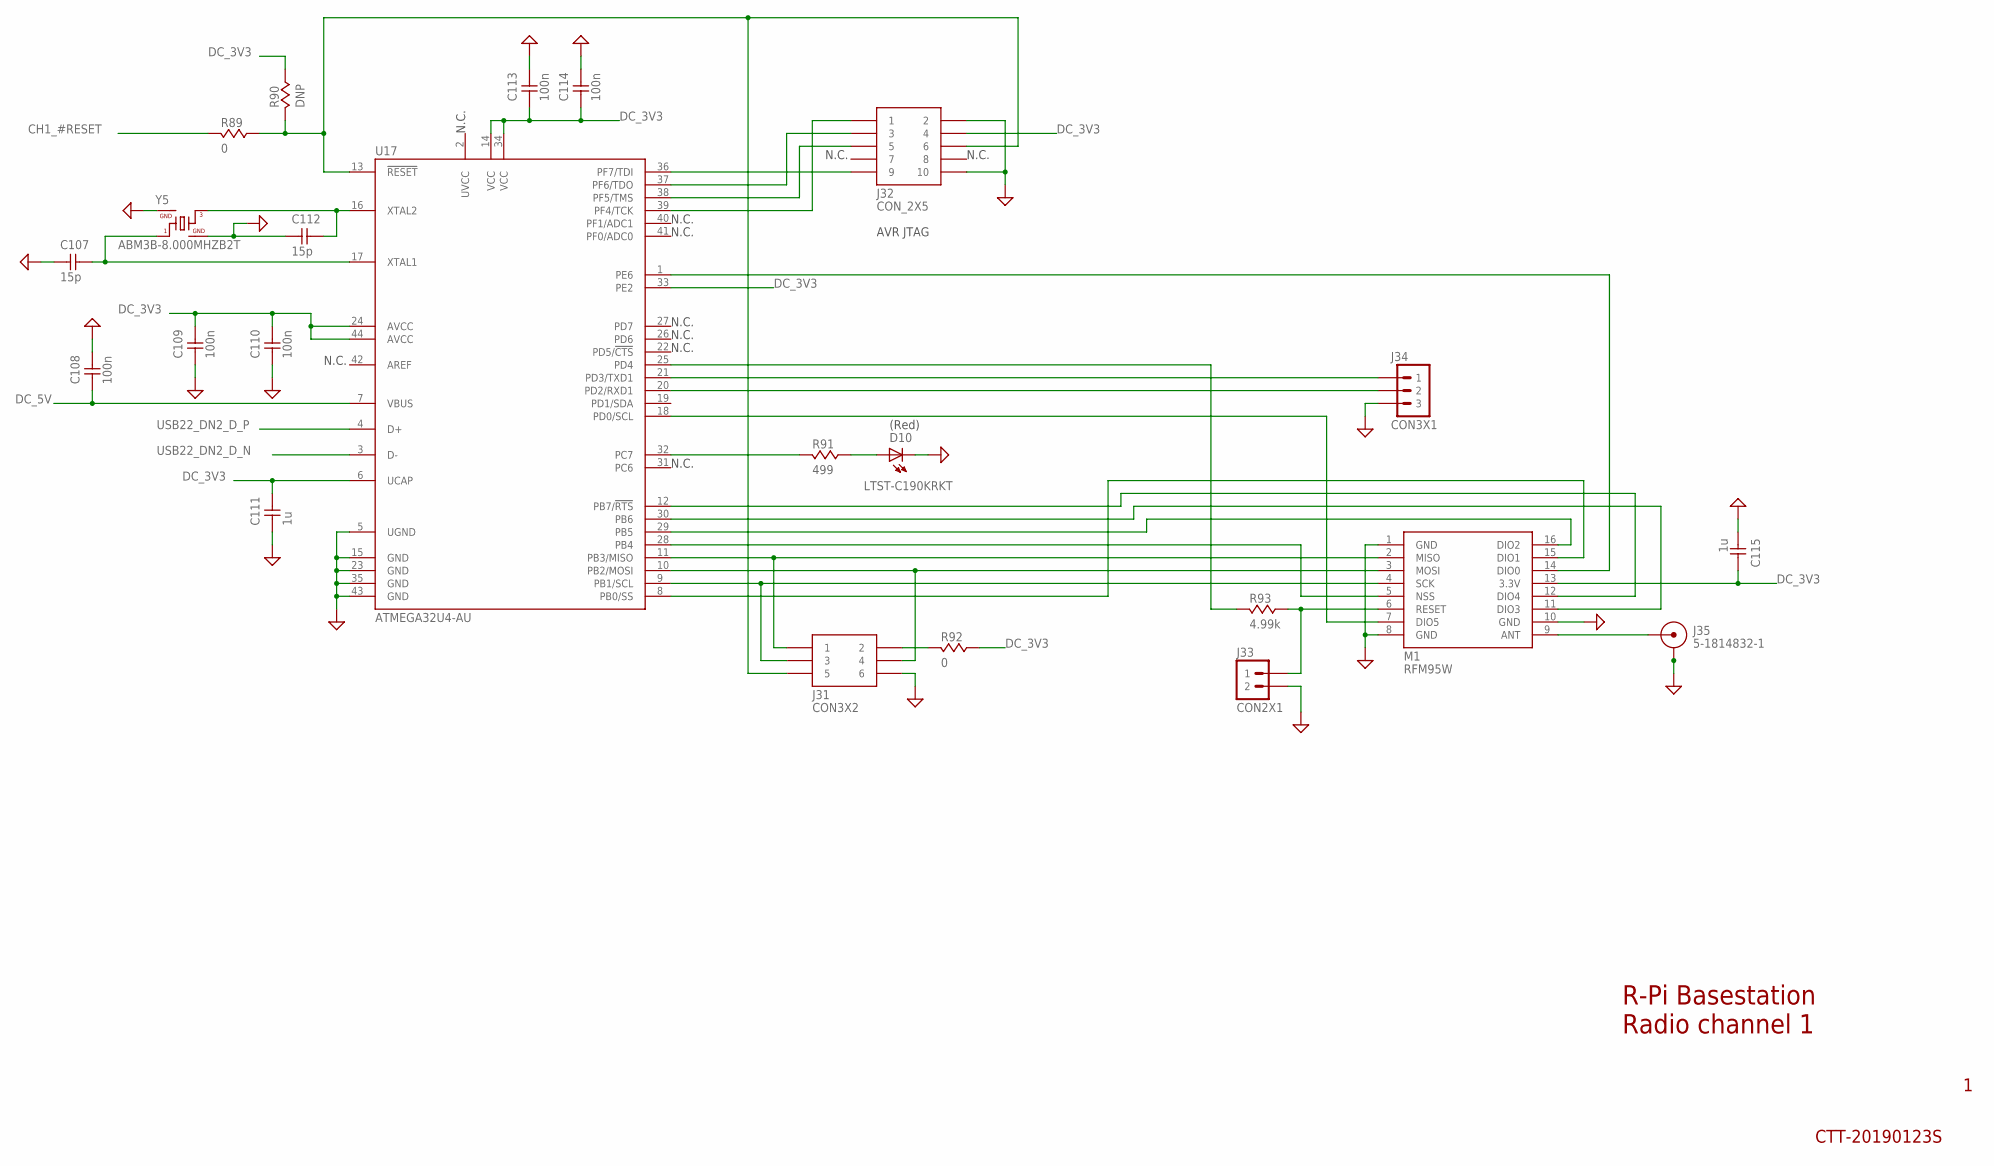
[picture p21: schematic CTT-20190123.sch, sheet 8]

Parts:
C107, C112: 15p; C0402_IPC7351_MED
C108, C109, C110, C113, C114: 100n; C0402_IPC7351_MED
C111, C115: 1u; C0603_IPC7351_MED
D10: LTST-C190KRKT; LED0603
J31: CON3X2
J32: CON_2X5; CON_5X2
J33: CON2X1
J34: CON3X1
J35: 5-1814832-1; CON_SMA_TH_VERT
M1: RFM95W
R89, R92: 0; R0402_IPC7351_MED
R90: DNP; R0402_IPC7351_MED
R91: 499; R0402_IPC7351_MED
R93: 4.99k; R0402_IPC7351_MED
U17: ATMEGA32U4-AU; TQFP44
Y5: ABM3B-8.000MHZB2T; ABM3B

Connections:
CH1_#RESET: R89.P$2 (2); also elsewhere on the board
DC_3V3: C109.P$2 (2), C110.P$2 (2), C111.P$2 (2), C113.P$1 (1), C114.P$1 (1), C115.P$2 (2), J32.4, M1.13 (3.3V), R90.P$1 (1), R92.P$1 (1), U17.6 (UCAP), U17.14 (VCC), U17.24 (AVCC), U17.33 (PE2), U17.34 (VCC), U17.44 (AVCC); also elsewhere on the board
DC_5V: C108.P$1 (1), U17.7 (VBUS); also elsewhere on the board
GND: C107.P$1 (1), C108.P$2 (2), C109.P$1 (1), C110.P$1 (1), C111.P$1 (1), C112.P$1 (1), C113.P$2 (2), C114.P$2 (2), C115.P$1 (1), D10.K, J31.6, J32.2, J32.10, J33.2, J34.3, J35.P$1 (GND), J35.P$2 (GND), J35.P$3 (GND), J35.P$4 (GND), M1.1 (GND), M1.8 (GND), M1.10 (GND), U17.5 (UGND), U17.15 (GND), U17.23 (GND), U17.35 (GND), U17.43 (GND), Y5.2, Y5.4; also elsewhere on the board
unnamed: C112.P$2 (2), U17.16 (XTAL2), Y5.3
unnamed: J32.1, U17.39 (PF4/TCK)
unnamed: C107.P$2 (2), U17.17 (XTAL1), Y5.1
unnamed: J31.5, J32.6, R89.P$1 (1), R90.P$2 (2), U17.13 (!RESET)
unnamed: J32.5, U17.38 (PF5/TMS)
unnamed: J32.3, U17.37 (PF6/TDO)
unnamed: J32.9, U17.36 (PF7/TDI)
unnamed: J31.1, M1.2 (MISO), U17.11 (PB3/MISO)
unnamed: J35.C (SIG), M1.9 (ANT)
unnamed: J31.4, M1.3 (MOSI), U17.10 (PB2/MOSI)
unnamed: J31.3, M1.4 (SCK), U17.9 (PB1/SCL)
unnamed: J33.1, M1.6 (RESET), R93.P$1 (1)
unnamed: R93.P$2 (2), U17.25 (PD4)
unnamed: J34.1, U17.21 (PD3/TXD1)
unnamed: J34.2, U17.20 (PD2/RXD1)
unnamed: J31.2, R92.P$2 (2)
unnamed: M1.5 (NSS), U17.28 (PB4)
unnamed: M1.16 (DIO2), U17.29 (PB5)
unnamed: M1.11 (DIO3), U17.30 (PB6)
unnamed: M1.12 (DIO4), U17.12 (PB7/!RTS)
unnamed: M1.7 (DIO5), U17.18 (PD0/SCL)
unnamed: M1.14 (DIO0), U17.1 (PE6)
unnamed: M1.15 (DIO1), U17.8 (PB0/SS)
unnamed: R91.P$2 (2), U17.32 (PC7)
unnamed: D10.A, R91.P$1 (1)
USB22_DN2_D_N: U17.3 (D-); also elsewhere on the board
USB22_DN2_D_P: U17.4 (D+); also elsewhere on the board

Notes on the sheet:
N.C.
R-Pi Basestation Radio channel 1
CTT-20190123S
(Red)
AVR JTAG

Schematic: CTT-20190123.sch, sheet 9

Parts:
C116, C121: 15p; C0402_IPC7351_MED
C117, C118, C119, C122, C123: 100n; C0402_IPC7351_MED
C120, C124: 1u; C0603_IPC7351_MED
D11: LTST-C190KRKT; LED0603
J36: CON3X2
J37: CON_2X5; CON_5X2
J38: CON2X1
J39: CON3X1
J40: 5-1814832-1; CON_SMA_TH_VERT
M2: RFM95W
R94, R97: 0; R0402_IPC7351_MED
R95: DNP; R0402_IPC7351_MED
R96: 499; R0402_IPC7351_MED
R98: 4.99k; R0402_IPC7351_MED
U18: ATMEGA32U4-AU; TQFP44
Y6: ABM3B-8.000MHZB2T; ABM3B

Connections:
CH2_#RESET: R94.P$2 (2); also elsewhere on the board
DC_3V3: C118.P$2 (2), C119.P$2 (2), C120.P$2 (2), C122.P$1 (1), C123.P$1 (1), C124.P$2 (2), J37.4, M2.13 (3.3V), R95.P$1 (1), R97.P$1 (1), U18.6 (UCAP), U18.14 (VCC), U18.24 (AVCC), U18.33 (PE2), U18.34 (VCC), U18.44 (AVCC); also elsewhere on the board
DC_5V: C117.P$1 (1), U18.7 (VBUS); also elsewhere on the board
GND: C116.P$1 (1), C117.P$2 (2), C118.P$1 (1), C119.P$1 (1), C120.P$1 (1), C121.P$1 (1), C122.P$2 (2), C123.P$2 (2), C124.P$1 (1), D11.K, J36.6, J37.2, J37.10, J38.2, J39.3, J40.P$1 (GND), J40.P$2 (GND), J40.P$3 (GND), J40.P$4 (GND), M2.1 (GND), M2.8 (GND), M2.10 (GND), U18.5 (UGND), U18.15 (GND), U18.23 (GND), U18.35 (GND), U18.43 (GND), Y6.2, Y6.4; also elsewhere on the board
unnamed: C121.P$2 (2), U18.16 (XTAL2), Y6.3
unnamed: C116.P$2 (2), U18.17 (XTAL1), Y6.1
unnamed: J36.5, J37.6, R94.P$1 (1), R95.P$2 (2), U18.13 (!RESET)
unnamed: J37.1, U18.39 (PF4/TCK)
unnamed: J37.5, U18.38 (PF5/TMS)
unnamed: J37.3, U18.37 (PF6/TDO)
unnamed: J37.9, U18.36 (PF7/TDI)
unnamed: J40.C (SIG), M2.9 (ANT)
unnamed: J36.1, M2.2 (MISO), U18.11 (PB3/MISO)
unnamed: J36.4, M2.3 (MOSI), U18.10 (PB2/MOSI)
unnamed: J36.3, M2.4 (SCK), U18.9 (PB1/SCL)
unnamed: J38.1, M2.6 (RESET), R98.P$1 (1)
unnamed: R98.P$2 (2), U18.25 (PD4)
unnamed: J39.1, U18.21 (PD3/TXD1)
unnamed: J39.2, U18.20 (PD2/RXD1)
unnamed: J36.2, R97.P$2 (2)
unnamed: M2.5 (NSS), U18.28 (PB4)
unnamed: M2.16 (DIO2), U18.29 (PB5)
unnamed: M2.11 (DIO3), U18.30 (PB6)
unnamed: M2.12 (DIO4), U18.12 (PB7/!RTS)
unnamed: M2.7 (DIO5), U18.18 (PD0/SCL)
unnamed: M2.14 (DIO0), U18.1 (PE6)
unnamed: M2.15 (DIO1), U18.8 (PB0/SS)
unnamed: R96.P$2 (2), U18.32 (PC7)
unnamed: D11.A, R96.P$1 (1)
USB23_DN1_D_N: U18.3 (D-); also elsewhere on the board
USB23_DN1_D_P: U18.4 (D+); also elsewhere on the board

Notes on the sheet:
N.C.
R-Pi Basestation Radio channel 2
CTT-20190123S
(Red)
AVR JTAG

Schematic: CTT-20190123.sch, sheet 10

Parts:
C125, C130: 15p; C0402_IPC7351_MED
C126, C127, C128, C131, C132: 100n; C0402_IPC7351_MED
C129, C133: 1u; C0603_IPC7351_MED
D12: LTST-C190KRKT; LED0603
J41: CON3X2
J42: CON_2X5; CON_5X2
J43: CON2X1
J44: CON3X1
J45: 5-1814832-1; CON_SMA_TH_VERT
M3: RFM95W
R99, R102: 0; R0402_IPC7351_MED
R100: DNP; R0402_IPC7351_MED
R101: 499; R0402_IPC7351_MED
R103: 4.99k; R0402_IPC7351_MED
U19: ATMEGA32U4-AU; TQFP44
Y7: ABM3B-8.000MHZB2T; ABM3B

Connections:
CH3_#RESET: R99.P$2 (2); also elsewhere on the board
DC_3V3: C127.P$2 (2), C128.P$2 (2), C129.P$2 (2), C131.P$1 (1), C132.P$1 (1), C133.P$2 (2), J42.4, M3.13 (3.3V), R100.P$1 (1), R102.P$1 (1), U19.6 (UCAP), U19.14 (VCC), U19.24 (AVCC), U19.33 (PE2), U19.34 (VCC), U19.44 (AVCC); also elsewhere on the board
DC_5V: C126.P$1 (1), U19.7 (VBUS); also elsewhere on the board
GND: C125.P$1 (1), C126.P$2 (2), C127.P$1 (1), C128.P$1 (1), C129.P$1 (1), C130.P$1 (1), C131.P$2 (2), C132.P$2 (2), C133.P$1 (1), D12.K, J41.6, J42.2, J42.10, J43.2, J44.3, J45.P$1 (GND), J45.P$2 (GND), J45.P$3 (GND), J45.P$4 (GND), M3.1 (GND), M3.8 (GND), M3.10 (GND), U19.5 (UGND), U19.15 (GND), U19.23 (GND), U19.35 (GND), U19.43 (GND), Y7.2, Y7.4; also elsewhere on the board
unnamed: C130.P$2 (2), U19.16 (XTAL2), Y7.3
unnamed: C125.P$2 (2), U19.17 (XTAL1), Y7.1
unnamed: J41.5, J42.6, R99.P$1 (1), R100.P$2 (2), U19.13 (!RESET)
unnamed: J42.1, U19.39 (PF4/TCK)
unnamed: J42.5, U19.38 (PF5/TMS)
unnamed: J42.3, U19.37 (PF6/TDO)
unnamed: J42.9, U19.36 (PF7/TDI)
unnamed: J45.C (SIG), M3.9 (ANT)
unnamed: J41.1, M3.2 (MISO), U19.11 (PB3/MISO)
unnamed: J41.4, M3.3 (MOSI), U19.10 (PB2/MOSI)
unnamed: J41.3, M3.4 (SCK), U19.9 (PB1/SCL)
unnamed: J43.1, M3.6 (RESET), R103.P$1 (1)
unnamed: R103.P$2 (2), U19.25 (PD4)
unnamed: J44.1, U19.21 (PD3/TXD1)
unnamed: J44.2, U19.20 (PD2/RXD1)
unnamed: J41.2, R102.P$2 (2)
unnamed: M3.5 (NSS), U19.28 (PB4)
unnamed: M3.16 (DIO2), U19.29 (PB5)
unnamed: M3.11 (DIO3), U19.30 (PB6)
unnamed: M3.12 (DIO4), U19.12 (PB7/!RTS)
unnamed: M3.7 (DIO5), U19.18 (PD0/SCL)
unnamed: M3.14 (DIO0), U19.1 (PE6)
unnamed: M3.15 (DIO1), U19.8 (PB0/SS)
unnamed: R101.P$2 (2), U19.32 (PC7)
unnamed: D12.A, R101.P$1 (1)
USB23_DN2_D_N: U19.3 (D-); also elsewhere on the board
USB23_DN2_D_P: U19.4 (D+); also elsewhere on the board

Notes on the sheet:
N.C.
R-Pi Basestation Radio channel 3
CTT-20190123S
(Red)
AVR JTAG

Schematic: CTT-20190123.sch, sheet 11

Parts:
C134, C139: 15p; C0402_IPC7351_MED
C135, C136, C137, C140, C141: 100n; C0402_IPC7351_MED
C138, C142: 1u; C0603_IPC7351_MED
D13: LTST-C190KRKT; LED0603
J46: CON3X2
J47: CON_2X5; CON_5X2
J48: CON2X1
J49: CON3X1
J50: 5-1814832-1; CON_SMA_TH_VERT
M4: RFM95W
R104, R107: 0; R0402_IPC7351_MED
R105: DNP; R0402_IPC7351_MED
R106: 499; R0402_IPC7351_MED
R108: 4.99k; R0402_IPC7351_MED
U20: ATMEGA32U4-AU; TQFP44
Y8: ABM3B-8.000MHZB2T; ABM3B

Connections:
CH4_#RESET: R104.P$2 (2); also elsewhere on the board
DC_3V3: C136.P$2 (2), C137.P$2 (2), C138.P$2 (2), C140.P$1 (1), C141.P$1 (1), C142.P$2 (2), J47.4, M4.13 (3.3V), R105.P$1 (1), R107.P$1 (1), U20.6 (UCAP), U20.14 (VCC), U20.24 (AVCC), U20.33 (PE2), U20.34 (VCC), U20.44 (AVCC); also elsewhere on the board
DC_5V: C135.P$1 (1), U20.7 (VBUS); also elsewhere on the board
GND: C134.P$1 (1), C135.P$2 (2), C136.P$1 (1), C137.P$1 (1), C138.P$1 (1), C139.P$1 (1), C140.P$2 (2), C141.P$2 (2), C142.P$1 (1), D13.K, J46.6, J47.2, J47.10, J48.2, J49.3, J50.P$1 (GND), J50.P$2 (GND), J50.P$3 (GND), J50.P$4 (GND), M4.1 (GND), M4.8 (GND), M4.10 (GND), U20.5 (UGND), U20.15 (GND), U20.23 (GND), U20.35 (GND), U20.43 (GND), Y8.2, Y8.4; also elsewhere on the board
unnamed: C139.P$2 (2), U20.16 (XTAL2), Y8.3
unnamed: C134.P$2 (2), U20.17 (XTAL1), Y8.1
unnamed: J46.5, J47.6, R104.P$1 (1), R105.P$2 (2), U20.13 (!RESET)
unnamed: J47.1, U20.39 (PF4/TCK)
unnamed: J47.5, U20.38 (PF5/TMS)
unnamed: J47.3, U20.37 (PF6/TDO)
unnamed: J47.9, U20.36 (PF7/TDI)
unnamed: J50.C (SIG), M4.9 (ANT)
unnamed: J46.1, M4.2 (MISO), U20.11 (PB3/MISO)
unnamed: J46.4, M4.3 (MOSI), U20.10 (PB2/MOSI)
unnamed: J46.3, M4.4 (SCK), U20.9 (PB1/SCL)
unnamed: J48.1, M4.6 (RESET), R108.P$1 (1)
unnamed: R108.P$2 (2), U20.25 (PD4)
unnamed: J49.1, U20.21 (PD3/TXD1)
unnamed: J49.2, U20.20 (PD2/RXD1)
unnamed: J46.2, R107.P$2 (2)
unnamed: M4.5 (NSS), U20.28 (PB4)
unnamed: M4.16 (DIO2), U20.29 (PB5)
unnamed: M4.11 (DIO3), U20.30 (PB6)
unnamed: M4.12 (DIO4), U20.12 (PB7/!RTS)
unnamed: M4.7 (DIO5), U20.18 (PD0/SCL)
unnamed: M4.14 (DIO0), U20.1 (PE6)
unnamed: M4.15 (DIO1), U20.8 (PB0/SS)
unnamed: R106.P$2 (2), U20.32 (PC7)
unnamed: D13.A, R106.P$1 (1)
USB23_DN3_D_N: U20.3 (D-); also elsewhere on the board
USB23_DN3_D_P: U20.4 (D+); also elsewhere on the board

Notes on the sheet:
N.C.
R-Pi Basestation Radio channel 4
CTT-20190123S
(Red)
AVR JTAG

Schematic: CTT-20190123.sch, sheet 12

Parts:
C143, C148: 15p; C0402_IPC7351_MED
C144, C145, C146, C149, C150: 100n; C0402_IPC7351_MED
C147, C151: 1u; C0603_IPC7351_MED
D14: LTST-C190KRKT; LED0603
J51: CON3X2
J52: CON_2X5; CON_5X2
J53: CON2X1
J54: CON3X1
J55: 5-1814832-1; CON_SMA_TH_VERT
M5: RFM95W
R109, R112: 0; R0402_IPC7351_MED
R110: DNP; R0402_IPC7351_MED
R111: 499; R0402_IPC7351_MED
R113: 4.99k; R0402_IPC7351_MED
U21: ATMEGA32U4-AU; TQFP44
Y9: ABM3B-8.000MHZB2T; ABM3B

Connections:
CH5_#RESET: R109.P$2 (2); also elsewhere on the board
DC_3V3: C145.P$2 (2), C146.P$2 (2), C147.P$2 (2), C149.P$1 (1), C150.P$1 (1), C151.P$2 (2), J52.4, M5.13 (3.3V), R110.P$1 (1), R112.P$1 (1), U21.6 (UCAP), U21.14 (VCC), U21.24 (AVCC), U21.33 (PE2), U21.34 (VCC), U21.44 (AVCC); also elsewhere on the board
DC_5V: C144.P$1 (1), U21.7 (VBUS); also elsewhere on the board
GND: C143.P$1 (1), C144.P$2 (2), C145.P$1 (1), C146.P$1 (1), C147.P$1 (1), C148.P$1 (1), C149.P$2 (2), C150.P$2 (2), C151.P$1 (1), D14.K, J51.6, J52.2, J52.10, J53.2, J54.3, J55.P$1 (GND), J55.P$2 (GND), J55.P$3 (GND), J55.P$4 (GND), M5.1 (GND), M5.8 (GND), M5.10 (GND), U21.5 (UGND), U21.15 (GND), U21.23 (GND), U21.35 (GND), U21.43 (GND), Y9.2, Y9.4; also elsewhere on the board
unnamed: C148.P$2 (2), U21.16 (XTAL2), Y9.3
unnamed: C143.P$2 (2), U21.17 (XTAL1), Y9.1
unnamed: J51.5, J52.6, R109.P$1 (1), R110.P$2 (2), U21.13 (!RESET)
unnamed: J52.1, U21.39 (PF4/TCK)
unnamed: J52.5, U21.38 (PF5/TMS)
unnamed: J52.3, U21.37 (PF6/TDO)
unnamed: J52.9, U21.36 (PF7/TDI)
unnamed: J55.C (SIG), M5.9 (ANT)
unnamed: J51.1, M5.2 (MISO), U21.11 (PB3/MISO)
unnamed: J51.4, M5.3 (MOSI), U21.10 (PB2/MOSI)
unnamed: J51.3, M5.4 (SCK), U21.9 (PB1/SCL)
unnamed: J53.1, M5.6 (RESET), R113.P$1 (1)
unnamed: R113.P$2 (2), U21.25 (PD4)
unnamed: J54.1, U21.21 (PD3/TXD1)
unnamed: J54.2, U21.20 (PD2/RXD1)
unnamed: J51.2, R112.P$2 (2)
unnamed: M5.5 (NSS), U21.28 (PB4)
unnamed: M5.16 (DIO2), U21.29 (PB5)
unnamed: M5.11 (DIO3), U21.30 (PB6)
unnamed: M5.12 (DIO4), U21.12 (PB7/!RTS)
unnamed: M5.7 (DIO5), U21.18 (PD0/SCL)
unnamed: M5.14 (DIO0), U21.1 (PE6)
unnamed: M5.15 (DIO1), U21.8 (PB0/SS)
unnamed: R111.P$2 (2), U21.32 (PC7)
unnamed: D14.A, R111.P$1 (1)
USB23_DN4_D_N: U21.3 (D-); also elsewhere on the board
USB23_DN4_D_P: U21.4 (D+); also elsewhere on the board

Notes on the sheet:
N.C.
R-Pi Basestation Radio channel 5
CTT-20190123S
(Red)
AVR JTAG

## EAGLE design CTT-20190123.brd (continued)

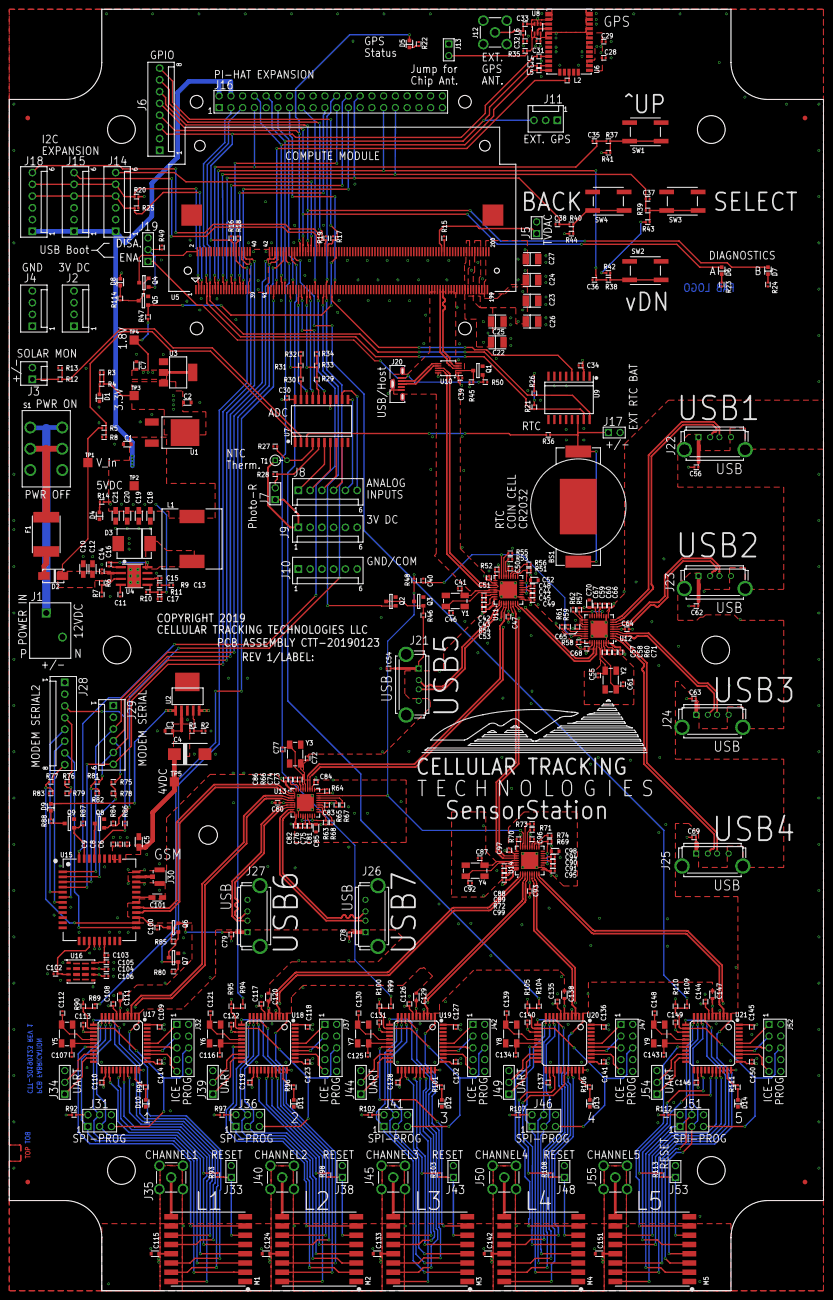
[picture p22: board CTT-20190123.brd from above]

Board: 4 copper layers, 176.0 x 277.0 mm, 412 parts (0 on the bottom side), 334 nets.

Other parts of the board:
U$1: HEX_8MM
U$2: CTT-LOGO_W2INCH
U$138, U$140, U$247, U$248: FIDUCIAL
U$240, U$241, U$242, U$243, U$244, U$245: FUNCUBE_ENVELOPE_VERT
U$246: PI_HAT_OUTLINE
U$249: BORDER_C_DOCU

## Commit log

2019-08-16 Adding first production version of SensorStation
    [CTT-20190123.brd, CTT-20190123.sch]
2019-08-16 Adding PDF of SensorStation Schematic
2019-08-16 Picture of SensorStation

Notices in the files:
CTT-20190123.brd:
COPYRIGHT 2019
